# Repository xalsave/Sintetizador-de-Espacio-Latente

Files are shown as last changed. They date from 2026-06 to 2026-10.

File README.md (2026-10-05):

# Sintetizador de Espacio Latente

> Sintetizador digital embebido que genera timbres mediante interpolación
> neuronal de wavetables. Trabajo Fin de Grado, Grado en Ingeniería de
> Tecnologías y Servicios de Telecomunicación (GTIST), Universitat Politècnica
> de València.

<p align="center">
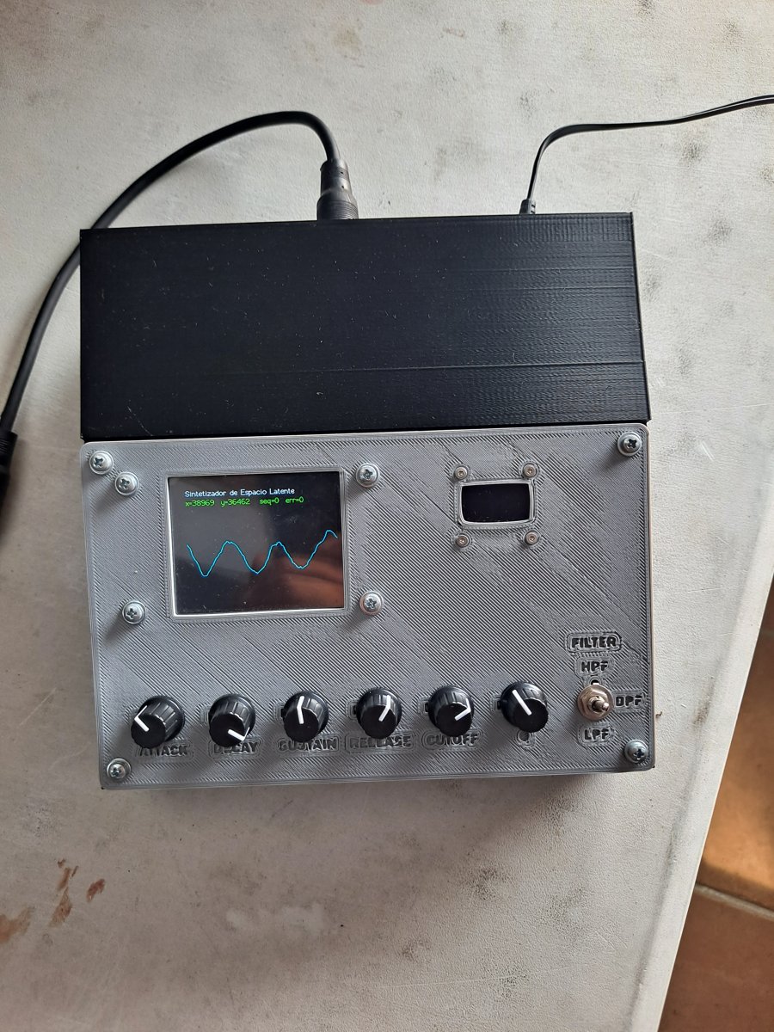
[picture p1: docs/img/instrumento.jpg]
El instrumento terminado: pantalla táctil, OLED y panel de mandos sobre una carcasa impresa en 3D
  
</p>

📄 **Memoria completa del TFG:** [Desarrollo de un sintetizador de sonido embebido basado en síntesis wavetable e inteligencia artificial (PDF)](memoria_tfg.pdf)

---

## Resumen

Este proyecto desarrolla un instrumento musical electrónico autónomo que
utiliza un **autoencoder variacional (VAE)** para organizar un corpus de
formas de onda de un ciclo en un **espacio latente bidimensional continuo**.
El intérprete navega por ese espacio tocando un punto en una pantalla táctil;
el sistema sintetiza en tiempo real una wavetable interpolada entre las
formas de onda aprendidas y la reproduce con control MIDI desde un teclado.

A diferencia de los sintetizadores wavetable tradicionales, donde el intérprete
selecciona una de N tablas predefinidas, este sistema permite explorar de
forma continua un mapa de timbres donde **cada punto produce una onda
distinta**. Las tablas salen del decoder del modelo aprendido, que se ejecuta
una sola vez en el ordenador; en el instrumento solo hay consulta de tabla e
interpolación.

---

## Demostración del concepto

<p align="center">
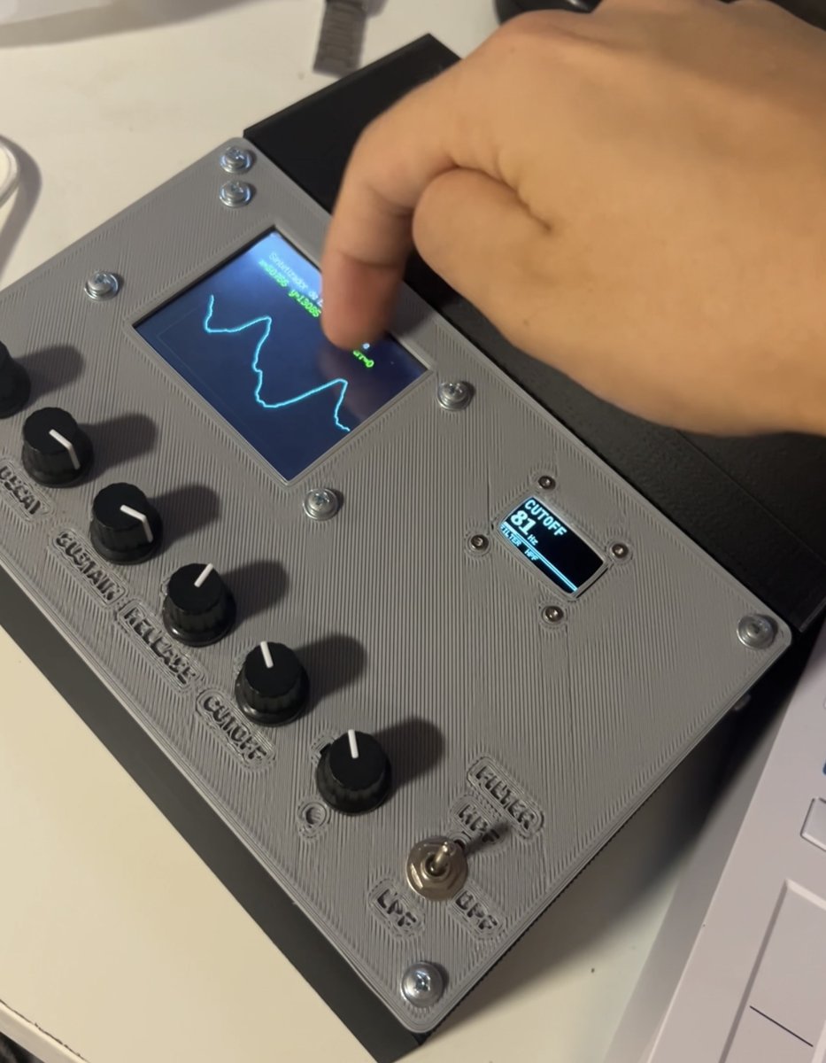
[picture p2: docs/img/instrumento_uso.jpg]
Un dedo recorre la pantalla táctil mientras se dibuja la onda resultante
  
</p>

El intérprete recorre el plano con el dedo y oye el timbre transformarse de
forma continua entre todas las familias del dataset (cuerdas, vientos,
sintéticos, ruidos, etc.) sin saltos perceptibles. La pantalla dibuja la onda
que está sonando y el OLED muestra el último mando movido.

---

## Arquitectura del sistema

Tres microcontroladores con roles especializados, comunicados por buses
serie estándar:

<p align="center">
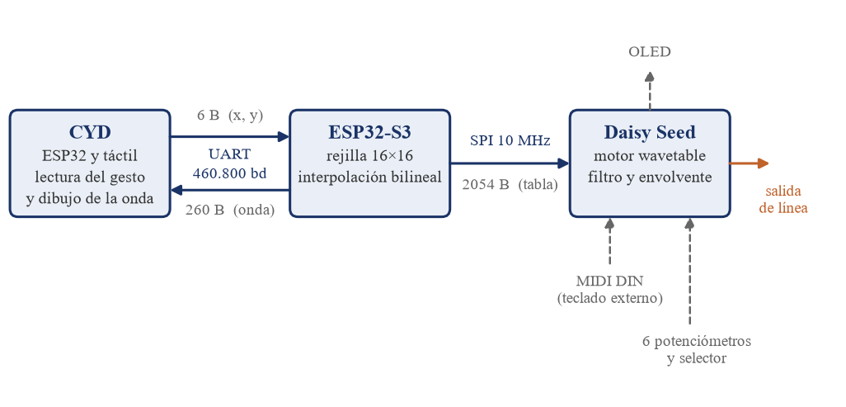
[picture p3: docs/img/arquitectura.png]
Diagrama de bloques: CYD, ESP32-S3 y Daisy Seed, con MIDI, panel y salida de audio
  
</p>

| Subsistema | Hardware | Función |
|---|---|---|
| Interfaz táctil  | CYD (ESP32-2432S028R) | Pantalla TFT 2.8" + táctil resistivo XPT2046  |
| Cerebro | ESP32-S3 N16R8 | Grid 16×16 en flash, interpolación bilineal |
| Motor de audio | Daisy Seed (STM32H750) | Síntesis, filtro, envolvente, MIDI, audio out |
| Control MIDI | Arturia Keystep MK2 | Teclado controlador por DIN |
| Panel analógico  | 6 potenciómetros + selector | ADSR, corte, resonancia y tipo de filtro |
| Display | OLED SSD1306 128×64 | Parámetro en edición y curva correspondiente  |

El enlace con la CYD es full-duplex: la coordenada táctil sube al ESP32-S3 en
una trama de 6 bytes, y el ESP32-S3 devuelve la onda resultante diezmada a 256
puntos de 8 bits para que la pantalla la dibuje. Esa onda de vuelta es dato de
representación, no de audio: la wavetable real de 1024 muestras solo viaja por
el SPI hacia el Daisy, en tramas de 2054 bytes protegidas con CRC16-CCITT.

---

## Cómo funciona

El sistema trabaja en dos fases: la red neuronal solo interviene en la de
preparación, en el ordenador, y el instrumento se limita a leer lo que ella
dejó horneado.

<p align="center">
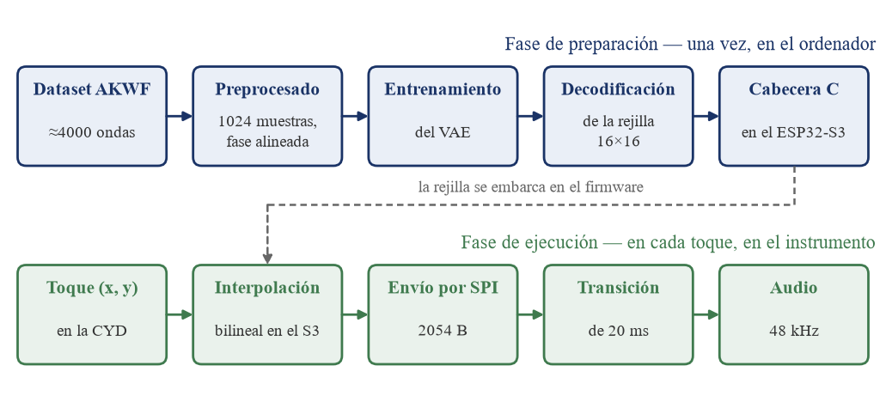
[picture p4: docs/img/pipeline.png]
Las dos fases: preparación en el ordenador y ejecución en el instrumento
  
</p>

### Fase offline (preparación, en PC)

1. **Preprocesado del dataset.** Se cargan las 4358 wavetables del corpus AKWF
   (Adventure Kid Waveforms), se remuestrean de 600 a 1024 muestras por FFT, se
   elimina la componente continua, se alinea el armónico fundamental a fase 0 y
   se normaliza por pico.
2. **Entrenamiento del VAE.** Autoencoder variacional totalmente conectado en
   PyTorch, con encoder 1024 → 512 → 128 → latente 2D y decoder espejo. La
   pérdida combina error cuadrático de reconstrucción y divergencia KL con un
   peso pequeño y rampa de calentamiento.

<p align="center">
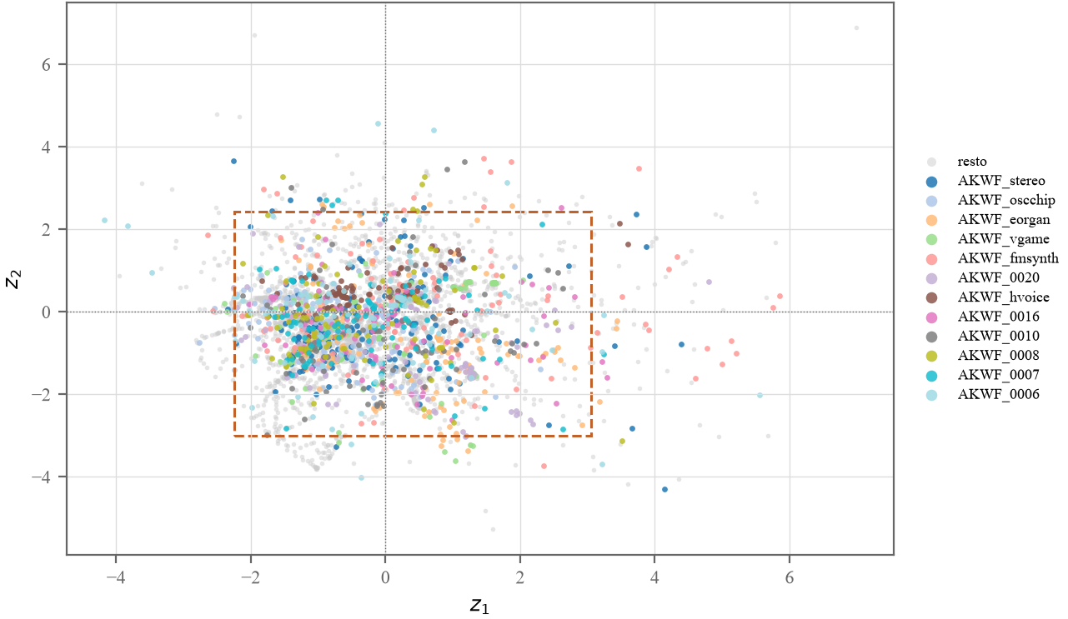
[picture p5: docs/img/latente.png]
Espacio latente 2D: cada punto es una onda del dataset, coloreada por familia
  
  <br>
  <em>Espacio latente aprendido. Cada punto es una onda del corpus; el rectángulo a trazos delimita los percentiles 2 y 98 de cada eje, la zona que se muestrea para la rejilla.</em>
</p>

<p align="center">
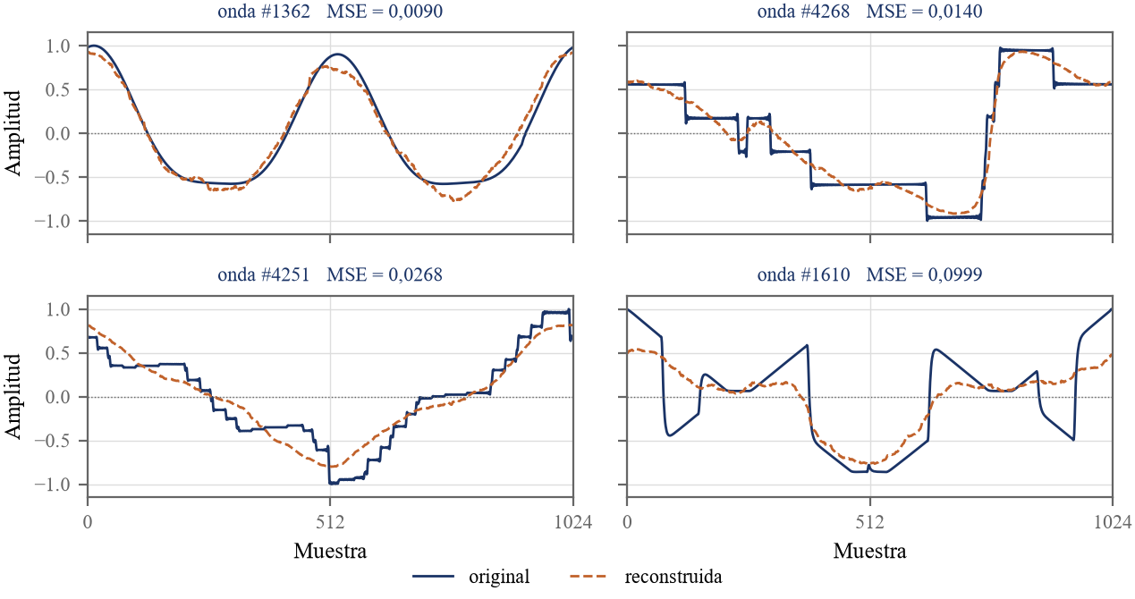
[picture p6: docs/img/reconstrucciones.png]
Cuatro ondas originales frente a su reconstrucción por el VAE
  
  <br>
  <em>Ondas originales frente a su reconstrucción. El cuello de botella de dos dimensiones conserva la forma general y redondea los flancos verticales.</em>
</p>

3. **Horneado del grid.** Se acota la zona poblada del latente por percentiles,
   se muestrea una rejilla regular de 16×16 = 256 puntos, se decodifica una
   wavetable en cada nodo y se exporta el banco como header de C en formato Q15,
   unos 512 KB en la flash del ESP32-S3.

<p align="center">
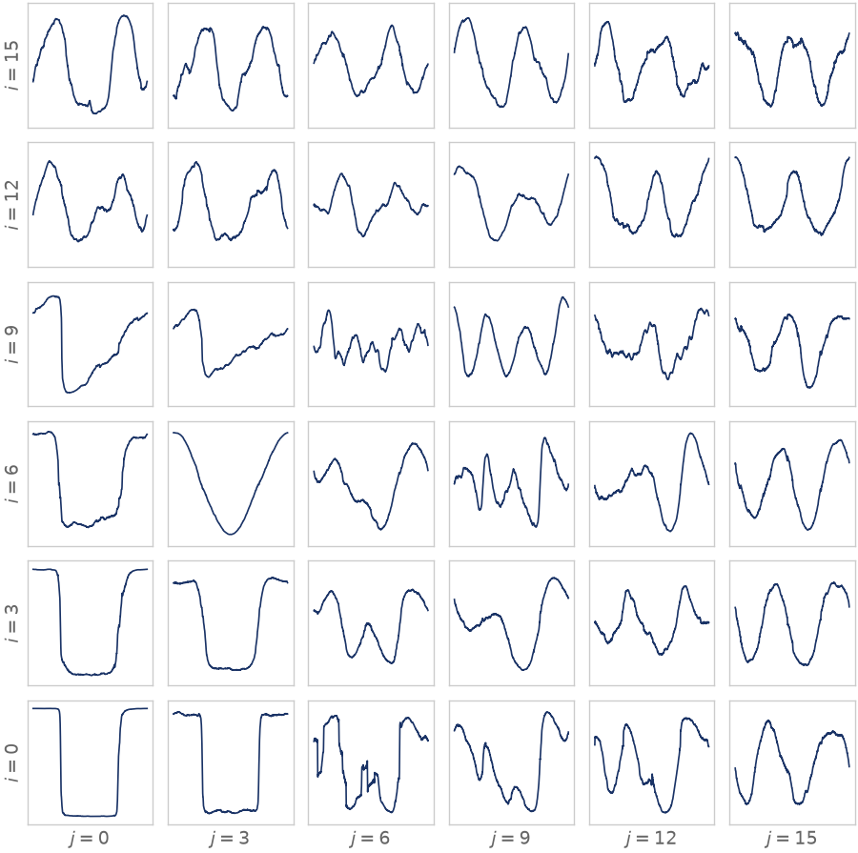
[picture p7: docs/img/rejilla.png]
Muestra de las ondas de la rejilla 16×16, una de cada tres filas y columnas
  
  <br>
  <em>Contenido de la rejilla, uno de cada tres nodos en cada eje: la variedad de formas repartida por el plano.</em>
</p>

La red **no se ejecuta en el instrumento**. Toda la inferencia ocurre en esta
fase, de modo que en vivo no hay latencia de modelo.

### Fase en vivo (en el instrumento)

1. La CYD lee el punto tocado, lo normaliza al rango completo de 16 bits y envía
   la coordenada por UART al ESP32-S3.
2. El ESP32-S3 localiza la celda del grid e **interpola bilinealmente** entre
   las cuatro wavetables vecinas, produciendo una onda suave para cualquier
   coordenada continua.
3. La wavetable resultante viaja por SPI al Daisy Seed.
4. El Daisy mantiene un **doble buffer** y aplica un **crossfade de 20 ms** al
   recibir una tabla nueva, lo que elimina los clicks de cambio.
5. Un acumulador de fase con interpolación lineal entre muestras reproduce la
   tabla a la frecuencia que indica el MIDI entrante del Keystep. La señal pasa
   por un filtro variable de estado y una envolvente ADSR, y sale por el códec
   del Daisy a un jack de 3.5 mm.

<p align="center">
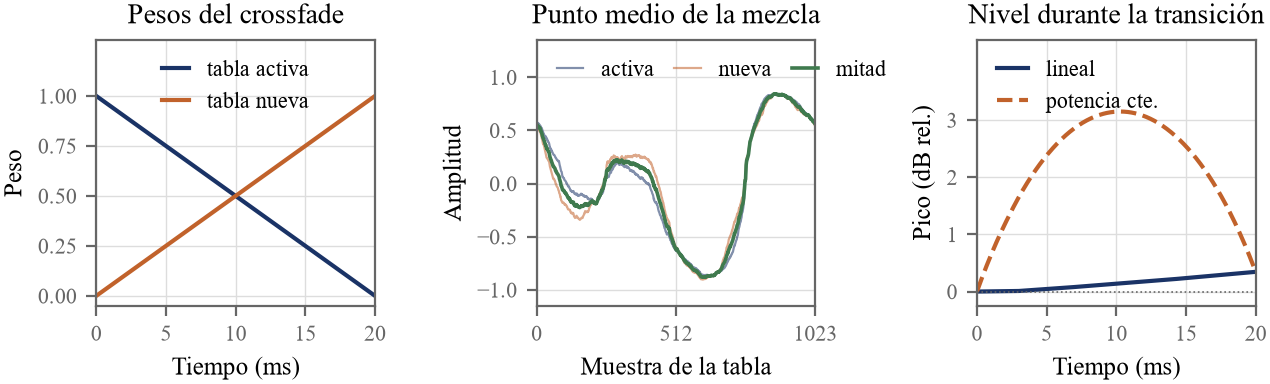
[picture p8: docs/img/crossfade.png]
Pesos del crossfade, punto medio de la mezcla y nivel durante la transición
  
  <br>
  <em>Transición entre dos tablas contiguas: pesos del fundido lineal, onda a mitad de mezcla y nivel de pico durante los 20 ms.</em>
</p>

### Panel de control

El Daisy lee siete canales analógicos: los cuatro tiempos y niveles del ADSR,
la frecuencia de corte, la resonancia y un selector de tres posiciones que
escoge entre filtro paso bajo, paso banda y paso alto. El OLED muestra el
último mando movido con su valor en unidades reales y la curva correspondiente,
la envolvente o la respuesta del filtro.

---

## Hardware

Las placas y el resto de componentes se montan sobre veroboard, con los
módulos en zócalos, y todo se alimenta desde una única fuente de 5 V. La
carcasa y el panel frontal están modelados de forma paramétrica en OpenSCAD e
impresos en 3D.

<p align="center">
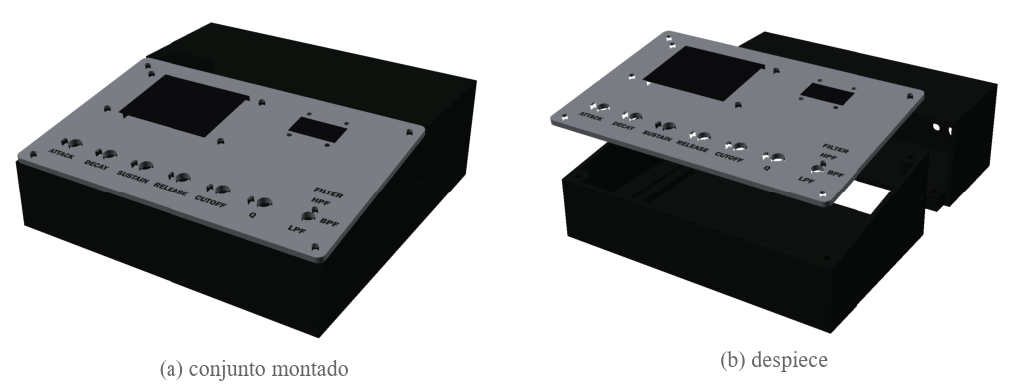
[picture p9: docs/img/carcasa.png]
Render de la carcasa: conjunto montado y despiece
  
</p>

---

## Estructura del repositorio

```
Sintetizador-de-Espacio-Latente/
├── ml/
│   ├── dataset/              # Corpus AKWF (.wav) y dataset procesado (.npy)
│   ├── scripts/              # Pipeline numerado por orden de ejecución
│   └── exports/              # vae.pt, grid.npy, grid.h y figuras del modelo
├── firmware/
│   ├── cyd_ui/               # PlatformIO — pantalla táctil (ESP32-WROOM)
│   ├── esp32_control/        # PlatformIO — grid e interpolación (ESP32-S3)
│   └── daisy_dsp/            # libDaisy — síntesis, MIDI y panel (STM32H750)
├── hardware/
│   ├── cad/                  # Carcasa y panel en OpenSCAD
│   └── schematics/           # Cableado y veroboard en Fritzing
├── docs/
│   └── img/                  # Fotos y figuras de este README
├── memoria_tfg.pdf           # Memoria del TFG
├── LICENSE
└── README.md
```

El firmware del Daisy se compila desde el árbol de DaisyExamples; la copia de
`firmware/daisy_dsp/` es la fuente de referencia versionada.

---

## Reproducir el pipeline

Los scripts de `ml/scripts/` están numerados por orden de ejecución y se lanzan
desde la raíz del repositorio:

```bash
python ml/scripts/2_build_dataset.py    # AKWF -> akwf_processed.npy
```

```bash
python ml/scripts/3_train_vae.py        # entrena el VAE -> vae.pt
```

```bash
python ml/scripts/4_bake_grid.py        # decodifica el grid -> grid.npy y grid.h
```

```bash
python ml/scripts/5_demo_morph.py       # demo del morphing con ratón, en PC
```

Requiere Python 3.10 o superior con PyTorch, NumPy, SciPy, Matplotlib y
`sounddevice` para la demo. El entrenamiento aprovecha CUDA si está disponible.

### Validación cruzada

Cada enlace de la cadena se comprueba contra una referencia calculada en NumPy,
en lugar de fiarlo al oído:

- `6_validate_s3.py` recalcula en el PC la wavetable que el ESP32-S3 volcó por
  serie y las compara muestra a muestra.
- `7_validate_spi.py` comprueba que lo que reproduce el Daisy es exactamente lo
  que el ESP32-S3 envió por SPI.
- `8_validate_midi.py` contrasta la tabla de conversión de nota MIDI a
  frecuencia y a incremento de fase del firmware con la fórmula teórica.
- `8b_monitor_midi.py` muestra en vivo los eventos que procesa el Daisy.

---

## Stack tecnológico

- **Machine learning:** Python 3.10+, PyTorch, NumPy, SciPy, Matplotlib
- **Firmware Daisy:** C++ con libDaisy y DaisySP, ARM GCC, flasheo por DFU
- **Firmware ESP32-S3 y CYD:** C++ sobre Arduino con PlatformIO
- **Comunicación:** UART 8N1 a 460800 baud entre CYD y ESP32-S3; SPI a 10 MHz
  en modo 0 entre ESP32-S3 y Daisy; MIDI DIN por USART1 con optoacoplador 6N138
- **Audio:** códec del Daisy a 48 kHz, señal mono replicada en ambos canales
- **Hardware:** veroboard, carcasa impresa en 3D modelada en OpenSCAD

---

## Estado del proyecto

**Completado.** El instrumento está montado, flasheado y verificado como
unidad, con los tres microcontroladores, el panel analógico, el display y la
carcasa definitiva. La memoria del TFG está en la raíz del repositorio, en
[PDF](memoria_tfg.pdf).

El decoder neuronal embarcado en el ESP32-S3 mediante TensorFlow Lite Micro se
estudió como ampliación y queda documentado como línea de trabajo futuro: la
versión final resuelve el timbre por interpolación bilineal sobre el grid
precalculado, que era el camino crítico del proyecto.

---

## Referencias

El proyecto se apoya en literatura previa de síntesis neuronal de audio:

- **Hantrakul & Yang (2018).** *Neural Wavetable: a playable wavetable
  synthesizer using neural networks.*
- **Engel et al. (Magenta, 2020).** *DDSP: Differentiable Digital Signal
  Processing.*
- **Caillon & Esling (IRCAM, 2021).** *RAVE: A variational autoencoder
  for fast and high-quality neural audio synthesis.*
- **Wavespace (2024).** *VAE-based wavetable generation with factorized
  latent space.*

La aportación diferencial de este TFG no reside en la técnica de interpolación
neuronal, ya explorada en plugins de DAW, sino en su **integración embebida
completa en tiempo real**, sobre hardware de bajo coste y con interfaz física
táctil y MIDI, llevando la idea de plugin de software a instrumento físico
autónomo.

---

## Autor

**Alejandro Saez Vega**
Grado en Ingeniería de Tecnologías y Servicios de Telecomunicación
Universitat Politècnica de València

Tutor del TFG: José Javier López Monfort

---

## Licencia

Código fuente bajo licencia MIT. Ver `LICENSE`.

El dataset AKWF (Adventure Kid Waveforms) se distribuye bajo Creative Commons
Zero (CC0) y se incluye en `ml/dataset/` para que el pipeline sea reproducible
tal cual. Su origen es [la web del autor](https://www.adventurekid.se/).

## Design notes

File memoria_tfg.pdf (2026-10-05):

# UNIVERSITAT POLITÈCNICA DE VALÈNCIA

# Escuela Técnica Superior de Ingeniería de Telecomunicación

# Desarrollo de un sintetizador de sonido embebido basado en síntesis wavetable e inteligencia artificial

# Trabajo Fin de Grado

# Grado en Ingeniería de Tecnologías y Servicios de Telecomunicación

## AUTOR/A: Saez Vega, Alejandro

## Tutor/a: López Monfort, José Javier

## CURSO ACADÉMICO: 2025/2026

## Resumen

Este Trabajo Fin de Grado presenta el diseño, construcción y validación de un sintetizador de sonido digital autónomo que combina la síntesis wavetable con un modelo de aprendizaje profundo. El usuario explora de forma continua un espacio de timbres aprendido con el dedo sobre una pantalla táctil, mientras toca las notas desde un teclado MIDI convencional.

El trabajo se divide en dos fases. En la primera, realizada en el ordenador, se entrena un autoencoder variacional con espacio latente bidimensional sobre un conjunto público de 4358 formas de onda de un ciclo, y con su decodificador se genera una rejilla de 256 tablas que se exporta al sistema embebido. En la segunda, el instrumento no ejecuta ninguna red: un ESP32-S3 interpola entre las tablas y una placa Daisy Seed, basada en un Cortex-M7, reproduce el resultado en tiempo real con transiciones sin discontinuidades, envolvente ADSR y filtro gobernados desde un panel analógico.

El prototipo se integra en una carcasa impresa en 3D con alimentación única. La cadena de datos se verifica muestra a muestra contra una referencia calculada en el ordenador y el aparato se caracteriza eléctricamente. Se recogen también las limitaciones encontradas y las líneas de continuación.

## Resum

Aquest Treball Final de Grau presenta el disseny, la construcció i la validació d’un sintetitzador de so digital autònom que combina la síntesi wavetable amb un model d’aprenentatge profund. L’usuari explora de manera contínua un espai de timbres aprés amb el dit sobre una pantalla tàctil, mentre toca les notes des d’un teclat MIDI convencional.

El treball es divideix en dues fases. En la primera, feta a l’ordinador, s’entrena un autoencoder variacional amb espai latent bidimensional sobre un conjunt públic de 4358 formes d’ona d’un cicle, i amb el seu descodificador es genera una graella de 256 taules que s’exporta al sistema encastat. En la segona, l’instrument no executa cap xarxa: un ESP32-S3 interpola entre les taules de la graella i una placa Daisy Seed, basada en un Cortex-M7, reprodueix el resultat en temps real amb transicions sense discontinuïtats, envolupant ADSR i filtre governats des d’un panell analògic.

El prototip s’integra en una carcassa impresa en 3D amb alimentació única. La cadena de dades es verifica mostra a mostra contra una referència calculada a l’ordinador i l’aparell es caracteritza elèctricament. S’arrepleguen també les limitacions trobades i les línies de continuació.

## Abstract

This Bachelor’s Thesis presents the design, construction and validation of a stand-alone digital sound synthesizer that combines wavetable synthesis with a deep learning model. The user explores a learned timbre space continuously with a finger on a touch screen, while playing notes from a conventional MIDI keyboard.

The work is divided into two phases. In the first, carried out on a computer, a variational autoencoder with a two-dimensional latent space is trained on a public set of 4358 single-cycle waveforms, and its decoder is used to bake a grid of 256 tables that is exported to the embedded system. In the second, the instrument runs no neural network at all: an ESP32-S3 interpolates between the tables of the grid, and a Daisy Seed board, built around a Cortex-M7, plays the result in real time with click-free table transitions, an ADSR envelope and a filter driven from an analogue control panel.

The prototype is housed in a 3D-printed enclosure with a single power supply. The data chain is verified sample by sample against a reference computed on the PC, and the device is characterised electrically. The limitations found and the lines of future work are also reported.

3

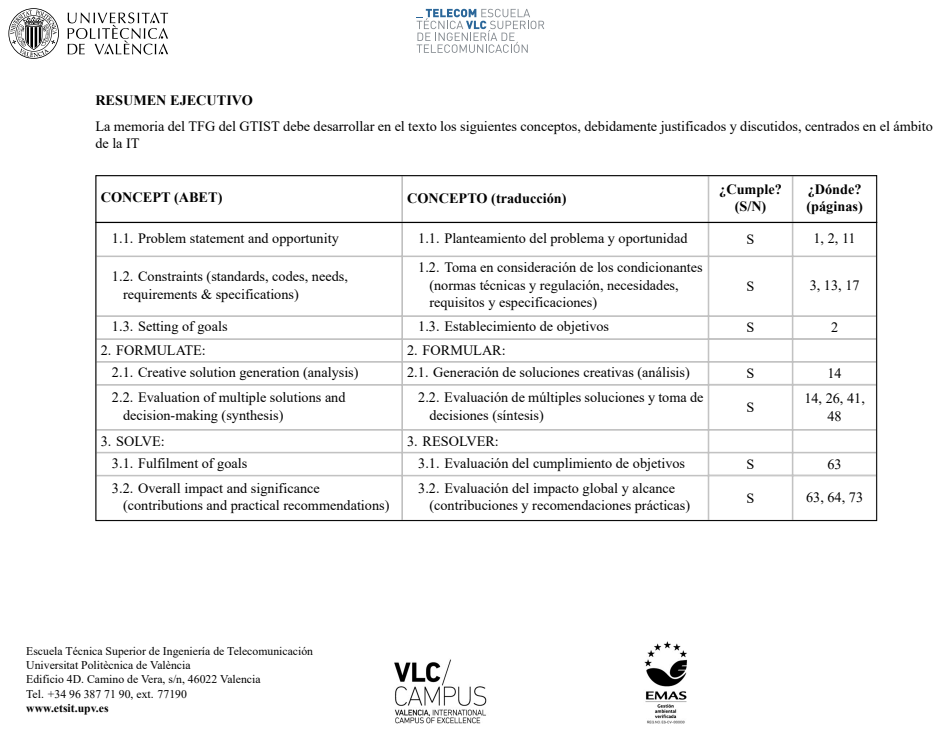
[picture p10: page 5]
RESUMEN EJECUTIVO; CONCEPT (ABET); CONCEPTO (traducción); ¿Cumple? (S/N); ¿Dónde? (páginas); 1.1. Problem statement and opportunity; 1.1. Planteamiento del problema y oportunidad; 1.3. Setting of goals; 1.3. Establecimiento de objetivos; 2. FORMULATE:; 2. FORMULAR:; 2.1. Creative solution generation (analysis); 2.1. Generación de soluciones creativas (análisis); decisiones (síntesis); 3. SOLVE:; 3. RESOLVER:; 3.1. Fulfilment of goals; 3.1. Evaluación del cumplimiento de objetivos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

La memoria del TFG del GTIST debe desarrollar en el texto los siguientes conceptos, debidamente justificados y discutidos, centrados en el ámbito

1.2. Toma en consideración de los condicionantes
(normas técnicas y regulación, necesidades,
requisitos y especificaciones)

1.2. Constraints (standards, codes, needs,
requirements & specifications)

2.2. Evaluation of multiple solutions and
decision-making (synthesis)

2.2. Evaluación de múltiples soluciones y toma de

3.2. Overall impact and significance
(contributions and practical recommendations)

3.2. Evaluación del impacto global y alcance

Escuela Técnica Superior de Ingeniería de Telecomunicación
Universitat Politècnica de València
Edificio 4D. Camino de Vera, s/n, 46022 Valencia
Tel. +34 96 387 71 90, ext. 77190
www.etsit.upv.es

A Juan, Soledad, Eva y Claudia por ser pilares fundamentales en mi vida.

A Jorge y Paulina, por hacer de la carrera algo que siempre recordaré con cariño.

Y a todos los que, de una forma u otra, me inspiraron a unir la ingeniería y el arte.

# Índice

I Memoria

1 Introducción | 1
2 Marco teórico y estado del arte | 5
3 Diseño del sistema | 13
4 Modelo neuronal | 21

5 Firmware de control: ESP32-S3 y CYD | 31
6 Firmware de audio: Daisy Seed | 39
7 Hardware y alimentación | 47
8 Pruebas y resultados | 55
9 Conclusiones y trabajo futuro | 63
Bibliografía | 67

ÍNDICE

II Anexos

A Presupuesto de materiales | 71
B Relación con los Objetivos de Desarrollo Sostenible | 73

8

# Índice de figuras

2.1 Envolvente ADSR. Los dos primeros tramos duran un valor fijo. El tercer tramo depende de cuánto tiempo se mantenga pulsada la tecla. La liberación empieza al
soltarla | 6
2.2 Respuesta en magnitud de un filtro paso bajo, uno paso alto y uno paso banda
de segundo orden, todos con la frecuencia de corte en 1 kHz y factor de calidad
Q = 0,707 | 7
2.3 Lectura de una tabla de ondas. A la izquierda, la tabla almacenada y la posición actual del acumulador de fase φ. A la derecha, el detalle de la interpolación lineal
entre las dos muestras vecinas | 8

3.1 Arquitectura del sistema. Las flechas continuas son los enlaces digitales entre placas, rotuladas con el medio y el tamaño de la trama; las discontinuas, los periféricos
del procesador de audio | 15
3.2 Las dos fases de operación. La red neuronal solo interviene en la fase de preparación; durante la ejecución el instrumento se limita a consultar la rejilla, mezclar y
reproducir | 17

4.1 Invarianza de la alineación al punto de arranque. La misma onda desplazada 0, 137, 411 y 700 muestras produce cuatro curvas distintas; tras llevar el fundamental
a fase cero, las cuatro quedan superpuestas | 23
4.2 Evolución del error de reconstrucción y de la divergencia de Kullback-Leibler a lo largo de las 300 épocas. La línea de puntos del panel izquierdo marca el momento
en que la validación deja de mejorar; la del derecho, el final de la rampa de β. . . 25 4.3 Espacio latente aprendido. Cada punto es la media de la distribución que el codificador asigna a una onda. El rectángulo a trazos delimita los percentiles 2 y 98 de
cada eje | 26
4.4 Cuatro ondas del conjunto de entrenamiento frente a su reconstrucción, con el error cuadrático medio de cada una. La pérdida de detalle se concentra en los flancos
verticales | 27
4.5 Contenido de la rejilla, dibujando uno de cada tres nodos en cada eje para que las ondas resulten legibles. El submuestreo permite ver la variedad de formas repartida
por el plano, no la semejanza entre celdas contiguas | 29

5.1 Las dos ventanas del táctil sobre el plano de cuentas crudas del convertidor. La de captura decide qué toques valen y es la que se mapea al rango de la coordenada; la visible solo sirve para acotar el área de dibujo. La pulsación fantasma medida cae
dentro de la visible y fuera de la de captura | 33

5.2 Interpolación bilineal para la coordenada (40000, 12000). A la izquierda, la celda alcanzada, los índices de las cuatro vecinas en la rejilla y el peso que recibe cada
una. A la derecha, esas cuatro formas de onda y la que resulta de mezclarlas. . . 34 5.3 Reducción de 1024 a 256 puntos para dibujar, sobre el nodo de la rejilla en el
que más se separan los dos métodos. Promediar cada grupo de cuatro muestras
y quedarse con una de cada cuatro dan prácticamente lo mismo en el grueso del
ciclo, y difieren en los flancos | 35

6.1 Estructura del firmware de audio y los tres ritmos a los que trabaja. Las flechas continuas son la cadena de audio, muestra a muestra; las discontinuas, la informa-
ción que cruza de un ritmo a otro | 40
6.2 La transición entre dos ondas de celdas contiguas de la rejilla, las mismas que alcanza la coordenada del apartado 5.3. A la izquierda, los pesos a lo largo de los
20 ms. En el centro, las dos tablas y su mezcla a mitad de camino. A la derecha,
el nivel de pico durante la transición con mezcla lineal y con mezcla de potencia
constante | 42
6.3 A la izquierda, un giro rápido del mando de corte tal y como lo entrega el conversor bloque a bloque, y el mismo giro tras el filtro de un polo. A la derecha, el recorrido
del mando llevado a hercios con el mapeo exponencial y con uno lineal | 44

7.1 Esquema de la alimentación. El condensador de reserva C4 queda aguas arriba del interruptor y la rama del procesador de audio es la única con elemento en serie. . 48 7.2 Trazado de la placa. Los dos módulos van sobre zócalos, la alimentación ocupa el extremo libre de los raíles y todo lo que el usuario toca sube al panel por el mazo. 51 7.3 Alzado del panel frontal. El trazo discontinuo es el contorno de las dos placas, que quedan por detrás; el continuo, lo que se ve desde fuera. Cotas en milímetros. . . 52 7.4 La carcasa, renderizada desde el modelo paramétrico. A la izquierda el conjunto montado; a la derecha el despiece, con el panel separado de la bandeja y las dos
piezas de la trasera | 54
7.5 El instrumento terminado. A la izquierda, el panel de control con los seis mandos,
el selector de tipo de filtro y los huecos de las dos pantallas. A la derecha, en funcionamiento: el dedo fija el punto del espacio latente, la pantalla táctil dibuja
la forma de onda que se genera en ese punto y el display de servicio muestra el
parámetro que se está editando | 54

# Índice de tablas

3.1 Parámetros de diseño fijados antes de la implementación | | 18
3.2 Enlaces de comunicación entre placas | | 18
4.1 Configuración del autoencoder variacional y del entrenamiento | | 24
7.1 Componentes del instrumento | | 48
8.1 Validación de la cadena de datos frente a una referencia calculada en el ordenador. | 56
8.2 Continuidad y resistencia, con el instrumento sin alimentar. El valor neto descuenta los 0,7 Ω de las puntas. OL indica fuera de escala, es decir, del orden de los
megaohmios | 56
8.3 Tensiones continuas referidas a masa, en reposo y en el peor caso. El guion indica
un nodo que no se repitió en la segunda pasada | | 57
8.4 Consumo del instrumento | | 58
8.5 Salida de audio en el jack sin carga. Los valores en dBV se refieren a un voltio
eficaz | | 59
A.1 Presupuesto de materiales del instrumento | | 71
B.1 Grado de relación del trabajo con los Objetivos de Desarrollo Sostenible | | 73

# Glosario

ADC Analog-to-Digital Converter. Conversor analógico-digital.

ADSR Attack, Decay, Sustain, Release. Ataque, decaimiento, sostenimiento y liberación.

AKWF Adventure Kid Waveforms. Corpus público de formas de onda de un ciclo.

BPF Band-Pass Filter. Filtro paso banda.

CRC Cyclic Redundancy Check. Comprobación de redundancia cíclica.

CYD Cheap Yellow Display. Nombre habitual de la placa ESP32-2432S028R, que integra un ESP32 y una pantalla táctil.

DAC Digital-to-Analog Converter. Conversor digital-analógico.

DAW Digital Audio Workstation. Estación de trabajo de audio digital.

DMA Direct Memory Access. Acceso directo a memoria.

DSP Digital Signal Processing. Procesado digital de señal.

FFT Fast Fourier Transform. Transformada rápida de Fourier.

FPU Floating-Point Unit. Unidad de coma flotante.

GPIO General Purpose Input/Output. Entrada/salida de propósito general.

GPU Graphics Processing Unit. Unidad de procesamiento gráfico.

HPF High-Pass Filter. Filtro paso alto.

I

2C Inter-Integrated Circuit. Bus serie síncrono de dos hilos.

I

2S Inter-IC Sound. Bus serie para transmisión de audio digital.

LPF Low-Pass Filter. Filtro paso bajo.

LSB Least Significant Bit. Bit menos significativo.

MCU Microcontroller Unit. Microcontrolador.

MIDI Musical Instrument Digital Interface. Protocolo de comunicación entre instrumentos musicales electrónicos.

MSE Mean Squared Error. Error cuadrático medio.

OLED Organic Light Emitting Diode. Diodo orgánico emisor de luz, empleado en pantallas.

PSRAM Pseudo-Static Random Access Memory. Memoria de acceso aleatorio pseudoestática.

RMS Root Mean Square. Valor eficaz o media cuadrática.

SPI Serial Peripheral Interface. Bus serie síncrono maestro-esclavo.

SVF State Variable Filter. Filtro de variables de estado.

TFT Thin-Film Transistor. Transistor de película fina, tecnología de las pantallas de matriz activa.

UART Universal Asynchronous Receiver-Transmitter. Transmisor-receptor asíncrono universal.

USB Universal Serial Bus. Bus serie universal.

VAE Variational Autoencoder. Autoencoder variacional.

# Parte I

# Memoria

# Capítulo 1

# Introducción

Todo el material de este trabajo está publicado en un repositorio de acceso libre. Incluye los guiones de preparación del conjunto de datos y de entrenamiento del modelo, el firmware de las tres placas, los ficheros paramétricos de la carcasa y las fuentes de este documento. https://github.com/xalsave/Sintetizador-de-Espacio-Latente

## 1.1 Contexto y planteamiento del problema

La síntesis wavetable es una de las técnicas más extendidas en los instrumentos musicales electrónicos actuales. Su principio es sencillo, en lugar de calcular la forma de onda muestra a muestra mediante una expresión matemática, se almacena un ciclo completo de la onda en una tabla y se recorre esa tabla a la velocidad a la que se quiere reproducir la nota. El coste computacional es bajo y el control sobre el timbre es directo, ya que basta con sustituir el contenido de la tabla para obtener un sonido distinto.

El problema aparece al intentar pasar de un timbre a otro de forma continua. Un banco de wavetables es un conjunto discreto, contiene las ondas que contiene y nada más. Promediar dos de ellas sin ningún criterio previo no produce un timbre intermedio convincente, sino cancelaciones entre armónicos que suenan a filtro de peine, porque las dos ondas no comparten una referencia de fase común. Tampoco existe una noción evidente de cercanía entre ondas. Dado un banco de varios miles de formas de onda no hay una ordenación natural que sitúe juntas las que suenan parecido.

Los autoencoders ofrecen una vía para resolver las dos cosas a la vez. Un autoencoder es una red neuronal formada por dos mitades: un codificador, que comprime cada onda a un número reducido de valores; y un decodificador, que reconstruye la onda a partir de esos valores. El conjunto de valores intermedios recibe el nombre de espacio latente. Si ese espacio se restringe a dos dimensiones, cada onda de un conjunto queda situada en un punto de un plano, y las ondas de sonido parecido tienden a agruparse. La variante variacional del autoencoder añade una condición adicional sobre la organización de ese plano. Lo obliga a ser continuo, sin huecos ni saltos bruscos. La consecuencia práctica es que el decodificador puede generar una forma de onda con sentido para cualquier punto del plano, incluidos los que no corresponden a ninguna onda del conjunto original. Ahí es donde nacen los timbres intermedios que un banco discreto no puede proporcionar.

1

CAPÍTULO 1. INTRODUCCIÓN

Un plano continuo de dos dimensiones es, además, exactamente lo que un dedo puede controlar sobre una pantalla táctil. Esa coincidencia entre la dimensión del espacio aprendido y la del gesto de control es la que da sentido al instrumento que se plantea en este trabajo.

## 1.2 Motivación y oportunidad

La idea de generar wavetables mediante redes neuronales no es nueva. Existen trabajos previos que aplican autoencoders a la generación e interpolación de formas de onda de un ciclo, así como sistemas de síntesis neuronal en tiempo real capaces de funcionar sobre hardware de propósito general. Todos ellos, sin embargo, comparten un rasgo común: se materializan como aplicaciones de escritorio o como complementos para estaciones de trabajo de audio digital. El sonido se genera en un ordenador.

La oportunidad que aborda este trabajo es distinta. Se trata de llevar ese mismo concepto a un instrumento físico autónomo basado en microcontroladores de bajo coste que generen el audio en su propio hardware y respondan a un gesto táctil y a un teclado MIDI sin necesidad de un ordenador conectado. La aportación no está, por tanto, en la interpolación neuronal en sí, sino en su integración embebida completa en tiempo real. En resolver el reparto de tareas entre procesadores, la comunicación entre ellos, la latencia, la estabilidad del audio y la construcción del prototipo.

Esa integración impone una restricción que condiciona todo el diseño y que conviene enunciar desde el principio: la red neuronal no puede ejecutarse a frecuencia de audio. Generar 48.000 muestras por segundo mediante inferencia neuronal queda fuera del alcance de un microcontrolador de estas características. Ahora bien, la red no necesita trabajar a esa velocidad. Solo tiene que producir una forma de onda nueva cuando el usuario mueve el dedo, es decir, unas pocas decenas de veces por segundo. La reproducción de esa onda a 48 kHz es una operación aritmética elemental. Separar la generación de la tabla, lenta y esporádica, de su reproducción, rápida y continua, es lo que hace viable el sistema completo.

Desde el punto de vista académico, el trabajo integra contenidos de procesamiento digital de señal, aprendizaje automático, sistemas embebidos, protocolos de comunicación entre dispositivos y diseño electrónico. Es una gran oportunidad para aplicar transversalmente todos los conocimientos y competencias adquiridos en el grado.

## 1.3 Objetivos

El objetivo general es diseñar, construir y validar un sintetizador digital embebido y autónomo que permita explorar de forma continua un espacio tímbrico aprendido por un autoencoder, empleando una pantalla táctil como superficie de control y una entrada MIDI estándar para la ejecución musical.

De este objetivo general se derivan los siguientes objetivos específicos:

- Construir un conjunto de datos homogéneo a partir de un conjunto de datos público de formas de onda de un ciclo, resolviendo el remuestreo, la normalización de amplitud y la alineación de fase necesarias para que la interpolación posterior no introduzca artefactos.

2

1.4. ALCANCE Y CONDICIONANTES
- Entrenar un autoencoder variacional que comprima cada forma de onda a una coordenada bidimensional y verificar que el espacio latente resultante es continuo y está bien aprovechado.
- Precalcular, a partir del decodificador entrenado, una rejilla de formas de onda que pueda embarcarse en el sistema y exportarla en un formato adecuado para un microcontrolador.
- Implementar un motor de síntesis wavetable en tiempo real capaz de sustituir la tabla en reproducción sin discontinuidades audibles.
- Resolver la comunicación entre los tres microcontroladores que componen el sistema, definiendo los protocolos y verificando que la información llega íntegra.
- Incorporar el control de nota y dinámica mediante MIDI, así como un panel de control analógico para los parámetros de envolvente y filtro.
- Validar cada etapa de forma objetiva, contrastando el comportamiento del sistema embebido con una implementación de referencia en el ordenador siempre que sea posible.
- Integrar el conjunto en un prototipo físico alimentado desde una fuente única, con su propia electrónica de soporte.

## 1.4 Alcance y condicionantes

El sistema se construye sobre tres microcontroladores con funciones separadas. Una pantalla táctil con controlador ESP32 integrado se encarga de la interfaz de usuario. Un ESP32-S3 aloja la rejilla de formas de onda y calcula la interpolación. Una placa Daisy Seed, basada en un procesador ARM Cortex-M7, genera el audio gracias a su DAC de 24 bits. El teclado que proporciona las notas se conecta por MIDI DIN y se considera un elemento externo e intercambiable, de forma que el entregable del trabajo es un módulo de sonido y no un instrumento con teclado integrado.

El alcance queda acotado por varios condicionantes que conviene dejar explícitos:

- La red neuronal no se ejecuta en el instrumento. El decodificador se emplea fuera de línea, en el ordenador, para generar por adelantado la rejilla de formas de onda que se embarca en el sistema. Durante la ejecución solo hay consulta de tabla e interpolación. Se trata de una estrategia de despliegue, no de una renuncia: es la consecuencia directa de la restricción enunciada en el apartado anterior.
- El espacio latente es bidimensional. Esta elección viene impuesta por el control táctil, pero supone un cuello de botella considerable para representar varios miles de formas de onda distintas. Su efecto sobre la fidelidad de la reconstrucción se mide y se discute en el capítulo sobre el modelo neuronal.
- El instrumento es monofónico. La polifonía no forma parte de los objetivos y se plantea únicamente como línea de trabajo futuro.
- El hardware es de bajo coste y de disponibilidad comercial. No se ha diseñado ni fabricado ningún circuito integrado específico, y el montaje final se resuelve sobre placa de tiras de cobre en lugar de sobre un circuito impreso fabricado, por restricciones de plazo.

3

CAPÍTULO 1. INTRODUCCIÓN

- La amplificación y el altavoz integrados quedan fuera del alcance. La salida del instrumento es una señal de línea por conector de 3,5 mm.

## 1.5 Estructura de la memoria

El presente documento se organiza en nueve capítulos.

El capítulo 1 sitúa el problema, expone la motivación del trabajo, fija los objetivos y delimita el alcance.

El capítulo 2 recoge los fundamentos teóricos necesarios para seguir el resto del documento y revisa los trabajos previos relacionados con sistemas de síntesis neuronal.

El capítulo 3 describe el diseño del sistema completo: el reparto de funciones entre los tres microcontroladores, los protocolos de comunicación entre ellos y la separación entre la fase de preparación fuera de línea y la de ejecución en tiempo real.

El capítulo 4 aborda la parte de aprendizaje automático, desde el preprocesado del conjunto de formas de onda hasta el entrenamiento del autoencoder y la generación de la rejilla que se embarca en el sistema.

Los capítulos 5 y 6 describen el desarrollo del firmware. El primero se ocupa de la cadena de entrada, formada por la pantalla táctil y el ESP32-S3, y el segundo del motor de audio implementado sobre la Daisy Seed.

El capítulo 7 trata la parte física del prototipo: la alimentación, el panel de control analógico y el montaje definitivo.

El capítulo 8 reúne las pruebas realizadas y los resultados obtenidos, tanto las medidas eléctricas como las verificaciones numéricas de cada etapa de la cadena de procesado.

El capítulo 9 recoge las conclusiones y plantea las líneas de trabajo futuro.

4

# Capítulo 2

# Marco teórico y estado del arte

Este capítulo reúne los conceptos necesarios para seguir el resto del documento. Se parte de los fundamentos de la síntesis de sonido, se detalla la técnica concreta sobre la que se construye el instrumento y se introducen los autoencoders y el espacio latente. El capítulo termina con una revisión de los trabajos previos que aplican redes neuronales a la generación de formas de onda, que es donde se sitúa la aportación de este trabajo.

## 2.1 Fundamentos de síntesis de sonido

Un sonido periódico queda descrito por tres magnitudes: la frecuencia fundamental, que determina la altura de la nota; la amplitud, que determina su intensidad; y el contenido armónico, que determina el timbre. Dos instrumentos que tocan la misma nota con la misma intensidad se distinguen precisamente por la distribución de energía entre los armónicos de esa fundamental. Estos armónicos dependen de características físicas del instrumento, como la forma de la caja de resonancia o la rigidez de las cuerdas. En la sintetización de sonido, en cambio, el timbre se genera mediante algoritmos que producen la señal de audio directamente, sin necesidad de un instrumento físico.

La síntesis de sonido agrupa las técnicas que permiten generar señales de audio por medios electrónicos. Las más habituales son las siguientes [1]:

- Síntesis aditiva. Construye el sonido sumando osciladores senoidales de distinta frecuencia y amplitud. Ofrece un control muy preciso del espectro, a costa de un coste computacional elevado cuando el número de frecuencias a sumar es alto.
- Síntesis sustractiva. Parte de una señal rica en armónicos y emplea filtros para eliminar las frecuencias no deseadas. Es la base de los sintetizadores analógicos clásicos y sigue vigente en los digitales.
- Síntesis por modulación de frecuencia. Modula la frecuencia de un oscilador con la salida de otro, generando espectros complejos con muy pocos operadores.
- Síntesis por tabla de ondas. Almacena en memoria uno o varios ciclos de forma de onda y los reproduce leyendo la tabla a la velocidad adecuada. Es la técnica sobre la que se construye este trabajo y se detalla en el apartado siguiente.

5

CAPÍTULO 2. MARCO TEÓRICO Y ESTADO DEL ARTE

Con independencia de la técnica empleada, un sonido musical necesita evolucionar en el tiempo. Una nota que se mantuviese con amplitud constante desde que se pulsa la tecla hasta que se suelta resultaría artificial. Esa evolución se controla mediante una envolvente, y la más extendida es la ADSR, que divide la vida de la nota en cuatro tramos:

- Ataque (Attack). El tiempo que tarda la señal en alcanzar su nivel máximo.
- Decaimiento (Decay). El tiempo que tarda en descender el nivel desde el pico máximo hasta el nivel de sostenimiento.
- Sostenimiento (Sustain). El nivel que se mantiene mientras la tecla siga pulsada.
- Liberación (Release). El tiempo que tarda en devolver la señal a cero cuando se suelta la tecla.

La Figura 2.1 muestra la forma que adopta la envolvente y cómo se reparten esos cuatro tramos a lo largo de la duración de la nota.

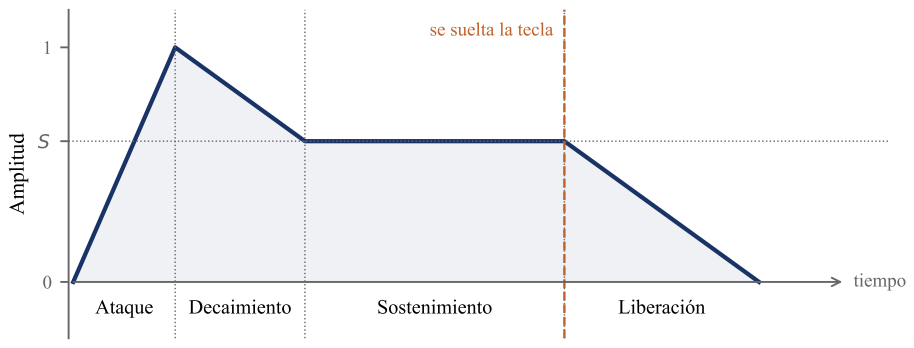
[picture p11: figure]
se suelta la tecla; Amplitud; Ataque; Decaimiento; Sostenimiento; tiempo Liberación

Figura 2.1: Envolvente ADSR. Los dos primeros tramos duran un valor fijo. El tercer tramo depende de cuánto tiempo se mantenga pulsada la tecla. La liberación empieza al soltarla.

El otro elemento habitual en la cadena de un sintetizador es el filtro. Un LPF atenúa las frecuencias por encima de una frecuencia de corte, un HPF hace lo contrario, atenúa las frecuencias por debajo de una frecuencia de corte; y un BPF deja pasar únicamente una banda de frecuencia intermedia. El parámetro de resonancia (Q) realza la respuesta en torno a la frecuencia de corte, lo que da al filtro buena parte de su carácter sonoro.

La Figura 2.2 compara la respuesta en magnitud de los tres tipos sobre una misma frecuencia de corte.

El orden clásico de la cadena en un sintetizador sustractivo es oscilador, filtro y amplificador controlado por la envolvente (ADSR), y es el que se ha mantenido en este trabajo.

6

2.2. SÍNTESIS POR TABLA DE ONDAS

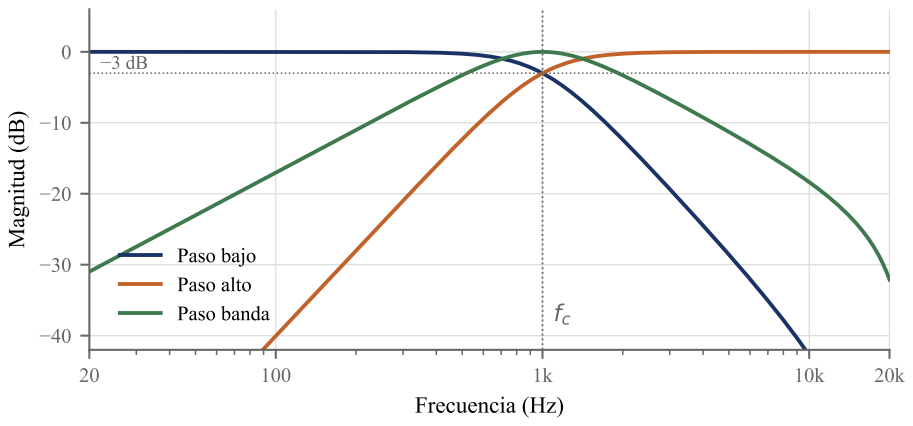
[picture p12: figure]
Frecuencia (Hz); Magnitud (dB); Paso alto Paso banda; Paso bajo

Figura 2.2: Respuesta en magnitud de un filtro paso bajo, uno paso alto y uno paso banda de segundo orden, todos con la frecuencia de corte en 1 kHz y factor de calidad Q = 0,707.

## 2.2 Síntesis por tabla de ondas

La síntesis wavetable se apoya en una observación sencilla. Si una señal es periódica, basta con almacenar un único ciclo y repetirlo. En lugar de evaluar una función trigonométrica para cada muestra, se guarda ese ciclo en una tabla de N posiciones y se recorre cíclicamente a la velocidad que corresponda a la nota deseada [2].

El mecanismo que gobierna esa lectura es el acumulador de fase. Se trata de una variable que avanza una cantidad fija en cada muestra y que vuelve al principio al llegar al final de la tabla. Siendo f0 la frecuencia de la nota, fs la frecuencia de muestreo y N el tamaño de la tabla, el incremento de fase por muestra es el de la Ecuación (2.1).

∆φ =

f0 · N
fs

(2.1)

El acumulador avanza según la Ecuación (2.2), donde el módulo implementa el retorno al inicio de la tabla al completarse cada ciclo.

φ[n + 1] = (φ[n] + ∆φ) mod N | (2.2)

Como ∆φ no es en general un número entero, el acumulador apunta casi siempre a una posición intermedia entre dos muestras de la tabla. La solución habitual es interpolar linealmente entre la muestra anterior y la siguiente, tal como recoge la Ecuación (2.3), donde i = ⌊φ⌋ y α = φ − i es la parte fraccionaria.

s[n] = (1 − α) · T[i] + α · T[(i + 1) mod N] | (2.3)

El coste de generar una muestra se reduce así a una suma, dos multiplicaciones y un acceso a memoria, lo que hace la técnica especialmente adecuada para microcontroladores. Bristow-Johnson señala además que, para tonos musicales cuasiperiódicos, este método resulta equivalente a la síntesis aditiva pero exigiendo mucho menos cálculo en tiempo real [2], que es justo el compromiso

7

CAPÍTULO 2. MARCO TEÓRICO Y ESTADO DEL ARTE

que interesa en un sistema embebido. A cambio, el timbre queda fijado por el contenido de la tabla, de modo que cambiar de sonido implica cambiar de tabla.

La Figura 2.3 ilustra el proceso completo. El acumulador señala una posición fraccionaria dentro de la tabla y el valor de salida se obtiene pesando las dos muestras que lo rodean.

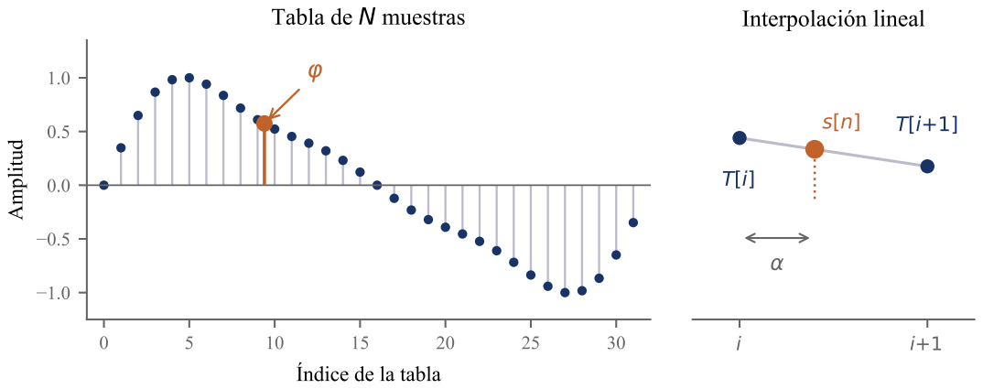
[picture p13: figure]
Índice de la tabla; Amplitud; Tabla de N muestras; Interpolación lineal

Figura 2.3: Lectura de una tabla de ondas. A la izquierda, la tabla almacenada y la posición actual del acumulador de fase φ. A la derecha, el detalle de la interpolación lineal entre las dos muestras vecinas.

### 2.2.1 Aliasing y limitación de banda

Una tabla de N muestras puede contener hasta N/2 armónicos. Al reproducirla a frecuencias altas, los armónicos superiores acaban rebasando la frecuencia de Nyquist y se reflejan hacia el interior del espectro como componentes de frecuencia no armónica, audibles como un timbre metálico y desafinado. Este fenómeno se conoce como aliasing y es el principal problema de la reproducción de tablas a frecuencias elevadas.

La solución habitual consiste en almacenar varias versiones de cada tabla, filtradas para distintos rangos de nota, y seleccionar en cada momento la que corresponda al tono que se está tocando [3]. Conviene señalar que este problema es independiente del tamaño de la tabla y del proceso de remuestreo empleado para construirla. Aumentar N no elimina el aliasing, solo cambia cuántos armónicos hay disponibles para reflejarse. Por las razones que se exponen en el capítulo 3, la limitación de banda queda fuera del alcance de este trabajo.

## 2.3 Autoencoders y espacio latente

Un autoencoder es una red neuronal entrenada para intentar reconstruir su propia entrada. Está formado por dos bloques. El codificador, que transforma la entrada en una representación de dimensión mucho menor; y el decodificador, que intenta reconstruir la entrada original a partir de esa representación reducida. La representación intermedia recibe el nombre de código o vector latente. Los autoencoders son capaces de organizar estos vectores latentes en base a las características de los datos de entrada, de modo que entradas similares acaban situadas cerca unas de otras en un espacio. Es lo denominado el espacio latente.

8

2.3. AUTOENCODERS Y ESPACIO LATENTE

El interés de esta arquitectura no está en la reconstrucción en sí, que sería trivial si no se impusiera ninguna restricción, sino en el cuello de botella. Al obligar a que toda la información pase por un número reducido de valores, la red se ve forzada a quedarse con los rasgos que de verdad distinguen unas entradas de otras. Aplicado a un conjunto de formas de onda, el codificador acaba situando cerca las que comparten características espectrales, sin que se le haya indicado en ningún momento qué es un armónico o qué es un timbre.

### 2.3.1 El autoencoder variacional

Un autoencoder convencional organiza el espacio latente sin ninguna garantía sobre su estructura. Nada impide que queden zonas vacías en este espacio. Un punto tomado de una de esas zonas puede decodificarse en algo sin sentido. Para el uso que se pretende aquí, en el que el usuario recorre el plano con el dedo y pasa continuamente por posiciones que no corresponden a ninguna onda del conjunto de entrenamiento, esa falta de predictibilidad es un problema.

El autoencoder variacional o VAE [4] resuelve esa limitación cambiando la naturaleza del vector latente. En lugar de producir un vector de valores concretos, el codificador produce los parámetros de una distribución de probabilidad, es decir, un vector de medias µ y otro de varianzas σ

2
Así pues, el vector latente que recibe el decodificador se obtiene muestreando esa distribución. El problema de este muestreo es que, al ser una operación aleatoria, no es derivable y bloquea la propagación del gradiente durante el entrenamiento. Para solucionarlo, Kingma y Welling proponen el truco de reparametrización (Ecuación (2.4)). El vector latente se expresa como una función determinista de la media y la desviación típica, utilizando una muestra de ruido externa. De este modo, la aleatoriedad queda aislada en un término independiente de la red y el gradiente puede propagarse sin impedimentos.
z = µ + σ ⊙ ϵ, | ϵ ∼ N (0,I) | (2.4)

Para evitar que el espacio latente quede lleno de huecos vacíos, a la función de pérdida se le añade un segundo término: la divergencia de Kullback-Leibler. Esta métrica compara la distribución del codificador con una normal estándar y actúa como un imán, obligando a todas las nubes de probabilidad a agruparse y solaparse ordenadamente en torno al centro. Así, la pérdida total equilibra la fidelidad de la reconstrucción con este requisito de regularidad, tal como muestra la Ecuación (2.5).

L = MSE(x, ˆx)
| {z }

reconstrucción

+ β · DKL(q(z|x) ∥ N (0,I))
| {z }
| regularización | (2.5)

Para un latente de d dimensiones, la divergencia admite la forma cerrada de la Ecuación (2.6), que es la que se implementa en la práctica.

DKL = −

1
2

X

d

j=1

1 + log σ

2
j − µ

2
j − σ

2
j
(2.6)

El factor β que aparece en la Ecuación (2.5) pondera la importancia relativa de ambos términos y da nombre a la variante conocida como β-VAE [5]. Higgins y sus coautores lo introducen como un hiperparámetro ajustable que equilibra la capacidad del canal latente frente a la precisión de

9

CAPÍTULO 2. MARCO TEÓRICO Y ESTADO DEL ARTE

la reconstrucción, y con valores por encima de la unidad obtienen representaciones factorizadas, en las que cada dimensión del espacio recoge un único factor de variación de los datos y puede moverse sin alterar el resto. Sobre imágenes de caras, por ejemplo, una dimensión gobierna el giro de la cabeza y otra la anchura de la sonrisa.

Conviene no confundir esa propiedad con la continuidad, que es la que interesa aquí y que aporta el término de divergencia en cualquier autoencoder variacional. Lo que β regula es cuánto pesa la regularización frente a la fidelidad de la reconstrucción. Valores altos dan un espacio muy regular a costa de reconstrucciones pobres, porque el modelo prioriza acercar todas las distribuciones a la normal estándar antes que reproducir cada entrada con detalle; valores bajos hacen lo contrario. El compromiso adoptado en este trabajo se justifica en el capítulo 4.

Un fallo habitual en estos modelos es el conocido como colapso posterior. Ocurre cuando la red ignora por completo el espacio latente y el término de divergencia se anula. Este fallo fue observado por Bowman y sus coautores [6] al aplicar VAEs a texto. Esto pasa porque el decodificador es lo suficientemente potente como para reconstruir los datos por su cuenta, sin necesitar ayuda del espacio latente. Para solucionarlo, en este trabajo se ha aplicado su misma técnica: introducir el peso de la divergencia de forma progresiva. Así, durante las primeras épocas el modelo se centra solo en aprender a reconstruir, y el peso se va subiendo poco a poco hasta su valor definitivo, tal como se explica en el capítulo 4.

## 2.4 Estado del arte

La aplicación de redes neuronales a la síntesis de audio ha producido en los últimos años varias líneas de trabajo. Interesa aquí distinguir dos enfoques distintos según qué es lo que la red genera.

### 2.4.1 Modelos que generan la señal de audio

Un primer grupo de trabajos emplea la red para generar directamente la forma de onda de salida, muestra a muestra. El sistema DDSP [7] combina elementos clásicos de procesado de señal, como osciladores armónicos y filtros, con redes neuronales que controlan sus parámetros, de modo que el conocimiento sobre cómo se genera el sonido queda incorporado a la arquitectura en lugar de tener que aprenderse desde cero. RAVE [8] sigue una vía diferente. Se trata de un autoencoder variacional entrenado sobre audio en bruto, con un procedimiento de entrenamiento en dos fases, primero de aprendizaje de la representación y después de ajuste adversario. Sus autores, Caillon y Esling, añaden un análisis posterior del espacio latente que permite decidir el compromiso entre fidelidad de reconstrucción y compacidad de la representación. Es un problema que aparece de nuevo en este trabajo al fijar la dimensión del latente. Su interés para este trabajo es que demuestra que la síntesis neuronal puede alcanzar velocidades de tiempo real, aunque sobre hardware sensiblemente más potente que un microcontrolador.

### 2.4.2 Modelos que generan tablas de onda

El segundo grupo, más cercano a lo que se plantea aquí, no genera audio sino tablas. La red produce una forma de onda de un ciclo que después se reproduce mediante un oscilador convencional, con lo que la carga computacional no depende de la frecuencia de muestreo.

10

2.4. ESTADO DEL ARTE

El trabajo de Hantrakul y Yang [9] es el precedente más directo. Reutilizan el modelo NSynth WaveNet ya entrenado como autoencoder de tablas para generar formas de onda de 512 muestras e interpolar entre ellas en el espacio latente. El resultado se distribuye como plugin VST/AU para DAW.

Dos observaciones suyas resultan especialmente importantes aquí. La primera es de coste. Los propios autores miden unos 4 segundos para codificar y unos 7 para decodificar una única forma de onda sobre una máquina con GPU, lo que descarta por completo ejecutar la red durante la reproducción. Su solución fue generar por adelantado 300 tablas interpolando entre combinaciones de seno, sierra y triangular, y reproducirlas después con un oscilador convencional. Es exactamente la misma estrategia que se adopta en este trabajo. Conviene subrayar que la limitación aparece ya sobre una GPU de sobremesa. Al trabajar sobre microcontroladores de bajo coste, la limitación es aún más severa y obliga a generar las tablas de forma anticipada.

La segunda observación tiene que ver con la estructura del espacio latente. Hantrakul y Yang comprueban que interpolar a lo largo del segmento que une dos vectores del espacio produce mezclas utilizables de las dos ondas de partida, pero que apartarse de ese segmento genera ruido. Dicho de otro modo, en su modelo no todo el espacio latente es válido, solo lo son las trayectorias entre puntos conocidos. Para un instrumento en el que el usuario recorre libremente un plano con el dedo esa limitación es un problema. Esta es una de las razones que justifican emplear en este proyecto un autoencoder variacional en lugar de uno convencional.

Kreković [10] plantea un oscilador basado en un autoencoder y estudia el efecto del conjunto de entrenamiento y de los hiperparámetros sobre la variedad de las formas de onda generadas. Su conclusión fue que emplear las variables latentes directamente como parámetros de entrada produce una transición suave entre las ondas generadas cuando los cambios de esos parámetros son pequeños.

Más recientemente, Wavespace [11] propone un generador de tablas basado en un autoencoder variacional cuyo espacio latente se divide en subespacios asociados a distintos estilos de forma de onda. El generador se condiciona además con descriptores tímbricos y morfológicos, de modo que el usuario puede manipular cada subespacio de forma independiente en lugar de moverse por un plano indiferenciado. Los autores lo prototipan también como plugin de oscilador para DAW, y señalan que la restricción de velocidad de cálculo sigue siendo el principal obstáculo cuando se pretende decodificar una forma de onda para cada bloque de audio.

### 2.4.3 Posicionamiento de este trabajo

De la revisión anterior se desprende que la generación de tablas de onda mediante autoencoders y su interpolación en el espacio latente es un problema ya abordado, y resuelto con solvencia, en varios trabajos previos. La aportación de este trabajo no está, por tanto, en el modelo.

Lo que ninguno de esos trabajos aborda es la materialización del concepto como instrumento físico independiente. Todos ellos se presentan como plugins, aplicaciones de escritorio o prototipos de investigación que se ejecutan sobre un ordenador. La aportación diferencial que se persigue aquí es la integración embebida completa. Eso supone repartir el sistema entre microcontroladores de bajo coste, resolver la comunicación entre ellos, mantener la estabilidad del audio en tiempo real y construir un dispositivo autónomo con control táctil y entrada MIDI que no necesite un ordenador para funcionar. El reto no es de aprendizaje automático, sino de ingeniería de sistemas embebidos.

11

CAPÍTULO 2. MARCO TEÓRICO Y ESTADO DEL ARTE

12

# Capítulo 3

# Diseño del sistema

Este capítulo explica cómo se reparte el sistema entre las placas que lo componen, qué alternativas se valoraron antes de llegar a ese reparto y qué parámetros quedaron fijados antes de empezar a ejecutar. La implementación concreta de cada bloque se trata en los capítulos 5, 6 y 7, y las medidas que verifican el diseño, en el capítulo 8. Aquí interesa el porqué de la estructura.

## 3.1 Requisitos y condicionantes de partida

El instrumento tiene que atender dos tareas que operan en escalas de tiempo muy distintas. Una es producir una forma de onda nueva cuando el usuario mueve el dedo por la pantalla y la otra es entregar 48.000 muestras por segundo de forma ininterrumpida, sin que una espera de comunicación o un cálculo largo dejen el búfer de audio sin llenar. La primera admite unos milisegundos de retraso; la segunda no admite ninguno o se tendrán glitches audibles.

De ahí sale la restricción que gobierna todo el diseño, ya enunciada en el capítulo 1. La inferencia de una red neuronal no puede ejecutarse a frecuencia de audio sobre un microcontrolador, pero tampoco necesita hacerlo. Un dedo sobre una pantalla no genera información nueva a 48 kHz. Basta con que el sistema táctil se lea cada 50 ms, es decir, a 20 Hz. Además, se debe programar para que solo se envíe una coordenada cuando el punto se ha desplazado lo suficiente y evitar tráfico innecesario. Separar la generación de la tabla, que ocurre a frecuencia de control; de su reproducción, que ocurre a frecuencia de audio; es lo que hace viable el conjunto sobre hardware de bajo coste.

Sobre esa base se fijaron los requisitos que el diseño debía cumplir:

- Continuidad del control. El usuario recorre el plano latente de forma continua, así que el cambio de una tabla a la siguiente no puede producir discontinuidades audibles.
- Ejecución musical convencional. La nota y la dinámica entran por MIDI estándar, y la envolvente y el filtro se controlan desde mandos físicos, no desde la pantalla.
- Autonomía. El instrumento debe funcionar sin depender de un ordenador. Debe conformar un módulo de sonido autónomo, con teclado intercambiable y sin necesidad de software adicional.

13

CAPÍTULO 3. DISEÑO DEL SISTEMA

- Integridad de la información. La tabla que sale de una placa tiene que llegar íntegra a la siguiente, y una trama dañada no puede traducirse en ruido a la salida.
- Hardware comercial de bajo coste. No se diseña ni se fabrica ningún circuito integrado específico, y el reparto de tareas tiene que caber en placas de desarrollo disponibles en el mercado.

A estos requisitos se suman los condicionantes normativos y de especificación que impone el material elegido. La entrada de notas sigue la especificación MIDI 1.0, y los rangos de tensión, la tolerancia de los pines y el techo de la frecuencia de corte salen de las hojas de características de las placas y de la documentación de la biblioteca de audio. Cada uno se cita en el capítulo en que se aplica.

## 3.2 Alternativas consideradas

Las tres decisiones que dan forma al sistema se tomaron antes de empezar a construirlo, contrastando cada una con la opción que se descartaba.

### 3.2.1 Ejecutar la red frente a precalcular una rejilla

La primera alternativa era ejecutar el decodificador dentro del propio instrumento, cuantizado a 8 bits y desplegado sobre el ESP32-S3 de modo que cada coordenada táctil produjera una forma de onda recién generada. La segunda era muestrear el plano latente por adelantado en el ordenador, obtener una rejilla de formas de onda ya decodificadas y embarcar esa rejilla, dejando al instrumento la consulta y la mezcla.

Se adoptó la segunda como camino principal. Aunque la red solo tenga que trabajar a frecuencia de control, ejecutar el decodificador en cada toque introduce un tiempo de cálculo variable que complica el modelo. Sobre un procesador que además tiene que atender la comunicación con las otras dos placas, esto se traduce en posibles microinterrupciones en el audio. La rejilla precalculada convierte ese cálculo en un acceso a memoria y una interpolación, de coste conocido y constante. El trabajo más cercano hace lo mismo por el mismo motivo, y allí la limitación aparece incluso sobre una máquina con GPU dedicada [9].

El precio de esa decisión es que la resolución del espacio queda congelada en el momento de generar la rejilla, y que esa rejilla ocupa memoria. El decodificador embarcado se mantiene como posible ampliación y se retomará en el capítulo 9.

### 3.2.2 Dónde reside la rejilla

Fijada la rejilla, quedaba decidir en qué placa vive y, en consecuencia, qué viaja por el bus. La primera opción era guardarla en la Daisy Seed, que dispone de memoria externa de sobra, y hacer que la CYD le enviara únicamente la coordenada táctil, seis bytes por toque. La segunda opción era guardarla en el ESP32-S3, hacer allí la interpolación y enviar a la Daisy la forma de onda completa, algo más de dos kilobytes por toque.

14

3.3. ARQUITECTURA RESULTANTE

Se eligió la segunda. La primera es más sencilla y mueve mucha menos información pero carga al procesador de audio con una tarea que no le corresponde y, sobre todo, cierra la puerta a la ampliación del apartado anterior. Manteniendo la rejilla y la interpolación en el ESP32-S3, sustituirla más adelante por el decodificador ejecutándose en tiempo real no obliga a tocar el código de la Daisy Seed, ya que seguiría recibiendo exactamente lo mismo. El reparto resultante deja a cada placa una responsabilidad única, esto es lo que permitió después validar cada etapa por separado.

### 3.2.3 Dónde se resuelve la transición entre tablas

Sustituir la tabla en reproducción mientras suena una nota produce un salto en la señal, audible como un chasquido. La transición puede resolverse de dos formas. Una es esperar a que el acumulador de fase complete el ciclo y cambiar la tabla justo en ese punto. La otra es mezclar la tabla antigua y la nueva durante unos milisegundos, con pesos complementarios. En ambos casos se necesitaría doble búfer: uno para la forma de onda que se está reproduciendo y otra para la nueva.

Se optó por la mezcla, porque funciona con independencia de dónde esté la fase en el momento del cambio y porque encaja con el uso previsto en el que el dedo se desplaza de forma continua y las tablas consecutivas se parecen mucho entre sí. Este cálculo se hará en la Daisy ya que es la única placa que conoce la posición instantánea del acumulador de fase, debido a que es quien recorre la tabla muestra a muestra. El ESP32-S3 no dispone de esa información y llegaría siempre tarde o pronto al punto de corte, así que la transición debe de hacerla el procesador de audio y no en el de control.

## 3.3 Arquitectura resultante

El sistema queda repartido entre tres microcontroladores con funciones separadas, tal como muestra

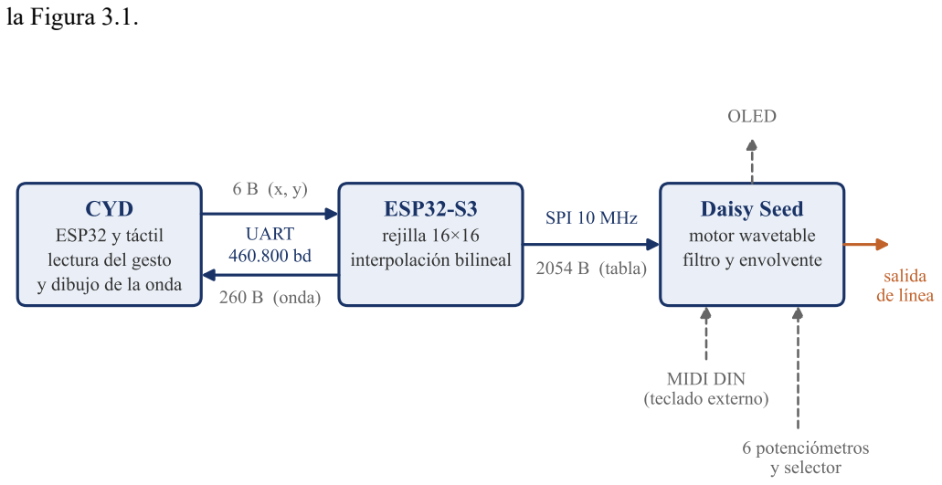
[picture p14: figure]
la Figura 3.1.; CYD; ESP32 y táctil lectura del gesto y dibujo de la onda; ESP32-S3; rejilla 16×16 interpolación bilineal; Daisy Seed; motor wavetable filtro y envolvente; 260 B (onda); UART 460.800 bd; SPI 10 MHz; 2054 B (tabla); salida; de línea; MIDI DIN (teclado externo); 6 potenciómetros y selector; OLED

Figura 3.1: Arquitectura del sistema. Las flechas continuas son los enlaces digitales entre placas, rotuladas con el medio y el tamaño de la trama; las discontinuas, los periféricos del procesador de audio.

15

CAPÍTULO 3. DISEÑO DEL SISTEMA

La CYD es la interfaz de usuario. Se trata de una placa que integra un ESP32 y una pantalla táctil resistiva de 2,8 pulgadas. Lee la posición del dedo, la normaliza a un rango de 16 bits por eje y la envía por UART. En sentido contrario recibe la forma de onda que está sonando y la dibuja en pantalla. Así el usuario puede ver el timbre que está seleccionando.

El ESP32-S3 es el procesador de control. Aloja la rejilla de formas de onda en su memoria de programa, calcula la interpolación entre las cuatro celdas vecinas a la coordenada recibida y entrega el resultado al procesador de audio por SPI. Es también quien devuelve a la pantalla la onda para que pueda representarla. Se eligió la variante con 16 MB de memoria de programa y 8 MB de PSRAM, con margen sobrado para la rejilla y para una eventual ampliación.

La Daisy Seed es el procesador de audio. Reproduce la tabla que recibe mediante un acumulador de fase, resuelve la transición entre tablas, aplica el filtro y la envolvente ADSR y entrega la señal por su conversor digital-analógico. Recibe además la nota y la velocidad de esta por MIDI y lee los seis potenciómetros y el selector del panel de control. Además, refleja en una pantalla OLED el mando que se está manipulando para que el usuario sea conocedor del valor que está aplicando. No conoce la rejilla ni interpola, solo reproduce lo que le llega.

El teclado que proporciona las notas queda fuera del conjunto. Se conecta exclusivamente por MIDI DIN, cuyo aislamiento por optoacoplador evita que las dos masas se unan. Esta separación es deliberada, y su consecuencia es que el entregable de este trabajo es un módulo de sonido con teclado intercambiable y no un instrumento con teclado propio. Esta es la práctica habitual en la instrumentación electrónica modular.

## 3.4 Fase de preparación y fase de ejecución

El sistema opera en dos fases separadas en el tiempo y en el lugar, recogidas en la Figura 3.2. La primera ocurre una sola vez en el ordenador, y es la única en la que interviene la red neuronal. El conjunto de formas de onda se estandariza, se entrena el autoencoder variacional, se muestrea el plano latente en una rejilla regular decodificando cada nodo. El resultado se exporta como una cabecera en C que se compila junto al firmware del ESP32-S3. La segunda ocurre en el instrumento cuando se reciben coordenadas con cada toque. Esta no ejecuta ninguna red, solo consulta la rejilla, interpola y envía la forma de onda resultante al procesador de audio.

16

3.5. PARÁMETROS DE DISEÑO

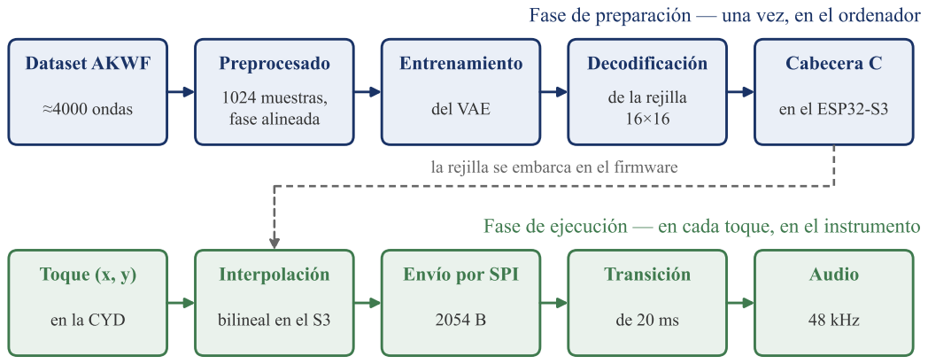
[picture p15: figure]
Dataset AKWF; ≈4000 ondas; Preprocesado; 1024 muestras, fase alineada; Entrenamiento; del VAE; Decodificación; de la rejilla 16×16; Cabecera C; en el ESP32-S3; Toque (x, y); en la CYD; Interpolación; bilineal en el S3; Envío por SPI; Transición; Audio; 48 kHz; la rejilla se embarca en el firmware

Fase de preparación — una vez, en el ordenador

Fase de ejecución — en cada toque, en el instrumento

Figura 3.2: Las dos fases de operación. La red neuronal solo interviene en la fase de preparación; durante la ejecución el instrumento se limita a consultar la rejilla, mezclar y reproducir.

Conviene aclarar qué contiene la rejilla, porque es el punto que sostiene toda la estrategia. Los 256 nodos no son una selección de las ondas del conjunto de datos. Una vez entrenado el modelo, el codificador reparte las ondas originales como puntos dispersos por un plano continuo. El decodificador sabe generar una onda para cualquier posición de ese plano, incluidas las que no corresponden a ninguna onda real. Generar la rejilla es muestrear esa superficie continua en cruces regulares, de modo que la mayoría de los nodos son formas de onda nuevas. Lo aprendido a partir del conjunto de datos reside en los pesos del decodificador, y la rejilla es solo una captura de esa superficie a una resolución elegida. Lo que fija su tamaño, por tanto, es la finura con la que se navega el espacio y la memoria que se consume, no la variedad de timbres disponibles.

La segunda cuestión es por qué basta con una interpolación lineal durante la ejecución, siendo la operación más simple posible. Hay dos motivos. El primero es que todas las formas de onda comparten una referencia de fase común. Esta fue fijada en el preprocesado con lo que no hay desalineamientos gruesos que puedan cancelarse al promediar. El segundo es que dos celdas contiguas de la rejilla no son dos ondas cualesquiera, sino dos puntos muy próximos de una misma función continua y suave, el decodificador, de modo que sus salidas se parecen mucho. Interpolar linealmente entre dos formas de onda casi idénticas deja un error pequeño, que además disminuye al aumentar la densidad de la rejilla. El trabajo complejo de organizar el espacio latente ya lo hizo el decodificador al generar los nodos. En tiempo de ejecución, la interpolación lineal solo se encarga de transicionar de forma fluida entre puntos que ya están ordenados.

## 3.5 Parámetros de diseño

La Tabla 3.1 recoge los valores que se fijaron al principio y que no se modificaron después, porque condicionan a la vez el entrenamiento, el formato de las tramas y el motor de audio.

El tamaño de 1024 muestras merece justificación porque las ondas del conjunto de datos tienen
600. Una onda de 600 muestras contiene como mucho 300 armónicos, que es el límite de Nyquist del propio ciclo. Remuestrear a 1024, la menor potencia de dos por encima de las 600 muestras

17

CAPÍTULO 3. DISEÑO DEL SISTEMA

Tabla 3.1: Parámetros de diseño fijados antes de la implementación.

Parámetro | | Valor
Muestras por forma de onda | 1024
Formato de muestra | entero de 16 bits con signo (Q15)
Dimensión del espacio latente | 2
Tamaño de la rejilla | 16 × 16 (256 formas de onda)
Memoria ocupada por la rejilla | 512 kB
Frecuencia de muestreo de audio | 48 kHz
Tamaño del bloque de audio | 48 muestras
Duración de la transición entre tablas | 20 ms
Periodo de lectura del táctil | 50 ms

originales, recoge entonces todo el contenido armónico disponible sin desperdicio. Que sea potencia de dos aporta además una ventaja práctica en la reproducción, ya que el retorno al inicio de la tabla se resuelve con una máscara de bits en lugar de con una operación de módulo.

Queda por justificar una ausencia. Como se indicó en el capítulo 2, la limitación de banda de las tablas no forma parte de este trabajo. El aliasing no lo introduce el remuestreo del conjunto de datos, sino la reproducción de notas agudas en las cuales los armónicos altos de la tabla superan la frecuencia de Nyquist. Corregirlo exige almacenar varias versiones filtradas de cada forma de onda y elegir la adecuada según la nota lo que multiplica por ese número de versiones el volumen de datos. Esto queda como ampliación futura, y el instrumento se entrega con las tablas originales sin filtrar.

## 3.6 Enlaces de comunicación

El sistema tiene tres enlaces, resumidos en la Tabla 3.2. Los dos primeros comparten el mismo par de hilos en sentidos opuestos, aprovechando que el UART es bidireccional.

Tabla 3.2: Enlaces de comunicación entre placas.

Enlace | Medio | Contenido | Trama | Tiempo
CYD → ESP32-S3 | UART 460.800 bd coordenada táctil | 6 B | 130 µs
ESP32-S3 → CYD | UART 460.800 bd onda para dibujar | 260 B | 5,6 ms
ESP32-S3 → Daisy | SPI 10 MHz | forma de onda | 2054 B | 1,6 ms

La elección del medio para el enlace principal viene dada por el volumen. Enviar 1024 muestras de 16 bits por UART, incluso a 921.600 baudios, llevaría unos 22 ms. Este es tiempo suficiente para que el gesto del dedo se note retrasado. El mismo envío por SPI a 10 MHz ocupa menos de 2 ms lo que lo convierte en la opción viable para la forma de onda. Para la coordenada táctil en cambio el UART sobra, porque son seis bytes y el tiempo de transmisión es despreciable frente al periodo de lectura del táctil.

Las tres tramas comparten criterio de construcción. Todas empiezan por una cabecera de sincronización conocida que permite al receptor reengancharse si pierde el hilo. Las de mayor tamaño

18

3.6. ENLACES DE COMUNICACIÓN

llevan además un número de secuencia, útil para correlacionar lo enviado con lo recibido durante la validación. La comprobación de integridad se dimensiona según lo que hay en juego. Una suma de comprobación por XOR de los bytes de datos basta en los enlaces cortos, mientras que la forma de onda viaja protegida por un CRC de 16 bits. El criterio ante un fallo es el mismo en los tres casos, descartar la trama y conservar el último dato válido. En el enlace de audio eso significa que el instrumento sigue sonando con la tabla anterior en lugar de reproducir muestras corrompidas. Esto es justamente el comportamiento que exigía el requisito de integridad del apartado 3.1.

El canal de vuelta hacia la pantalla merece una nota. Transporta la onda reducida a 256 muestras de 8 bits, no la tabla completa, porque su destino es una representación gráfica de 320 píxeles de ancho. Enviar los 2048 bytes originales a esa velocidad ocuparía unos 45 ms por onda, imposible de seguir con el dedo en movimiento, frente a los algo más de cinco milisegundos que cuesta la trama reducida.

19

CAPÍTULO 3. DISEÑO DEL SISTEMA

20

# Capítulo 4

# Modelo neuronal

Este capítulo recorre la fase de preparación descrita en el apartado 3.4, la única del sistema en la que interviene una red neuronal. Se parte de un conjunto público de formas de onda de un ciclo, se homogeneiza, se entrena con él un autoencoder variacional con espacio bidimensional y se muestrea el plano aprendido en una rejilla que se exporta como cabecera en C. Esto se hizo en el ordenador y una sola vez. De esta manera, el instrumento recibe únicamente el resultado del muestreo de la red.

## 4.1 El conjunto de datos de partida

El material de entrenamiento procede de AKWF [12], una colección pública de formas de onda de un ciclo pensada originalmente para cargar en sintetizadores wavetable. Contiene 4358 ondas repartidas en 65 carpetas, todas con el mismo formato: monofónicas y de 600 muestras por ciclo.

Esa homogeneidad de formato es lo que hace la colección utilizable sin apenas trabajo de limpieza. Hay carpetas de formas geométricas clásicas, de emulaciones de instrumentos acústicos, de sonidos de videoconsola y de material ruidoso sin tono definido. Un autoencoder solo puede organizar un plano de timbres si el material de partida tiene timbres distintos que organizar, así que tener esta variedad de sonidos hace que este dataset sea utilizable.

Conviene aclarar desde el principio qué son esas 65 carpetas. Son etiquetas de organización que puso el autor de la colección, no una clasificación tímbrica rigurosa. Se emplean más adelante para colorear las figuras del espacio latente, porque ayudan a leerlas, pero en ningún momento entran en el entrenamiento. El modelo no ve etiquetas de ningún tipo, solo las ondas puras.

## 4.2 Preprocesado

Antes de entrenar hay que dejar las 4358 ondas en un formato común, tarea de la que se ocupa el programa de preprocesado 2_build_dataset.py. Aquí se aplican cuatro operaciones a cada onda.

Remuestreo a 1024 muestras. Se emplea scipy.signal.resample, que interpola en el dominio de la frecuencia mediante la FFT en lugar de hacerlo en el tiempo. Una interpolación espectral

21

CAPÍTULO 4. MODELO NEURONAL

respeta la periodicidad de la señal y devuelve un ciclo que sigue cerrando sobre sí mismo, mientras que un método temporal introduciría una discontinuidad en el punto de empalme. El porqué de 1024 y no otro tamaño ya se justificó en el apartado 3.5.

Eliminación de la componente continua. Se resta la media de la onda. Una tabla con desplazamiento vertical produce un salto en la salida del conversor al cambiar de timbre y, sumada a otra tabla durante una transición, desplaza el resultado sin aportar nada audible.

Alineación de fase. Es el paso más importante. Las ondas de AKWF vienen guardadas de tal manera que empiezan aproximadamente en el cruce por cero ascendente del ciclo, pero esa referencia no es fiable. Una onda con mucho contenido armónico cruza el cero muchas veces, así que el punto de arranque elegido es en buena medida arbitrario y varía de una onda a otra. Dos ondas con el mismo espectro y distinto punto de referencia son, para la red, dos entradas diferentes. Al promediarlas se producirían cancelaciones entre armónicos en lugar de un timbre intermedio.

La solución adoptada consiste en rotar cada ciclo hasta dejar su armónico fundamental en fase cero. La rotación se hace en el dominio de la frecuencia multiplicando el armónico k por e

−jkφ, siendo φ
la fase del fundamental. Eso equivale a un desplazamiento circular de la onda que además admite valores fraccionarios de muestra. Como se aplica a todos los armónicos de forma coherente, el ciclo sigue cerrando y no aparece ningún chasquido.

Tras alinear, las ondas no arrancan todas en el mismo valor de amplitud. No es un fallo del procedimiento. Lo que queda alineado es el fundamental, mientras que la muestra cero de cada onda es la suma de ese fundamental y de todos los armónicos superiores, cuyo reparto es distinto en cada caso. Dicho de otro modo, lo que sobrevive a la alineación es precisamente lo que distingue un timbre de otro.

La propiedad que de verdad se persigue es la invarianza. La Figura 4.1 la comprueba tomando una misma onda y arrancándola en cuatro puntos distintos del ciclo. Antes de alinear son cuatro curvas claramente diferentes; después, las cuatro colapsan en una sola, con una diferencia máxima entre ellas del orden de 10−16, que es cero a efectos del ordenador. Con esa garantía, el punto de arranque de la onda original deja de existir como variable, y la interpolación lineal entre tablas realizada en los embebidos, justificada en el apartado 3.4, opera sobre ondas que comparten referencia.

Normalización de amplitud. Cada onda se divide por su valor absoluto máximo, de modo que todas ocupan el rango [−1, 1]. Así el modelo no gasta capacidad en representar diferencias de nivel, que en un instrumento las fija la dinámica de la nota y no la tabla.

Queda un caso que el procedimiento no puede tratar igual. Las ondas de ruido o percusivas no tienen un fundamental identificable. Por ello, rotar el ciclo tomando como referencia la fase de un armónico despreciable introduciría un giro aleatorio. El script detecta esa situación comparando la magnitud del fundamental con la del armónico más fuerte. Si la relación cae por debajo de 10−3
, es decir, no tiene una fundamental claramente diferenciada, deja la onda sin rotar en lugar de descartarla. Afecta a 100 ondas, un 2,3 % del total. Corresponde sobre todo a las ondas con armónico fundamental débil o ausente (la carpeta overtone y varias de las numeradas), más algunas de material estéreo. Mantenerlo en el conjunto aporta variedad tímbrica en los bordes del espacio sin comprometer la alineación del resto.

El resultado es una matriz de 4358 × 1024 valores en coma flotante, que es lo que consume el entrenamiento.

22

4.3. ARQUITECTURA DEL MODELO

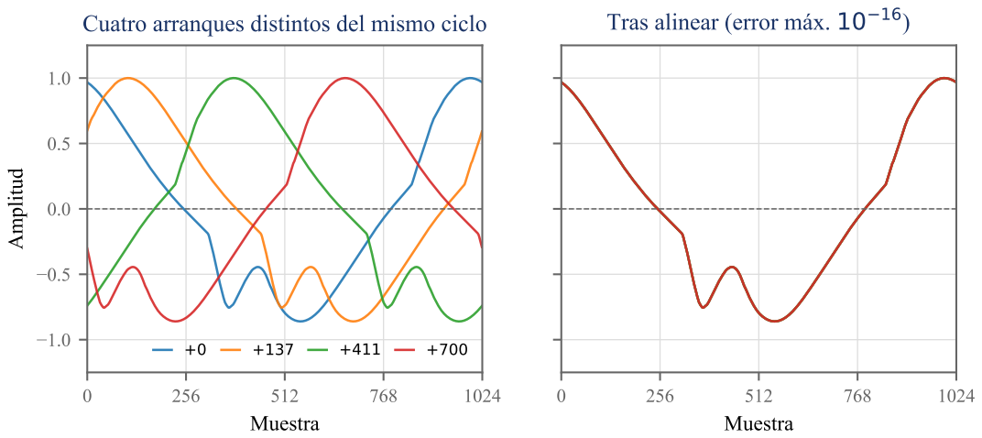
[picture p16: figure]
Muestra; Amplitud; Tras alinear (error máx. 10

Cuatro arranques distintos del mismo ciclo

Figura 4.1: Invarianza de la alineación al punto de arranque. La misma onda desplazada 0, 137, 411 y 700 muestras produce cuatro curvas distintas; tras llevar el fundamental a fase cero, las cuatro quedan superpuestas.

## 4.3 Arquitectura del modelo

El modelo es un autoencoder variacional de capas totalmente conectadas. El codificador reduce las 1024 muestras a 512 y después a 128. De ahí salen dos vectores de dos componentes, la media y el logaritmo de la varianza de la distribución latente. El decodificador es el espejo exacto del codificador, de 2 a 128, a 512 y a 1024. Las capas intermedias usan la función de activación lineal rectificada y la salida usa tangente hiperbólica, que acota el resultado en [−1, 1] y recoge así la normalización de amplitud del apartado anterior. En total suma 1.182.724 parámetros.

Cabe preguntarse por qué capas totalmente conectadas y no convolucionales, que son la elección habitual cuando la entrada es una señal. La razón está en el preprocesado. Una red convolucional aporta invarianza a traslación, útil cuando el mismo patrón puede aparecer en cualquier posición de la entrada, pero la alineación de fase ya eliminó esa variabilidad y todas las ondas llegan a la red con la misma referencia y la misma longitud. La invarianza que aportaría la convolución ya está resuelta antes de entrar, así que solo añadiría complejidad.

La Tabla 4.1 recoge la configuración completa del modelo y del entrenamiento.

23

CAPÍTULO 4. MODELO NEURONAL

Tabla 4.1: Configuración del autoencoder variacional y del entrenamiento.

Parámetro | Valor
Dimensión de entrada y salida | 1024
Capas ocultas del codificador | 512, 128
Dimensión del espacio latente | 2
Activación intermedia | lineal rectificada
Activación de salida | tangente hiperbólica
Parámetros entrenables | 1.182.724
Optimizador | Adam, tasa de aprendizaje 10−3
Tamaño de lote | 64
Épocas | 300
División entrenamiento/validación | 3923 / 435 (90/10)
Peso de la divergencia, β | 0,001
Rampa de β | lineal, 50 épocas
Semilla | 42

## 4.4 Función de pérdida y elección de β

La función que se minimiza es la que se planteó en el capítulo 2, el MSE entre la onda de entrada y su reconstrucción más la divergencia de Kullback-Leibler ponderada por un factor β. El primer término corresponde a la fidelidad de reconstrucción y el segundo hace que las distribuciones que produce el codificador se parezcan a una normal estándar, lo que mantiene el plano latente ocupado de forma continua.

El valor adoptado es β = 0,001, y conviene precisar en qué dirección va esa elección. Higgins y sus coautores introducen el factor proponiendo valores mayores que la unidad, porque su objetivo es obtener representaciones desenredadas, en las que cada dimensión del latente controle un factor de variación independiente e interpretable [5]. Aquí se ha adoptado el compromiso contrario, con un valor tres órdenes de magnitud por debajo de la unidad.

Un latente de dos dimensiones destinado a un dedo sobre una pantalla no necesita ejes que controlen de forma independiente un parámetro concreto del sonido. El usuario no manipula parámetros con nombre, sino que explora una superficie y se queda donde le gusta lo que oye. Lo que sí necesita es reconstruir con la mayor fidelidad posible y no dejar huecos entre zonas ocupadas. Penalizar con fuerza la divergencia habría acercado todas las distribuciones a la normal estándar. De esta manera, todas las reconstrucciones se habrían parecido a la onda media, que es el resultado que arruina un instrumento pensado para recorrer timbres. La regularización sigue haciendo falta, y por eso el término está presente pero con el peso justo para ordenar el plano sin aplanarlo.

Al entrenamiento se le añadió además una precaución que no estaba en el plan inicial. En lugar de aplicar β desde la primera época, se sube de cero a su valor definitivo mediante una rampa lineal a lo largo de las 50 primeras. Es la técnica que emplean Bowman y sus coautores para evitar el colapso posterior [6], ya descrita en el capítulo 2. Durante esas primeras épocas el modelo se concentra en aprender a reconstruir, y solo cuando ya tiene algo que perder entra la presión de la regularización.

24

4.5. ENTRENAMIENTO

## 4.5 Entrenamiento

El entrenamiento se ejecutó en local sobre una tarjeta gráfica NVIDIA RTX 3060. El modelo es pequeño para el hardware disponible, así que las 300 épocas no supusieron ninguna limitación y no hubo necesidad de recurrir a servicios de cómputo remoto. El conjunto se dividió en 3923 ondas para entrenar y 435 para validar, con semilla fija para que la partición sea reproducible.

La Figura 4.2 recoge la evolución de las dos magnitudes que interesan.

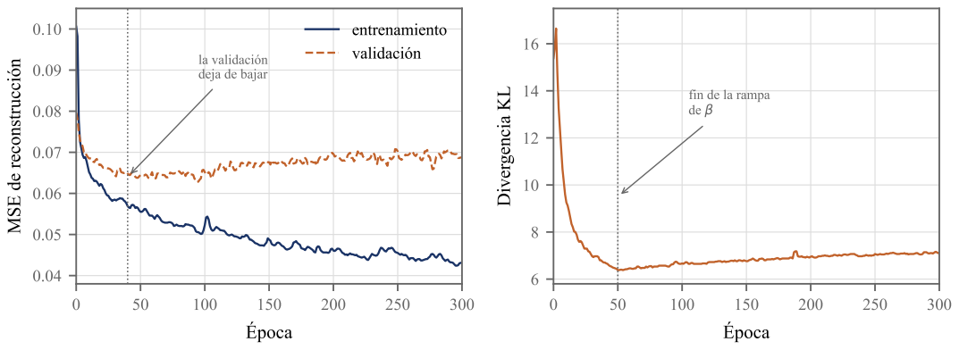
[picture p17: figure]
Época; MSE de reconstrucción; la validación deja de bajar; validación; entrenamiento; Divergencia KL; fin de la rampa de β

Figura 4.2: Evolución del error de reconstrucción y de la divergencia de Kullback-Leibler a lo largo de las 300 épocas. La línea de puntos del panel izquierdo marca el momento en que la validación deja de mejorar; la del derecho, el final de la rampa de β.

Los valores al terminar son un error de reconstrucción de 0,043 en entrenamiento y de 0,068 en validación, con la divergencia estabilizada en torno a 7. Esa divergencia es el primer indicio de que el modelo funciona como debe. Un valor claramente distinto de cero significa que el latente transporta información. Si el modelo hubiese optado por ignorarlo, la divergencia habría caído a cero y el decodificador produciría la misma onda para cualquier coordenada.

El panel izquierdo muestra también un comportamiento que conviene nombrar sin rodeos. El error de entrenamiento sigue bajando hasta el final, pero el de validación se aplana en torno a 0,065 hacia la época 40 y a partir de ahí incluso repunta ligeramente. Es la forma habitual del sobreajuste, y significa que las más de 250 épocas restantes no aportaron capacidad de generalización alguna. La distancia entre ambas curvas es moderada y el modelo sigue siendo utilizable, pero el mismo resultado se habría conseguido en una fracción del tiempo deteniendo el entrenamiento hacia la época 80.

## 4.6 El espacio latente resultante

Terminado el entrenamiento, cada una de las 4358 ondas tiene asignada una coordenada en el plano. La Figura 4.3 las representa todas, coloreando las doce carpetas más numerosas y dejando el resto en gris.

25

CAPÍTULO 4. MODELO NEURONAL

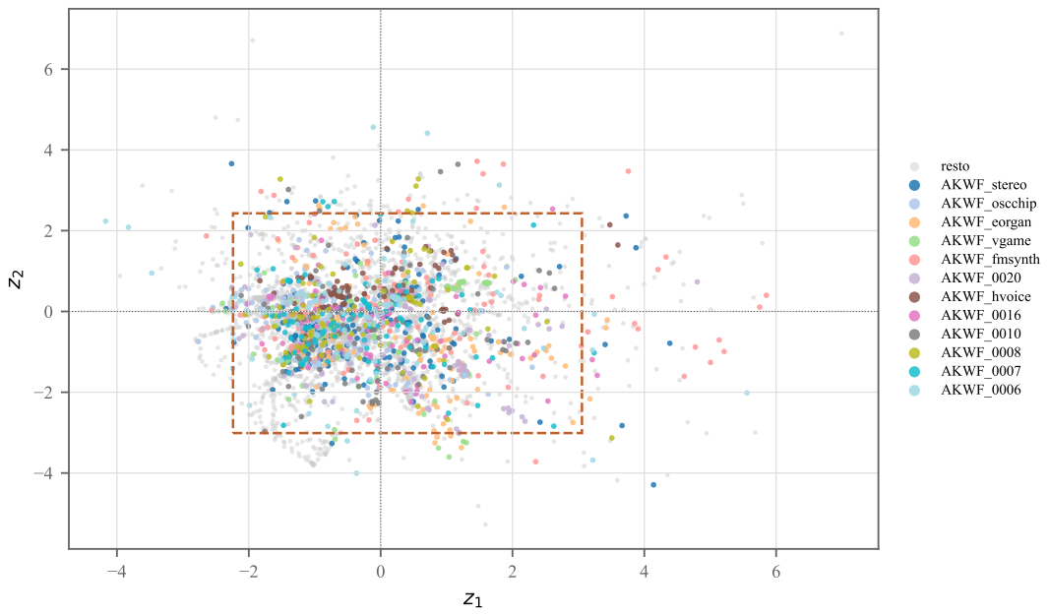
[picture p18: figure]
resto AKWF_stereo AKWF_oscchip AKWF_eorgan AKWF_vgame AKWF_fmsynth AKWF_0020 AKWF_hvoice AKWF_0016 AKWF_0010 AKWF_0008 AKWF_0007 AKWF_0006

Figura 4.3: Espacio latente aprendido. Cada punto es la media de la distribución que el codificador asigna a una onda. El rectángulo a trazos delimita los percentiles 2 y 98 de cada eje.

La nube ocupa aproximadamente de −4,2 a 7,0 en el primer eje y de −5,3 a 6,9 en el segundo, con la densidad concentrada en torno al origen y unos pocos puntos dispersos hacia los bordes. Es la forma que produce un autoencoder variacional típico. El término de regularización empuja la masa hacia el centro, y las ondas más atípicas son las únicas que compensa alejar pagando el coste que eso supone en la pérdida. Un latente colapsado tendría un aspecto muy distinto. Tendría todos los puntos apelotonados en una región mínima y una divergencia próxima a cero.

Hay un rasgo de la figura que a primera vista parece un mal resultado y no lo es. Las carpetas se solapan mucho entre sí, y ninguna forma un grupo bien separado del resto. Ahora bien, encajar 65 categorías en un plano de dos dimensiones de forma separable no es posible, y tampoco es lo que se pide al modelo. El codificador organiza las ondas por su forma, que es lo único que ve. Así pues, dos carpetas distintas con contenido espectral parecido acaban ocupando la misma zona. Para el uso previsto eso es justo lo deseable, porque lo que tiene que garantizar el plano es que puntos próximos suenen parecido, no que la carpeta de origen sea recuperable.

## 4.7 Fidelidad de la reconstrucción

Las cifras de pérdida dicen cuánto se equivoca el modelo de media, pero no en qué se equivoca. La Figura 4.4 compara cuatro ondas del conjunto con la salida del decodificador, ordenadas de menor a mayor error.

26

4.7. FIDELIDAD DE LA RECONSTRUCCIÓN

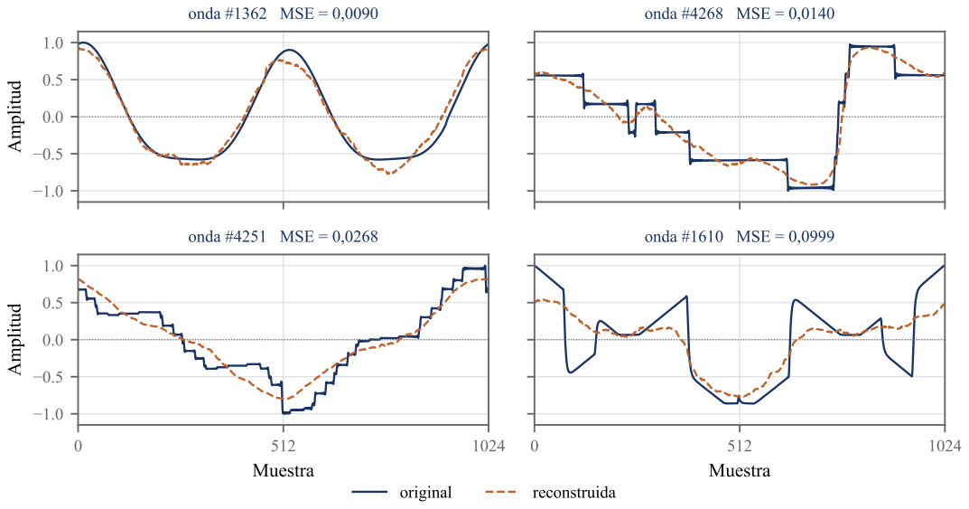
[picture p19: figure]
Amplitud; onda #1362 MSE = 0,0090; onda #4268 MSE = 0,0140; Muestra; onda #4251 MSE = 0,0268; onda #1610 MSE = 0,0999; original; reconstruida

Figura 4.4: Cuatro ondas del conjunto de entrenamiento frente a su reconstrucción, con el error cuadrático medio de cada una. La pérdida de detalle se concentra en los flancos verticales.

El patrón es claro. Las ondas suaves, con pocos armónicos y sin discontinuidades, se recuperan casi exactas. Las que tienen escalones y flancos verticales pierden precisamente los flancos, que el decodificador sustituye por transiciones redondeadas. El error crece a medida que aumenta el número de esos escalones.

Este comportamiento es el límite intrínseco del cuello de botella de dos dimensiones y no un defecto del entrenamiento. Un flanco vertical exige mucho contenido de alta frecuencia y ese contenido no cabe en dos números. Obligado a elegir, el modelo aprende los rasgos perceptuales gruesos, la cantidad de brillo y el número de picos por ciclo, y descarta el detalle fino. Es la contrapartida directa de haber fijado el latente en dos dimensiones por exigencia del control táctil, condicionante que ya se enunció en el capítulo 1.

Con estos resultados sobre la mesa se planteó si convenía volver a entrenar antes de seguir. Se decidió que no, por cuatro motivos. El primero es que el objetivo del instrumento no es reproducir fielmente cada onda del conjunto, sino recorrer un plano de timbres con transiciones suaves. Para eso importa que el latente sea continuo y esté bien repartido, cosa que ya cumplía. El segundo es que subir β para suavizar aún más el plano habría acercado todo hacia la media, con lo que se gana regularidad y se pierde carácter. El tercero es que retirar del conjunto las carpetas de ondas más dentadas habría reducido la variedad tímbrica disponible sin resolver el suavizado de flancos, que depende de la dimensión del latente y no del material de entrada. El cuarto es que recortar el número de épocas ahorra tiempo de cálculo pero no cambia el modelo resultante. Se fijó, eso sí, un criterio para más adelante: si al escuchar el resultado apareciera algo objetivamente defectuoso, se reentrenaría entonces con ese dato y no antes.

27

CAPÍTULO 4. MODELO NEURONAL

## 4.8 Horneado de la rejilla

El último paso de la fase de preparación convierte el decodificador en una tabla. El script 4_bake_ grid.py codifica todo el conjunto para conocer la distribución real del plano, fija los límites de la zona que interesa muestrear, decodifica una onda en cada nodo de una rejilla regular y exporta el resultado.

La primera decisión es dónde poner los límites. Un cuadrado fijo y generoso, del tipo [−6, 6] en ambos ejes, dejaría las esquinas de la rejilla en zonas del plano donde no cayó ninguna onda durante el entrenamiento. El decodificador sigue produciendo algo en esos puntos, pero es una extrapolación de la que no hay ninguna garantía. En su lugar se toman los percentiles 2 y 98 de cada eje, que recortan la zona efectivamente poblada y dejan fuera los pocos puntos extremos. Los valores resultantes son [−2,239, 3,054] en el eje X y [−3,010, 2,429] en el eje Y. Son los que dibuja el rectángulo de la Figura 4.3. El precio es perder los timbres más raros, que quedaban justamente en los bordes. A cambio, cualquier punto que toque el usuario cae en puntos con ondas cercanas.

La segunda es que la decodificación es determinista. El decodificador es una función fija de la coordenada, así que un mismo nodo produce siempre la misma onda; el muestreo aleatorio del autoencoder variacional solo interviene al codificar durante el entrenamiento. Lo que sí exige el modo de evaluación es el cálculo de los límites del párrafo anterior, que codifica el conjunto entero y toma la media de cada distribución en lugar de una muestra. Sin eso, los percentiles, y con ellos la rejilla, dependerían de la semilla y dejarían de ser reproducibles.

La tercera es el formato de salida. El decodificador entrega valores en [−1, 1] y la cabecera los guarda como enteros de 16 bits con signo en formato Q15 tal como se fijó en el apartado 3.5. Así pues, las 256 tablas de 1024 muestras ocupan 512 kB de memoria de programa, frente al doble que habrían ocupado en coma flotante. La cabecera fija además la convención de índices que el firmware tiene que respetar, con la fila recorriendo el segundo eje y la columna el primero. Además, deja anotados los cuatro límites del plano latente como constancia de qué región representa la rejilla. Esos límites no llegan a usarse en el instrumento, porque al ESP32-S3 le basta con recorrer la rejilla por índices y la correspondencia con el plano latente queda implícita en el propio muestreo. Estos valores se guardan porque son lo que permite reconstruir de dónde salió cada tabla si se rehornea con otros valores.

La Figura 4.5 muestra el contenido de la rejilla horneada.

Al saltarse dos nodos de cada tres, la figura no sirve para juzgar si celdas vecinas se parecen entre sí, pero sí deja ver que el plano cubre formas muy distintas, desde pulsos casi rectangulares hasta ondas de varios picos con mucho contenido armónico. Que las celdas realmente contiguas se parezcan viene garantizado por otra vía, y es que el decodificador es una función continua y dos nodos adyacentes están muy próximos en el plano de entrada.

28

4.9. VALIDACIÓN PREVIA AL EMBARQUE

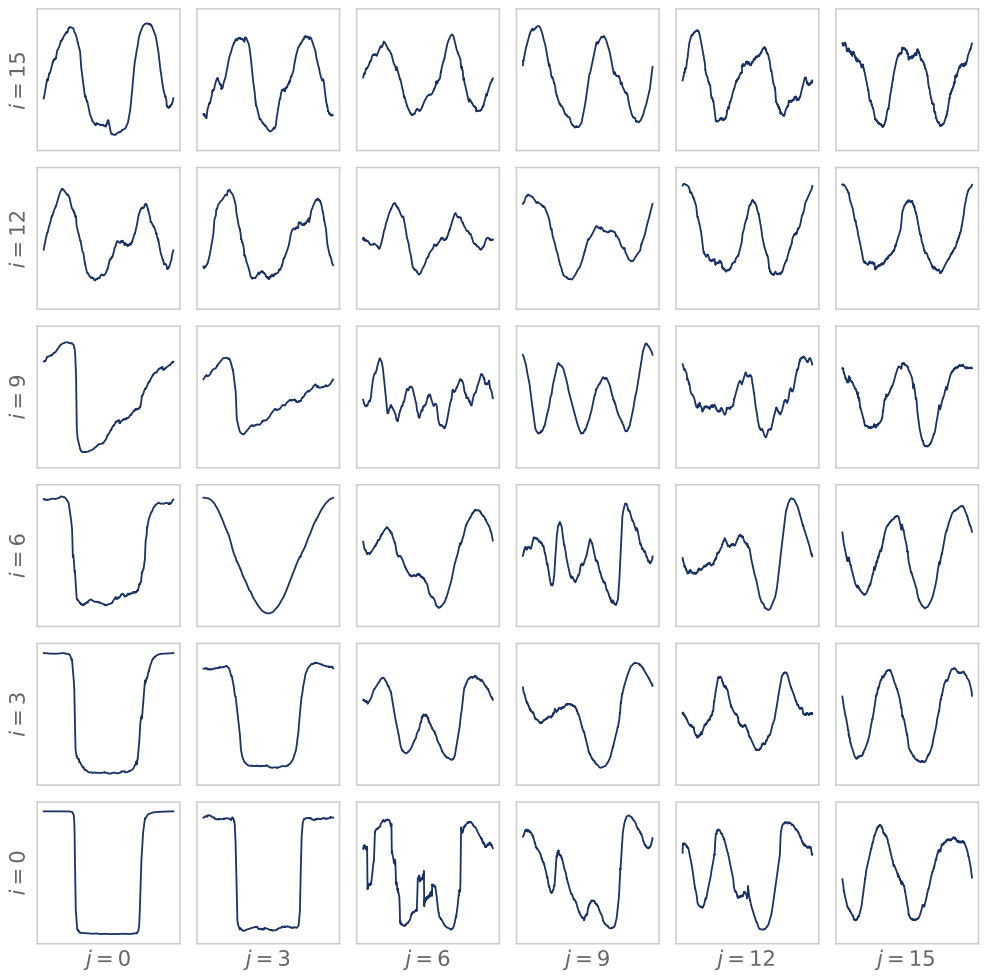
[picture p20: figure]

Figura 4.5: Contenido de la rejilla, dibujando uno de cada tres nodos en cada eje para que las ondas resulten legibles. El submuestreo permite ver la variedad de formas repartida por el plano, no la semejanza entre celdas contiguas.

## 4.9 Validación previa al embarque

Antes de llevar la rejilla al hardware convenía escucharla. Para eso se escribió 5_demo_morph.py que reproduce en el ordenador exactamente lo que después hará el instrumento. Usando el ratón en lugar del dedo, haciendo interpolación bilineal entre las cuatro celdas vecinas y usando un acumulador de fase que cambia de tabla sin reiniciarse. Trabajar así permite separar los problemas del modelo de los del firmware, porque cualquier defecto que aparezca en esta demostración es necesariamente del modelo o de la rejilla.

La primera escucha dio un aviso. Al recorrer el plano, todas las posiciones sonaban bastante parecidas. Ese síntoma puede venir por dos causas muy distintas y conviene no confundirlas. Podía ser que la rejilla estuviera colapsada, con todo el plano decodificando prácticamente la misma onda pese a lo que indicaba la divergencia. O podía ser un efecto perceptual, porque el tono de prueba estaba fijado en 110 Hz y a esa altura los armónicos quedan tan juntos que timbres distintos tienden a fundirse al oído.

29

CAPÍTULO 4. MODELO NEURONAL

Para distinguirlas se añadieron tres pruebas de diagnóstico a la propia demostración. Un osciloscopio que dibuja la onda interpolada en tiempo real, así se puede ver si la forma cambia aunque el oído no lo note. Un arpegiador con el tono base subido a 220 Hz para escuchar un recorrido en un registro donde los armónicos se separan. Y un medidor de diversidad que calcula la distancia RMS entre la onda actual y la onda media de la rejilla, junto a una sonda que compara las cuatro esquinas al arrancar.

Las medidas descartaron el colapso. La distancia RMS entre las cuatro esquinas de la rejilla va de 0,63 a 1,04 según el par que se compare, y la diversidad respecto a la onda media recorre de 0,18 a 0,68 al barrer el plano. Sobre ondas normalizadas en [−1, 1] son diferencias grandes, no matices. Al subir el tono, la variación tímbrica pasó a ser evidente también al oído, con lo que la causa quedó identificada como perceptual y atribuible al tono grave de la prueba inicial.

Con esa verificación, la fase de preparación queda cerrada. El resultado que pasa al resto del sistema es un único archivo, la cabecera con las 256 tablas y los límites del plano latente, que se compila junto al firmware del ESP32-S3 descrito en el capítulo siguiente.

30

# Capítulo 5

# Firmware de control: ESP32-S3 y CYD

Este capítulo recorre las dos placas que convierten un dedo apoyado sobre un cristal en una forma de onda lista para sonar. El reparto de tareas entre procesadores, la elección del medio de cada enlace y el tamaño de las tramas ya quedaron justificados en el capítulo 3, en los apartados 3.3 y 3.6. Aquí interesa el cómo, es decir, cómo se lee y se calibra el táctil, cómo se localiza la celda de la rejilla y se mezclan sus vecinas, cómo se construyen las tramas y cómo se reduce la onda para dibujarla. Todo lo que sigue corresponde a la fase de ejecución descrita en el apartado 3.4, en la que no interviene ninguna red neuronal.

## 5.1 Lectura y calibración del táctil

La CYD es una placa genérica sin manual de fabricante, cuya documentación es comunitaria [13], así que los pines se confirmaron uno a uno contra el esquemático que la acompaña. Integra una pantalla TFT de 240×320 puntos y, encima de ella, una lámina táctil resistiva. Esa lámina no entrega una posición, sino una tensión que cambia según dónde se apoye el dedo, y quien la traduce a número es un XPT2046, un conversor analógico-digital de 12 bits [14]. Doce bits dan 4096 valores, de modo que cada eje se lee como un entero entre 0 y 4095. Conviene retener que esos números no son píxeles ni milímetros, sino cuentas del conversor. De ahí sale todo lo que viene después, calibrar consiste precisamente en averiguar qué cuenta corresponde a cada borde.

La pantalla y el táctil son dos chips distintos y cada uno se comunica con el ESP32 por su propio bus SPI. La placa dispone de dos utilizables, llamados VSPI y HSPI, y aquí se usa uno para cada cosa. El táctil se queda en el VSPI, que es donde lo dejó cableado el fabricante, y la pantalla se lleva el HSPI. El reparto no es opcional porque la librería de la pantalla, TFT_eSPI [15], toma el VSPI por omisión y sin forzarla los dos chips acabarían disputándose el mismo bus. El HSPI sale además ganando, ya que los pines 12 a 15 son los que el ESP32 tiene reservados para él [16] y eso les da una conexión interna directa, más rápida que la ruta genérica. El táctil se lee con la librería de Stoffregen [17].

Esa configuración vive en el fichero de proyecto de PlatformIO y no en el User_Setup.h de la librería, que es donde normalmente se pone. El motivo es práctico. Ese fichero se instala dentro del directorio de dependencias descargadas, fuera del control de versiones, de modo que la configuración se perdería al reinstalar la librería o al clonar el proyecto en otro ordenador. Declarándola

31

CAPÍTULO 5. FIRMWARE DE CONTROL: ESP32-S3 Y CYD

como definiciones de compilación viaja con el repositorio. Hay además un detalle de la placa que conviene no reaprender, y es que la retroiluminación arranca apagada. La pantalla puede estar pintando perfectamente y verse negra, indistinguible de un cuelgue, así que se enciende a mano en la primera línea del arranque. Justo después se dibuja un patrón de barras de color con un marco, que permite validar el controlador, la orientación y los colores sin depender todavía del ESP32-S3.

### 5.1.1 De las cuatro esquinas a las dos ventanas

La primera calibración se hizo tocando las cuatro esquinas del cristal con un puntero, que al tener un área de contacto pequeña da lecturas más extremas y limpias que el dedo. De ahí salieron los límites 133 a 3947 en el eje horizontal y 193 a 3897 en el vertical.

Esos números dejaron de valer cuando la placa se montó girada 180 grados en el panel, decisión de montaje que se explica en el capítulo 7 y que busca alejar el conector USB de la pantalla OLED. Al girar la imagen hay que girar también el táctil, y aquí apareció un hallazgo que ahorró trabajo. La librería sí aplica la rotación a las lecturas crudas, restándolas de 4095, lo que evita invertir el mapeo a mano. Pero, por eso mismo, los cuatro límites de calibración quedan espejados y hay que rehacerlos cruzando mínimo con máximo, con lo que pasan a 148 a 3962 y 198 a 3902.

Falta descontar lo que el panel tapa. Con la placa ya montada, tocando las cuatro esquinas del hueco, el área que asoma resultó ir de 450 a 3730 en los dos ejes. Se intentó afinar esquina por esquina y se descartó porque las lecturas no cuadraban entre sí, señal de que el táctil está algo girado respecto al hueco y un mapeo rectangular no corrige un giro. Apareció además un problema que ese recorte no resolvía. El labio impreso que apoya sobre el cristal en todo el perímetro genera pulsaciones fantasma pegadas al borde, una de ellas medida en (3714, 643), es decir dentro del área que se había dado por buena. Filtrar por presión habría sido la salida evidente, pero la estimación que da el XPT2046 en esta placa es poco fiable y un umbral mal ajustado podía dejar el táctil mudo.

La solución fue dejar de usar un solo rectángulo y separar dos, recogidos en la Figura 5.1. La ventana visible, de 450 a 3730, describe lo que asoma por el hueco y solo se emplea para calcular el área de dibujo. La ventana de captura, de 600 a 3580, decide qué toques se dan por buenos y deja 150 cuentas de margen por cada lado, unos 2,5 mm. El fantasma medido queda fuera de ella con 134 cuentas de holgura.

El detalle que hace que esa holgura no cueste nada es cuál de las dos ventanas se mapea al rango de la coordenada. Se mapea la de captura, no la visible, de modo que el espacio latente se sigue alcanzando entero de extremo a extremo y lo único que se pierde son esos 2,5 mm de recorrido del dedo por lado. Mapear la visible habría dejado las esquinas del plano inalcanzables, que es justamente el defecto que la recalibración venía a quitar. Y el rechazo es total, no un recorte. La versión anterior sujetaba la lectura al rango con una función de saturación, así que un contacto del plástico se enviaba igual, clavado contra el borde del espacio latente. Ahora un toque fuera de la ventana de captura no genera envío ni repinta nada, y el instrumento se queda exactamente como estaba.

El táctil se atiende cada 50 ms, sin bloquear el bucle, y solo se envía coordenada cuando el punto se ha desplazado más de 300 unidades respecto al último enviado. Como una celda de la rejilla ocupa 4369 unidades del rango de 16 bits, ese umbral es menos de la décima parte de una celda, suficientemente fino para que el recorrido se perciba continuo y suficientemente grueso para no saturar el enlace con la vibración de un dedo quieto.

32

5.2. DE LA COORDENADA A LA CELDA
0 | 1024 | 2048 | 3072 | 4095

## cuentas crudas del eje X

0

1024

2048

3072

4095

## cuentas crudas del eje Y

pulsación fantasma
crudo (3714, 643)

### cristal completo (148 – 3962) ventana visible (450 – 3730) ventana de captura (600 – 3580)

Figura 5.1: Las dos ventanas del táctil sobre el plano de cuentas crudas del convertidor. La de captura decide qué toques valen y es la que se mapea al rango de la coordenada; la visible solo sirve para acotar el área de dibujo. La pulsación fantasma medida cae dentro de la visible y fuera de la de captura.

## 5.2 De la coordenada a la celda

La CYD normaliza la lectura al rango de 16 bits antes de enviarla, y esa decisión tiene una consecuencia comprobada. Ni el giro de 180 grados ni la recalibración de banco obligaron a tocar una sola línea del firmware del ESP32-S3, porque este sigue recibiendo el mismo rango de siempre. Resolver el giro en el procesador de control habría roto la separación de responsabilidades del apartado 3.3 y habría dejado a la CYD enviando coordenadas que no se corresponden con lo que ella misma muestra.

Del lado del ESP32-S3, la trama de seis bytes descrita en el apartado 3.6 la decodifica una máquina de estados que busca el byte de cabecera, lee los cuatro de datos y valida la suma de comprobación. Ante cualquier fallo vuelve al estado inicial a buscar cabecera, de forma que un byte perdido descuadra una trama pero no el flujo. Conviene señalar que esa entrada también se puede hacer por USB. Aquí la coordenada se escribe a mano como texto mediante el puerto serie. Fue lo que permitió construir y validar la interpolación antes de que existiera el firmware de la CYD, y es también lo que hace posibles las medidas del capítulo 8, que necesitan una coordenada conocida y estable.

## 5.3 Interpolación bilineal sobre la rejilla

Localizar la celda es una multiplicación. La coordenada de 16 bits se escala por 15/65535, con lo que se obtiene la posición real dentro de la rejilla de 16 × 16. La parte entera de esa posición da la celda y la parte fraccionaria da el peso hacia la vecina siguiente. Los dos ejes se tratan de forma independiente, así que un punto asimétrico no recibe ningún trato especial.

33

CAPÍTULO 5. FIRMWARE DE CONTROL: ESP32-S3 Y CYD

El borde se resuelve sin caso particular. Cuando la coordenada vale el máximo, la posición escalada da exactamente 15, la vecina de la derecha se sujeta sobre sí misma y el peso hacia ella queda a cero. La operación sigue siendo la misma combinación de cuatro tablas, solo que dos de ellas coinciden y aportan peso nulo, con lo que no se sale del array ni hace falta una rama distinta.

Hay que respetar la disposición matricial de índices que fija la cabecera generada en el apartado 4.8, con la fila recorriendo el eje vertical y la columna el horizontal. Es el detalle más fácil de equivocar de todo el firmware y el que peor avisa cuando se equivoca, porque permutar los ejes no rompe nada visible. La interpolación sigue devolviendo formas de onda perfectamente válidas, solo que el espacio de timbres queda transpuesto bajo el dedo.

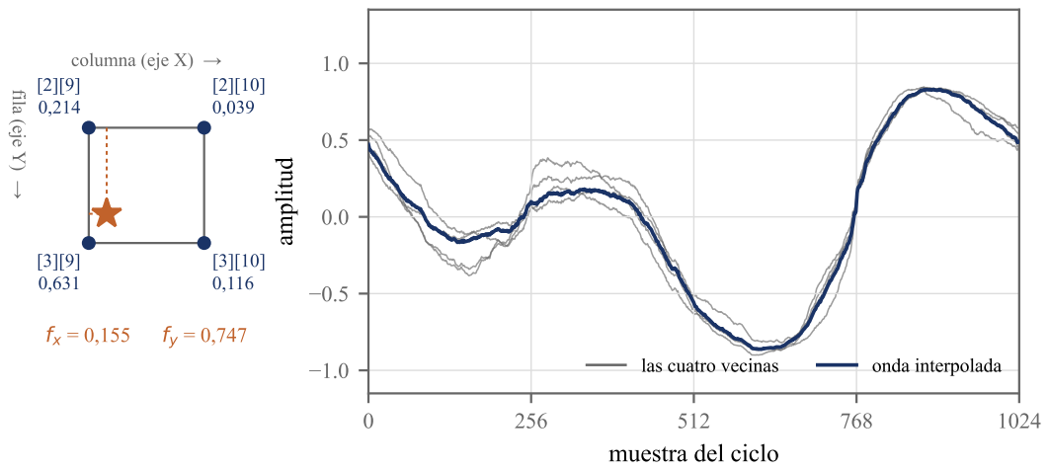
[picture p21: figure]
columna (eje X) →; fila (eje Y); muestra del ciclo; amplitud; las cuatro vecinas; onda interpolada

Figura 5.2: Interpolación bilineal para la coordenada (40000, 12000). A la izquierda, la celda alcanzada, los índices de las cuatro vecinas en la rejilla y el peso que recibe cada una. A la derecha, esas cuatro formas de onda y la que resulta de mezclarlas.

La Figura 5.2 muestra el resultado para la coordenada con la que después se validó el enlace. Cae en la celda que va de la columna 9 a la 10 y de la fila 2 a la 3, con pesos de 0,155 y 0,747, de modo que la vecina inferior izquierda se lleva 0,631 de la mezcla y la superior derecha apenas 0,039. Se aprecia que la onda resultante no es una de las cuatro ni un promedio simple, sino que sigue de cerca a la que más pesa.

Merece una aclaración cómo se hace la aritmética, porque el formato de almacenamiento y el de cálculo no coinciden. Las tablas se guardan como enteros de 16 bits en formato Q15, pero la mezcla se calcula en coma flotante de 32 bits y solo se redondea al pasar el resultado a Q15, una vez por muestra. El ESP32-S3 tiene unidad de coma flotante en hardware, así que las más de mil operaciones que esto cuesta son despreciables frente a los 1,6 ms que después ocupa la transferencia. Cabe recordar que el cálculo se ejecuta a frecuencia de control, unas decenas de veces por segundo como mucho, así que ese coste es irrelevante. La ventaja de hacerlo así es que cada muestra sufre un único redondeo en lugar de acumular el de cada paso intermedio. Tampoco hace falta saturar el resultado porque los cuatro pesos suman uno y están todos entre cero y uno. De este modo, la mezcla es una combinación convexa de cuatro valores que ya caben en Q15 y no puede salirse del rango.

La rejilla se compila como una constante de 16×16×1024 enteros de 16 bits, es decir los 512 kB del apartado 3.5, y vive en memoria de programa. En el ESP32-S3 la caché mapea esa memoria

34

5.4. EL CANAL DE VUELTA Y EL DIBUJO DE LA ONDA

al espacio de direcciones, de modo que se lee como cualquier otro array, sin las macros de acceso que exigen otras arquitecturas. En memoria de datos quedan la tabla de trabajo y los dos búferes de trama, unos cuatro kilobytes. La PSRAM de 8 MB de la placa no llega a intervenir en el camino principal y queda como margen para la ampliación planteada en el apartado 3.2.

Para comprobar que esta implementación es correcta no basta con ver que produce algo. Se escribió una reimplementación independiente en numpy que recalcula la misma interpolación sobre el fichero de la rejilla y se compara muestra a muestra con el volcado que el ESP32-S3 imprime por USB. Es una comprobación de equivalencia frente a una referencia, no de plausibilidad. El resultado se recoge en el capítulo 8.

## 5.4 El canal de vuelta y el dibujo de la onda

Lo que el ESP32-S3 devuelve a la pantalla es dato de representación, nunca de síntesis. La rejilla y la interpolación siguen viviendo solo en el procesador de control, y la forma de onda real únicamente sale hacia el procesador de audio por SPI. El enlace con la CYD ya era bidireccional, así que abrir el sentido de vuelta no costó más que añadir el hilo y un emisor.

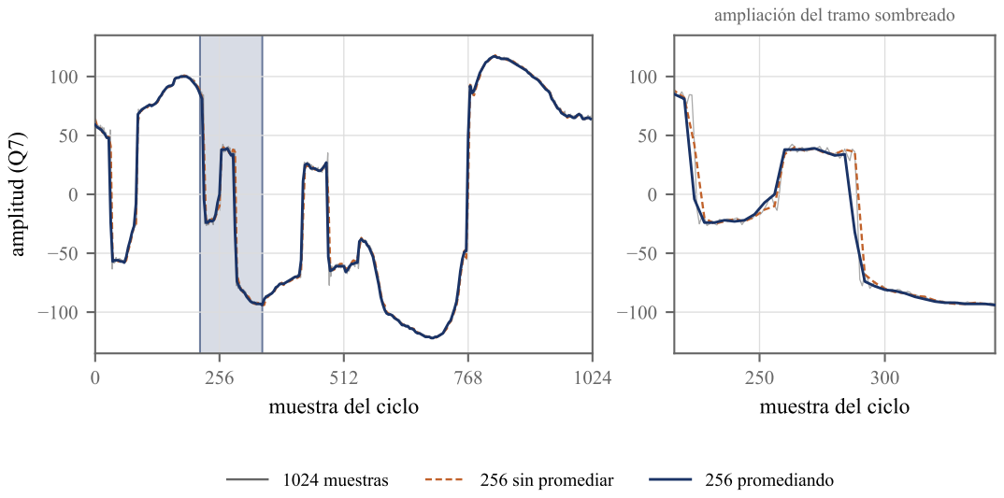
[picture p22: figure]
muestra del ciclo; amplitud (Q7); ampliación del tramo sombreado; 1024 muestras; 256 sin promediar; 256 promediando

Figura 5.3: Reducción de 1024 a 256 puntos para dibujar, sobre el nodo de la rejilla en el que más se separan los dos métodos. Promediar cada grupo de cuatro muestras y quedarse con una de cada cuatro dan prácticamente lo mismo en el grueso del ciclo, y difieren en los flancos.

Reducir la onda a 256 puntos, cuyo porqué se explicó en el apartado 3.6, admite dos maneras. La inmediata es quedarse con una muestra de cada cuatro y descartar las otras tres. La que se usa aquí es promediar cada grupo de cuatro, que cuesta prácticamente lo mismo y no tira información por el camino. Cada muestra pasa además de 16 a 8 bits conservando la mitad alta. La Figura 5.3 enfrenta los dos métodos sobre el nodo de la rejilla en el que más se diferencian. En casi todo el ciclo coinciden, y la separación se concentra en los tramos de pendiente fuerte, donde alcanza 68 cuentas sobre una amplitud máxima de 122. Descartar muestras no haría irreconocible el dibujo, pero desplazaría los flancos, que es justamente donde se aprecia si una onda es cuadrada, de sierra o de pulso.

35

CAPÍTULO 5. FIRMWARE DE CONTROL: ESP32-S3 Y CYD

Dos tropiezos de esta parte tienen causa identificada y merece la pena dejarlos escritos. El primero fue que no llegaba ninguna trama buena, no que llegaran corruptas. El buffer de recepción del puerto serie en esta plataforma es de 256 bytes por omisión, justo por debajo de los 260 que ocupa la trama, y hay que agrandarlo antes de abrir el puerto. El segundo fue que las tramas se perdían solo mientras el dedo se movía, que es justo cuando llegan. La causa era una espera bloqueante en la lectura del táctil, que desatendía la recepción durante ese tiempo; se sustituyó por una temporización no bloqueante.

El repintado se hace en dos pasadas, borrando entera la traza anterior con el color de fondo antes de dibujar la nueva. Repintar el área de golpe con un rectángulo relleno produce parpadeo en cada trama, y borrar e ir pintando de forma intercalada se come trozos de la línea nueva allí donde las dos se cruzan. El borrado arrastra también los puntos de la línea central de referencia, que se repintan sobre la marcha.

Queda el encaje con el panel. Como este tapa un borde del cristal, dibujar sobre la pantalla completa dejaría parte de la interfaz debajo del plástico, así que el área útil se acotó a los píxeles que salen de convertir la ventana visible de la Figura 5.1. Dentro de ella se reparten un título, una banda de estado con la coordenada, el número de secuencia y el contador de tramas descartadas, y el recuadro de la onda. El patrón de arranque cierra el asunto de forma barata, porque dibuja un marco blanco justo en el límite del área útil y basta con ver si los cuatro lados asoman por la ventana para saber si las constantes cuadran con el hueco.
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

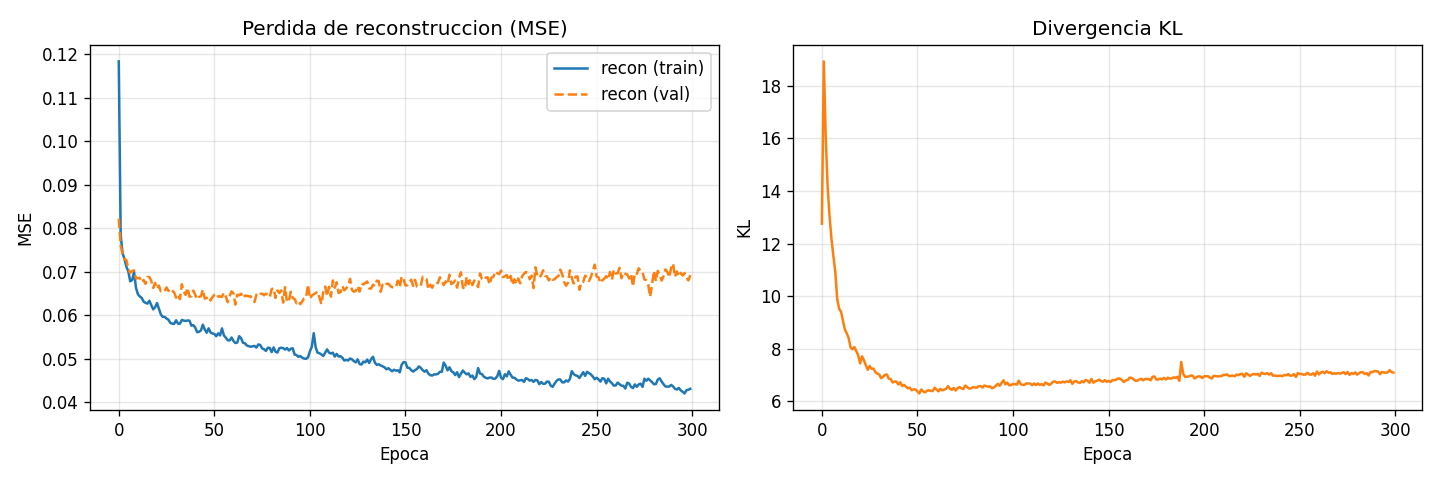
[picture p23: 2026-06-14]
ml/exports/loss_curve.png

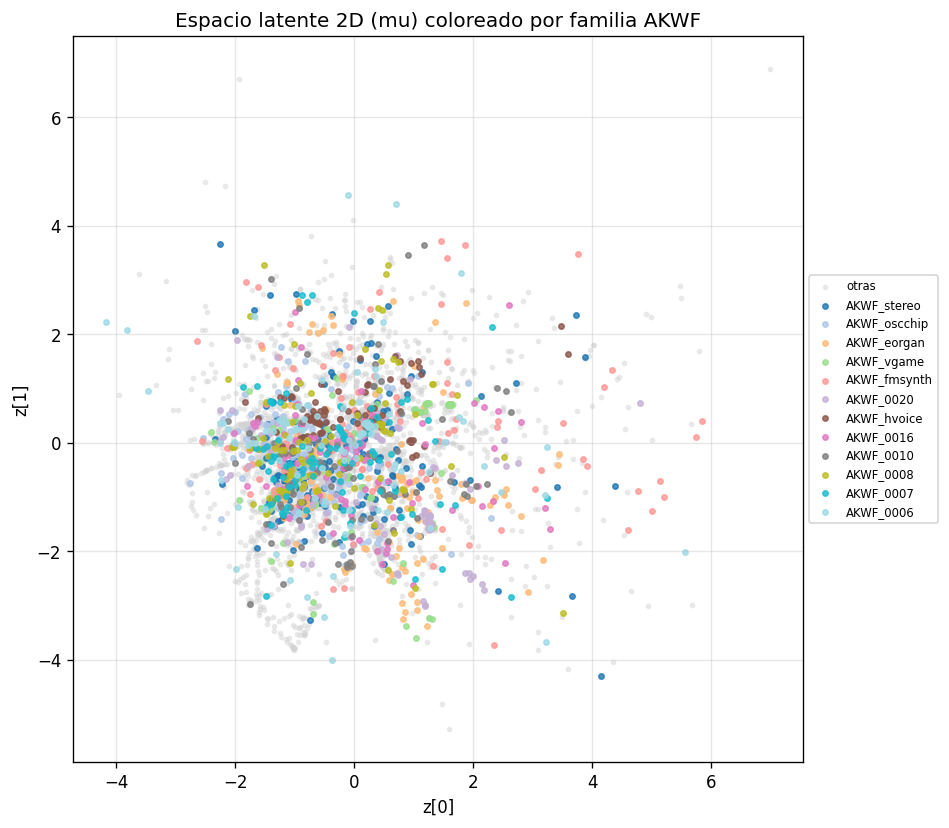
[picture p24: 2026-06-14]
ml/exports/latent_scatter.png

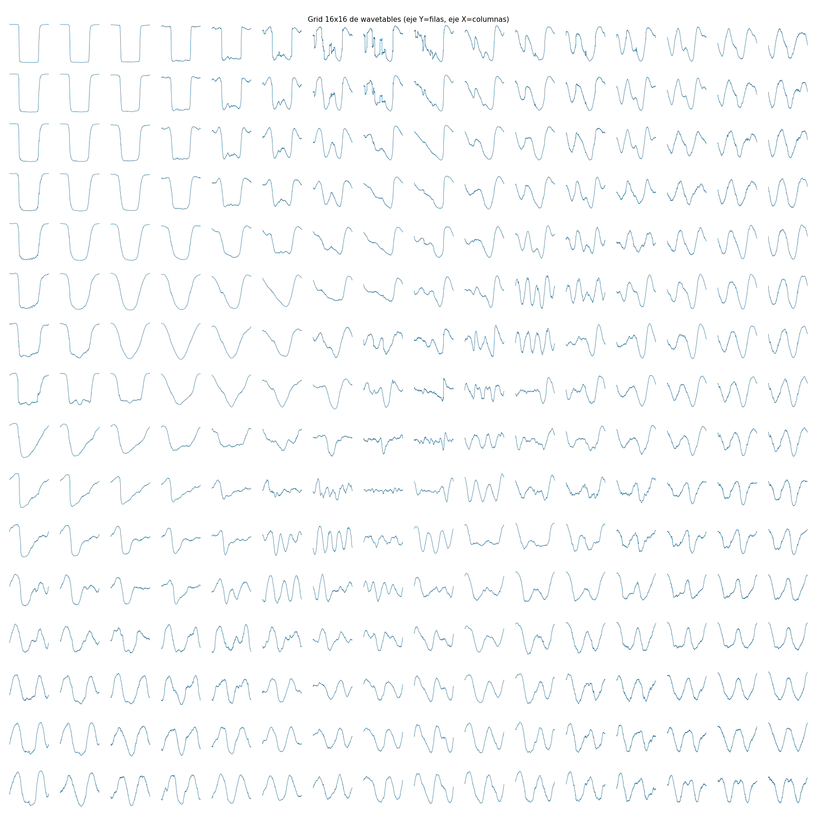
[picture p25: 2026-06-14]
ml/exports/grid_preview.png

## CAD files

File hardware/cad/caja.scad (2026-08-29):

// ============================================================================
//  caja.scad -- Cuerpo del Sintetizador de Espacio Latente
//  TFG - Bloque C - 23 ago 2026.  Complementa a panel.scad.
//
//  Cuna estilo Moog: 30 mm delante, 62 detras, 16,0 grados, mas una BAHIA
//  TRASERA plana de 58 mm donde vive el shield MIDI TUMBADO. Quedan tres
//  cotas del shield por medir (marcadas en el bloque 4) antes de imprimirla.
//
//  TRES piezas, y ninguna necesita soportes:
//    "bandeja"          -> suelo + frontal + laterales. Se imprime con el
//                          suelo sobre la cama.
//    "trasera_carcasa"  -> pared trasera + cubierta + los dos laterales de la
//                          bahia. Se imprime TUMBADA SOBRE LA CARA EXTERIOR:
//                          asi la cubierta y los laterales son paredes
//                          verticales y los huecos del DIN salen como
//                          agujeros verticales pasantes, sin puentes.
//    "trasera_suelo"    -> la plancha del suelo de la bahia con los pilares,
//                          los tacos de tope y las columnas. Plana sobre la
//                          cama, columnas hacia arriba.
//  La trasera se parte en dos porque de una pieza la cubierta de la bahia es
//  un voladizo de 63 mm. Partida, cada mitad va en su orientacion natural.
//
//  Nada de separadores de nylon ni de taladros en la veroboard: esta entra
//  deslizando sobre repisas impresas, y el shield MIDI va tumbado sobre
//  pilares con una costilla de tope detras. Los tornillos van siempre contra
//  TUERCA EMBUTIDA, nunca roscando en el plastico.
//
//  F5 previsualiza - F6 renderiza - File > Export > Export as STL
// ============================================================================

/* [1. Que pieza exportar] */
part = "conjunto";   // [bandeja, trasera_carcasa, trasera_suelo, conjunto, conectores, trasera]

/* [2. Caja] */
box_w    = 186;    // = ancho del panel
panel_d  = 116;    // = fondo del panel (medido sobre la pendiente)
h_front  = 44;     // altura de la pared delantera
h_back   = 62;     // altura de la pared trasera
// Fondo de la bahia trasera, por detras del panel.
// El video del 24 ago demostro que el shield va TUMBADO, no de pie: sus DIN
// salen paralelos a la PCB, por el canto, asi que de pie apuntarian al techo.
// Tumbado ocupa 57,4 de fondo, y con bay_d = 30 solo habia 33,5 libres.
// Con 58 quedan 60,5: entran los 57,4 y sobran 3 de aire a la veroboard.
// 66 y no 58: con 58 la huella del shield (57,4 + 3 de tope = 60,4) era mas
// larga que la bahia util y CRUZABA la linea de particion, dejando media
// sujecion en cada pieza. Con 66 la bahia util es de 63 y el montaje entero
// queda dentro de la TRASERA, que se imprime de una pieza.
// La linea de particion bandeja/trasera ya NO es el borde del panel: se
// retrasa a split_y para que las cabezas de las torres del panel quepan
// enteras en la bandeja. La bahia crece en consecuencia.
split_y  = 118;
bay_d    = 72;
wall     = 3;      // espesor de pared
floor_t  = 3;      // espesor del suelo
panel_t  = 3.4;    // debe coincidir con panel.scad

/* [3. Veroboard] */
board_w  = 166;  board_h = 100;   // 166 a lo largo de X, 100 a lo largo de Y
board_x0 = 13;   board_y0 = 5;    // esquina delantera izquierda
board_t  = 1.5;                   // espesor de la baquelita
rail_z   = 8;                     // cara inferior de la placa sobre el suelo
                                  // (8 - 3 de suelo = 5 mm para los rabillos)
// La veroboard NO esta taladrada, asi que no hay tornillos: entra DESLIZANDO
// por detras (con la trasera desmontada) y la propia trasera hace de tope.
// Para que eso sea posible, la sujecion tiene que ser un CANAL de seccion
// constante y abierto por detras. Cada canto lleva tres piezas:
//   repisa -> apoya la placa por la cara de cobre
//   pilar  -> pared vertical PEGADA AL LATERAL DE LA CAJA, en los 10 mm
//             libres que hay entre la pared (x=3 / x=183) y el canto
//   pinza  -> labio que vuela sobre la cara de componentes e impide que la
//             placa se levante una vez dentro
// El pilar va SIEMPRE por fuera de la huella de la placa. (26 ago: las
// pestanas antiguas nacian DENTRO de esa huella y hacian el montaje
// fisicamente imposible; ver la nota larga en board_rails.)
//
// Margenes de baquelita limpia, medidos en las DOS caras (26 ago):
//   cara de cobre (donde pisa la repisa) -> 12 mm en el canto
//     x = board_x0 + board_w y 24 mm en el canto x = board_x0
//   cara de componentes (donde pisa la pinza) -> 12 mm en los dos cantos
// Por debajo los dos cantos estan limpios en los 100 mm de largo, asi que
// las DOS repisas corren la placa entera. Esto corrige la nota anterior,
// que limitaba el apoyo del canto x = board_x0 a 42 mm.
rail_w_right = 8;    // < 12 medidos
rail_w_left  = 8;    // < 24 medidos
board_side_gap = 0.5;  // aire lateral por cada lado, entre canto y pilar
// La PINZA si tiene un lado corto: el zocalo de 22 pines va pegado a uno de
// los cantos por la CARA DE COMPONENTES y solo deja limpios 42 mm de ese
// canto. Ahi la pinza mide tab_len_socket; en el otro canto corre los 100.
//
// DONDE VA EL ZOCALO (fijado por el autor el 26 ago): mirando el
// instrumento de frente, con la placa puesta y la cara de componentes hacia
// arriba, el zocalo queda en la esquina TRASERA DERECHA. Es decir: canto
// x = board_x0 + board_w, y en la mitad de ATRAS de ese canto -- es lo
// ultimo que entra al deslizar.
//
// Y no podria ser de otra forma: los 42 mm limpios TIENEN que ser los
// delanteros. Si el zocalo cayera en la mitad delantera, ese canto no
// admitiria pinza de ninguna longitud, porque el zocalo tendria que pasar
// por debajo de ella durante la insercion.
socket_side    = "right"; // [left, right]  canto donde vive el zocalo de 22
                          // "right" = x = board_x0 + board_w
tab_len_socket = 40;      // el canto limpio son 42; se dejan 2 de margen
tab_over = 4.0;   // cuanto pisa la pinza sobre la placa
tab_t    = 2;     // espesor de la pinza
tab_gap  = 0.8;   // aire entre la cara de componentes y la pinza. Generoso a
                  // proposito: la cara baja de la pinza es un voladizo de
                  // 3,5 mm y su primera capa descuelga algo al imprimir
tab_lead  = 2;    // chaflan de entrada de la pinza (= tab_t -> 45 grados)
rail_lead = 3;    // rampa de entrada de la repisa. Sube los 5 mm en 3 y no
                  // pasa nada: es una cara vista POR ABAJO, cada capa es
                  // mas corta que la anterior, no hay voladizo. Corta,
                  // para dejar 97 de los 100 con apoyo plano

/* [4. Shield MIDI -- TUMBADO] */
// El video del 24 ago fijo la postura: la placa va TUMBADA (PCB horizontal),
// los pines de la tira colgando hacia abajo, y los DIN salen PARALELOS a la
// PCB por uno de sus cantos. Ese canto se apoya contra la trasera y los DIN
// atraviesan la pared.
//
// CERTEZA ALTA (se ve en el video y en la foto acotada):
shield_pcb_t   = 1.2;    // espesor de la PCB del shield
shield_pin_drop = 9;     // cuanto cuelgan los pines por debajo de la PCB
din_sq   = 20;         // cuerpo del DIN, cuadrado
din_clear = 0.6;
din_pitch = 22.0;        // 19,5 de cuerpo + 2,5 de aire, centro a centro
din_count = 2;           // IN y OUT, UNO AL LADO DEL OTRO en horizontal
din_z_over_pcb = 9.75;   // centro del DIN sobre la cara superior de la PCB
shield_floor_gap = 12;    // aire entre la punta de los pines y el suelo

// !! PENDIENTE DE MEDIR -- estos tres son estimaciones, no medidas:
shield_w = 53.1;   // canto que apoya contra la trasera (57,4 o 53,1?)
shield_d = 57.4;   // cuanto entra hacia dentro de la caja
shield_x = 75;     // centro de la placa en X
// Del canto izquierdo de la placa al centro del DIN de IN. El autor midio
// ~15,5 pero sin fijar desde que canto con la placa ya en su postura.
din_from_left = 15.6;
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

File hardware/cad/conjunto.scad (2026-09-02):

// ============================================================================
//  conjunto.scad -- Vista de montaje del Sintetizador de Espacio Latente
//  TFG - Bloque C - 23 ago 2026
//
//  NO GENERA PIEZAS PARA IMPRIMIR. Es un visor: monta el panel sobre la caja,
//  permite separarlas y deja elegir el color de cada una para decidir que
//  filamento comprar antes de gastarlo.
//
//  Las piezas de verdad salen de panel.scad y caja.scad, cada una con su
//  parametro "part". Este fichero solo las llama.
//
//  F5 y a mirar. F6 no hace falta.
// ============================================================================

use <panel.scad>
use <caja.scad>

/* [1. Vista] */
// "montado"      -> todo en su sitio
// "explosionado" -> el panel levantado y la trasera separada
// el resto -> una sola pieza, para mirarla de cerca
vista   = "montado";   // [montado, explosionado, panel, bandeja, trasera]
explode = 40;          // separacion en la vista explosionada

/* [2. Colores] */
// Cambia estos tres y mira. Elige "custom" en cualquiera para que use el
// hex de la casilla de abajo en vez de la lista.
col_panel  = "naranja";   // [naranja, negro, gris, blanco, plata, azul, rojo, verde, amarillo, madera, custom]
col_caja   = "negro";     // [naranja, negro, gris, blanco, plata, azul, rojo, verde, amarillo, madera, custom]
col_letras = "negro";     // [negro, blanco, plata, rojo, amarillo, naranja, custom, ninguno]

// Solo se leen cuando el desplegable de arriba correspondiente esta en
// "custom". Formato hex de 6 cifras, con o sin '#'.
col_panel_hex  = "#e4610f";
col_caja_hex   = "#1a1a1a";
col_letras_hex = "#ffffff";

/* [3. Que se ensena] */
show_letras  = true;   // el relleno del grabado (simula el rotulador)
show_modulos = true;   // pantalla de la CYD y del OLED, en negro

/* [4. Cotas de la caja -- DEBEN COINCIDIR con caja.scad] */
box_w    = 186;
panel_d  = 116;
h_front  = 44;
h_back   = 62;
bay_d    = 72;
panel_t  = 3.4;

/* [Hidden] */
$fa = 2; $fs = 0.5;

deep    = sqrt(panel_d*panel_d - (h_back - h_front)*(h_back - h_front));
ang     = atan((h_back - h_front) / deep);
hf_wall = h_front - panel_t / cos(ang);

// Colores de filamento aproximados, mirados sobre bobinas reales.
// "custom" tira del hex escrito a mano en la casilla que le corresponde.
function hexof(n, custom = "#cccccc") =
      n == "custom"   ? custom
    : n == "naranja"  ? "#e4610f"
    : n == "negro"    ? "#1a1a1a"
    : n == "gris"     ? "#6e7378"
    : n == "blanco"   ? "#edede8"
    : n == "plata"    ? "#a8adb3"
    : n == "azul"     ? "#1b4f8c"
    : n == "rojo"     ? "#b0201e"
    : n == "verde"    ? "#1f6f4f"
    : n == "amarillo" ? "#e8b517"
    : n == "madera"   ? "#9c6b3f"
    :                   "#cccccc";

// ---------------------------------------------------------------------------
// El panel, colocado sobre el plano de apoyo de la caja.
// El giro es +ang alrededor de X: asi la y local del panel (que corre sobre
// la pendiente) cae sobre la pendiente real, y su z local apunta hacia fuera.
// ---------------------------------------------------------------------------
module place_panel(lift = 0) {
    translate([0, -lift * sin(ang), hf_wall + lift * cos(ang)])
        rotate([ang, 0, 0])
            children();
}

module panel_pintado(lift = 0) {
    place_panel(lift) {
        color(hexof(col_panel, col_panel_hex)) panel();
        if (show_letras && col_letras != "ninguno")
            color(hexof(col_letras, col_letras_hex)) label_ink();
    }
}

// Pantallas, para hacerse una idea de como contrastan con el color elegido.
// Cotas copiadas de panel.scad; si las cambias alli, aqui solo es la vista.
module pantallas(lift = 0) {
    place_panel(lift) {
        color("#0b0b0d") {
            translate([11 + 13.5, 56 + 2.5, panel_t - 0.4])
                cube([59.5, 45, 0.5]);
            // Aproximacion visual: el hueco real del OLED sale del STL
            // injertado en panel.scad (oled_frame_cut), no de un rectangulo.
            // Esto es solo una caja parecida para ver el contraste de color.
            translate([135 - 14, 90 - 7.25, panel_t - 0.4])
                cube([28.0, 14.5, 0.5]);
        }
    }
}

// ---------------------------------------------------------------------------
module todo(lift_panel = 0, back = 0) {
    panel_pintado(lift_panel);
    if (show_modulos) pantallas(lift_panel);
    color(hexof(col_caja, col_caja_hex)) bandeja();
    color(hexof(col_caja, col_caja_hex)) translate([0, back, 0]) trasera();
}

if (vista == "montado")            todo(0, 0);
else if (vista == "explosionado")  todo(explode, explode);
else if (vista == "panel")       { color(hexof(col_panel, col_panel_hex)) panel();
                                   if (show_letras && col_letras != "ninguno")
                                       color(hexof(col_letras, col_letras_hex)) label_ink(); }
else if (vista == "bandeja")       color(hexof(col_caja, col_caja_hex)) bandeja();
else if (vista == "trasera")       color(hexof(col_caja, col_caja_hex)) trasera();

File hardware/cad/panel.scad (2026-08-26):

    
   // ============================================================================
//  panel.scad -- Panel frontal del Sintetizador de Espacio Latente
//  TFG - Bloque C - 23 ago 2026
//
//  Se imprime PLANO sobre la cama, cara trasera abajo (z=0 es la cara que
//  mira a los componentes; z=panel_t es la cara vista, con las etiquetas).
//  Ender 3 V3 SE, 220x220. Boquilla 0,4 / capa 0,2.
//
//  F5 previsualiza - F6 renderiza - File > Export > Export as STL
//
//  NO lleva: DIN del MIDI, entrada de alimentacion, interruptor de red.
//  Esos tres van en la cara trasera de la caja (decidido el 23 ago).
// ============================================================================

/* [1. VERIFICAR CON EL PIE DE REY ANTES DE IMPRIMIR] */

// Diametro de la rosca del potenciometro. La ficha del WH148 dice M7x0,75.
// Si midiendo sale 6,0 hay que poner 6,0 aqui. NO imprimir sin comprobarlo.
pot_thread_d   = 7.0;
// Longitud de la parte roscada del pote. Limita el grosor del panel:
// grosor <= rosca - 3,0 (tuerca + arandela).
pot_thread_len = 7.0;   // MEDIDO 23 ago con pie de rey. Tuerca de 10 mm
                        // entrecaras -> M7x0,75 confirmado.
// Rosca del selector de filtro (toggle miniatura M6x0,75).
sw_thread_d    = 6.0;
// Rosca del jack de audio de 3,5 mm de chasis.
jack_thread_d  = 6.0;

/* [2. Panel] */

panel_w   = 186;    // ancho
panel_h   = 116;    // alto
panel_t   = 3.4;    // grosor (multiplo de 0,2)
corner_r  = 4;      // radio de las esquinas

// Taladros M3 para atornillar el panel al cuerpo de la caja (mas adelante)
mount_holes   = true;
mount_hole_d  = 3.2;
mount_inset   = 7;   // desde cada borde

/* [3. Potenciometros] */

pot_count   = 6;
pot_pitch   = 24;    // separacion entre centros
pot_x0      = 22;    // centro del primero
pot_row_y   = 24;    // altura de la fila
pot_clear   = 0.3;   // VALIDADO en probeta el 23 ago: el pote entra justo

// Espiga antigiro del pote. NO es redonda: es una pletina RECTANGULAR de
// 2,8 x 1,2 mm (medida el 23 ago), con el lado largo TANGENTE a la
// circunferencia del eje. La posicion (r = 7,8, angulo 90) esta validada
// sobre la probeta; lo unico que estaba mal era la forma.
pot_antirot     = true;
pot_antirot_w   = 2.8;   // lado largo, tangencial
pot_antirot_h   = 1.2;   // lado corto, radial
pot_antirot_clear = 0.4; // VALIDADO en probeta: 0,2 entra perfecta y 0,4 tambien.
                         // Se elige 0,4 porque el panel son seis ranuras en una
                         // sola impresion de 2,5 h: si una sale apretada, no hay
                         // segunda oportunidad. La tuerca es la que sujeta; que
                         // la pletina tenga 0,2 de juego no afecta a nada.
pot_antirot_r   = 7.8;   // del centro del eje al centro de la pletina
// 180 = pletina a la IZQUIERDA del eje. NO es indiferente: las tres patillas
// del pote salen a 90 grados de la pletina, asi que con la pletina arriba
// apuntan a la izquierda, hacia el pote vecino, y no caben dos seguidos.
// Con 180 las patillas apuntan HACIA ABAJO, perpendiculares a la fila: dejan
// de estorbarse entre ellas sea cual sea el paso, y los 24 mm se mantienen.
pot_antirot_ang = 180;

/* [4. Selector de filtro y jack] */

sw_x = 166;  sw_y = 24;
sw_clear = 0.3;
// Antigiro del toggle: la ficha lo acota, D2,4 a 6,4 mm del centro.
sw_antirot      = true;
sw_antirot_d    = 2.8;
sw_antirot_r    = 6.4;
sw_antirot_ang  = 90;

// El jack sale por el LATERAL de la caja, no por el panel (decidido el 23 ago).
// La geometria se deja aqui por si hay que devolverlo al frente: basta con
// poner jack_on_panel = true.
jack_on_panel = false;
jack_x = 168; jack_y = 62;
jack_clear = 0.3;

/* [5. OLED 0,96 pulgadas -- modulo de 26 x 26] */
// VALIDADO EN PROBETA (25 ago): estos valores dan el ajuste bueno. El cristal
// entra, queda a ras, el flex sale por su canal y los pines no chocan.
// NO tocar sin volver a imprimir una probeta.
// TODO EN MILIMETROS. Origen: el CENTRO de la PCB. dy positivo = hacia
// arriba (el lado de los pines). Tres niveles como la CYD: asiento de la
// PCB -> hueco del cristal entero -> labio con la ventana de pantalla.

// Posicion del centro de la PCB en el panel, eje X
oled_cx = 135;
// Posicion del centro de la PCB en el panel, eje Y
oled_cy = 90;
// Ancho de la PCB
oled_pcb_w = 26.0;
// Alto de la PCB
oled_pcb_h = 26.0;
// Holgura total del asiento de la PCB (la mitad por lado)
oled_pcb_clear = 0.8;
// Ancho del cristal que sobresale (todo lo gris del croquis)
oled_glass_w = 25.60;
// Alto del cristal
oled_glass_h = 17.6;
// Centro del cristal respecto al centro de la PCB (0 = centrado, y lo esta)
oled_glass_dy = 0;
// Holgura total del hueco del cristal
oled_glass_clear = 1.0;
// Cuanto LEVANTA el cristal sobre la cara de la PCB (3,5 total - 1,2 PCB - aire)
oled_glass_protr = 1.4;
// Ancho de la ventana del labio (pantalla util 21,74 + holgura)
oled_win_w = 22.2;
// Alto de la ventana (pantalla util 10,86 + holgura)
oled_win_h = 11.3;
// Centro de la pantalla util respecto al centro de la PCB: el cristal esta
// centrado pero la pantalla empieza a 1,5 de su borde superior -> +1,52
oled_win_dy = 1.52;
// Grosor del labio que pisa el cristal no-pantalla (3 capas de 0,2)
oled_lip_t = 0.6;
// Distancia entre CENTROS de taladros, horizontal. NO confirmada: asume
// 1,5 de cada borde. Si los agujeros no caen, medir y corregir esta
oled_hole_pitch_x = 22.6;
// Distancia entre centros de taladros, vertical (del croquis: 22.000)
oled_hole_pitch_y = 22;
// Centro de la parrilla de taladros vs centro de la PCB: arriba estan a
// 1,5 del borde y abajo a 2,5 -> la parrilla esta 0,5 subida
oled_hole_dy = 0.5;
// Broca del taladro. El OLED tiene agujeros de D2,0 -> tornillo M2: 2,4 de
// paso + 0,3 de contraccion. El 3,4 de antes pasaba por el panel pero NO por
// la placa (comprobado 25 ago)
oled_screw_d = 3;
// Descarga de las puntas de los pines: ancho (4 pines a 2,54 = 7,6 + margen)
oled_pin_w = 13;
// Descarga de pines: alto
oled_pin_h = 4;
// Descarga de pines: centro respecto al centro de la PCB (fila superior)
oled_pin_y = 10.5;
// Pared que queda por delante de las puntas de los pines
oled_pin_wall = 0.6;
// Escote del flex en el borde inferior: ancho (tab de 14 + margen)
oled_flex_w = 16;
// Escote del flex: cuanto se prolonga mas alla del borde de la PCB
oled_flex_ext = 1;

// caja util para dimensionar las probetas
oled_ref_w = oled_pcb_w + 12;  oled_ref_h = oled_pcb_h + 12;  oled_ref_t = 5.2;

/* [6. CYD (ESP32-2432S028R)] */
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

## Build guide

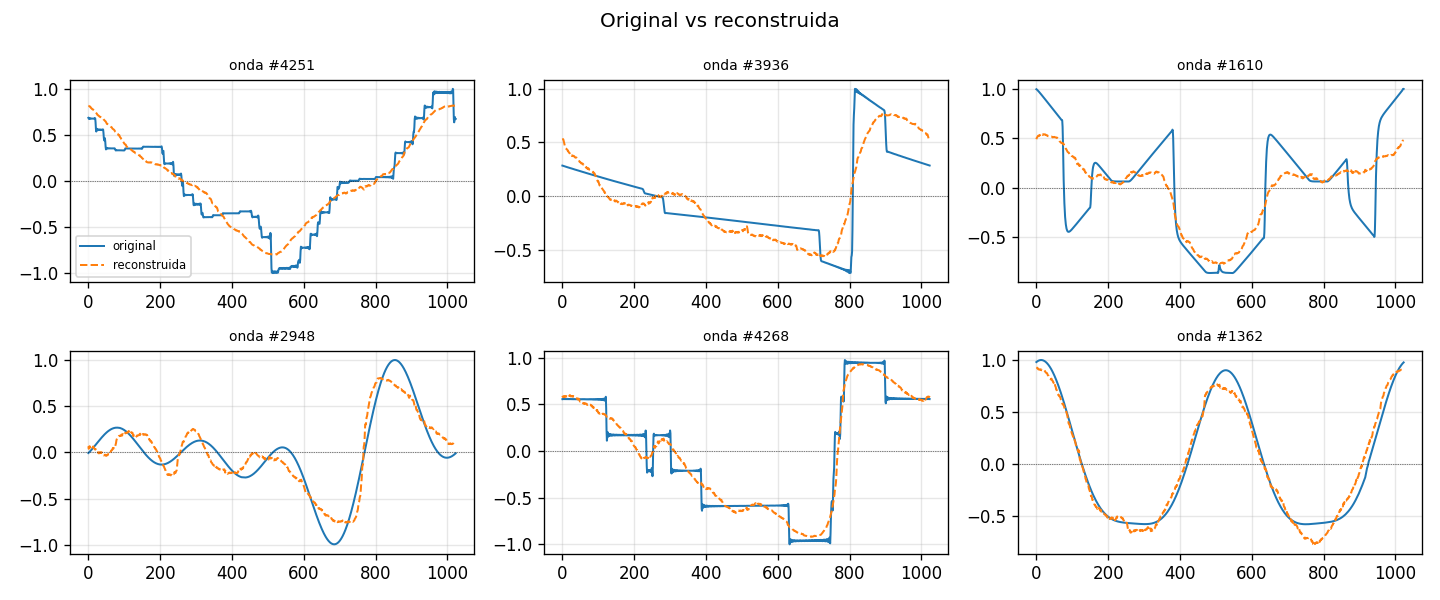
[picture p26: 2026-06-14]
ml/exports/reconstructions.png

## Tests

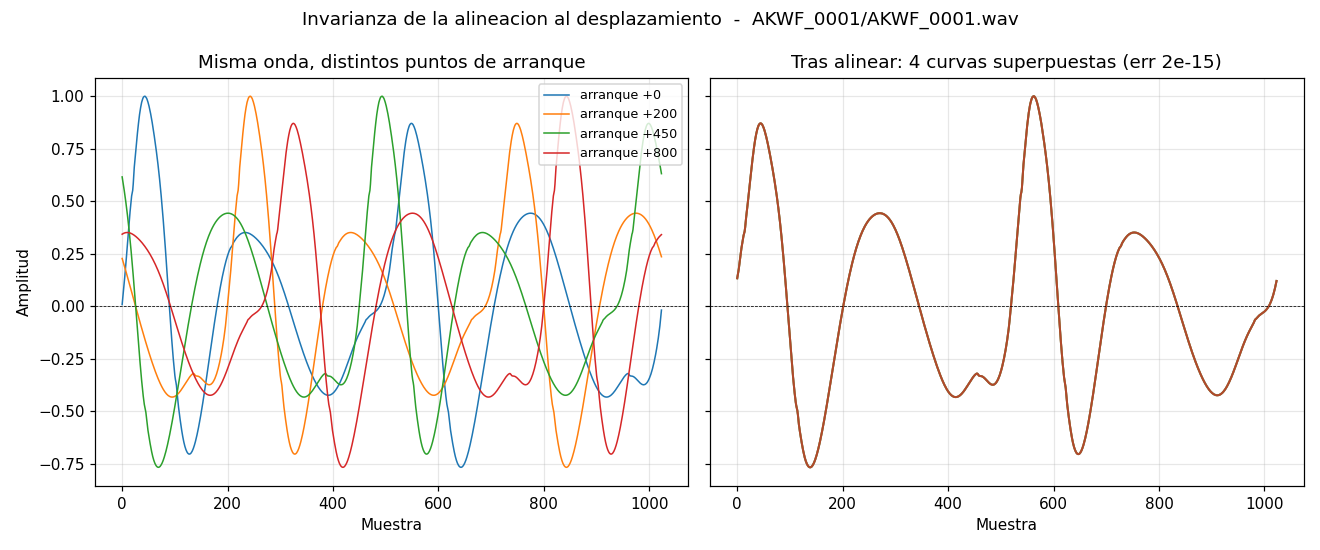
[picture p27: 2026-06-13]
ml/scripts/alignment_validation.png

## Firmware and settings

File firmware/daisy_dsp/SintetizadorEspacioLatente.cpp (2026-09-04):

// SintetizadorEspacioLatente.cpp - Firmware del Daisy Seed: motor wavetable
// con crossfade, receptor SPI de wavetables (esclavo, DMA), voz monofonica MIDI
// con ADSR, filtro Svf gobernado por un panel de potenciometros y OLED por I2C.
//
// Cadena de audio: osc -> Svf -> ADSR (VCO -> VCF -> VCA). Dos fuentes de
// control independientes que conviven sin pisarse:
//   - MIDI    -> osc.SetFreq()   (frecuencia de la voz monofonica y gate del ADSR)
//   - CYD/SPI -> osc.LoadNext()  (contenido de la wavetable, con crossfade)
// Voz monofonica con prioridad "ultima nota" y pila de notas pulsadas: al soltar
// una tecla se vuelve a la anterior que siga pulsada.
//
// MIDI: Keystep -> DIN -> Shield 6N138 -> USART1 (D13 Tx / D14 Rx).
//
// Los pines no se eligen aqui: vienen fijados por el trazado de la veroboard
// definitiva.
//
// Correspondencia pin fisico del Daisy -> argumento de hw.GetPin() (numeracion
// "D" de libDaisy). NO coinciden, y confundirlos es cablear otro pin:
//
//   fisico 22 (PC0)  A0  = D15  Attack       fisico 32 (PA0)  A10 = D25  Cutoff
//   fisico 23 (PA3)  A1  = D16  Decay        fisico 27 (PC1)  A5  = D20  Q
//   fisico 30 (PA4)  A8  = D23  Sustain      fisico 29 (PA5)  A7  = D22  Selector
//   fisico 31 (PA1)  A9  = D24  Release      fisico 21        3V3A (alimenta potes)
//   fisico 12 (PB8)  SCL = D11  OLED         fisico 13 (PB9)  SDA = D12  OLED
//
// (En la columna derecha del conector, fisico = D + 7. Verificado contra la
//  tabla seedgpio[] de libDaisy/src/daisy_seed.cpp.)
//
// Sobre ese reparto: los pines 33 y 34 son los UNICOS del bloque 29-35 sin canal
// de ADC. Los pines 29 y 30 son ademas DAC OUT 2 y DAC OUT 1, pero
// ConfigureDac() de libDaisy esta comentado entero, asi que seed.Init() no los
// reclama y quedan libres para el ADC (PA5/PA4/PA1/PA0 estan en adcpins[] de
// libDaisy/src/per/adc.cpp, canales 19, 18, 17 y 16). Los pines 24, 25, 28, 29
// y 30 son solo tolerantes a 3,3 V: los potes cuelgan de 3V3A, asi que no hay
// conflicto.
//
// Enlace SPI: S3 maestro, Daisy esclavo SPI_1 con DMA, 10 MHz, modo 0, MSB
// first. Trama de 2054 bytes:
//   byte 0..1     : header 0xDE 0xAD
//   byte 2..3     : seq_id  uint16 little-endian
//   byte 4..2051  : payload 1024 muestras int16 little-endian (Q15)
//   byte 2052..53 : CRC16/CCITT-FALSE sobre el payload, little-endian

#include "daisy_seed.h"
#include "daisysp.h"   // daisysp::Adsr, daisysp::Svf (DaisySP enlazada, -ldaisysp)
#include <cmath>       // powf, fabsf
#include <cstring>     // memcpy
#include <cstdio>      // snprintf (solo para las lineas del OLED)

using namespace daisy;

DaisySeed hw;

// Poner a 1 para volcar por USB serie las 1024 muestras de cada tabla recibida
// (WAVE_BEGIN..WAVE_END), para la validacion cruzada con 7_validate_spi.py.
// Se deja a 0: el uso normal es tocar MIDI mientras se mueve el timbre, y el
// volcado de 1024 lineas por trama ahogaria los logs MIDI del serie.
#define SPI_DEBUG_DUMP 0

// Volcado por serie de la tabla nota->Hz->phase_inc al arrancar (y cada 3 s),
// para 8_validate_midi.py. Poner a 0 para el uso normal del instrumento.
#define MIDI_SELFTEST 0

// Log por serie de cada Note On / Note Off en vivo (nota, Hz, phase_inc, notas
// pulsadas). Util para ver con el Keystep que la conversion es correcta.
#define MIDI_DEBUG 1

// Traza de arranque (una linea por fase de init) + latido cada 2 s con los
// contadores. Sin esto, un firmware colgado a mitad de main() y un firmware vivo
// sin entrada son INDISTINGUIBLES por el serie: los dos callan. La traza dice
// hasta donde llego el arranque; el latido distingue "vivo esperando" de "muerto".
#define HEARTBEAT 1

// Direccion I2C del OLED. Casi todos los SSD1306 de 0.96" son 0x3C; algunos
// clones vienen a 0x3D (suele ir serigrafiado o depender de un puente).
#define OLED_ADDR 0x3C

// --------------------------------------------------------------------------- //
// Configuracion
// --------------------------------------------------------------------------- //
static const int   TABLE_LEN   = 1024;     // muestras por ciclo (igual que el grid)
static const float SAMPLE_RATE = 48000.f;  // Hz, codec del Daisy (nominal)
static const float NOTE_HZ     = 220.f;    // tono por defecto antes del primer MIDI
static const float XFADE_MS    = 20.f;     // duracion del crossfade
// Ganancia de salida global. 0.8 para no tener que compensar con el previo de la
// interfaz: subir la ganancia aguas abajo amplifica senal Y ruido por igual,
// subirla aqui solo amplifica la senal. Sin riesgo de recorte: el crossfade es
// una media ponderada y no anade ganancia, asi que el pico maximo es 0.8.
static const float OUT_GAIN    = 0.8f;

// Envolvente ADSR (segundos / nivel 0..1). Son solo los valores de ARRANQUE: el
// ADSR queda gobernado por los cuatro potes en cuanto llega la primera lectura
// del ADC, unos milisegundos despues.
static const float ADSR_ATTACK  = 0.005f;  // 5 ms
static const float ADSR_DECAY   = 0.10f;   // 100 ms
static const float ADSR_SUSTAIN = 0.70f;   // 70 %
static const float ADSR_RELEASE = 0.20f;   // 200 ms

// Pila de notas pulsadas para la prioridad "ultima nota".
static const int MAX_HELD = 16;

// Suavizado de la ganancia de velocity, coeficiente de un polo por muestra
// (~5 ms a 48 kHz). Sin el, tocar una nota nueva mientras suena otra provoca un
// salto de ganancia sobre una senal que no esta en cero (el reataque es "soft",
// el ADSR no baja a 0) y eso se oye como un click.
static const float VEL_SMOOTH = 0.004f;


// --------------------------------------------------------------------------- //
// Motor wavetable: doble buffer + acumulador de fase + crossfade
// --------------------------------------------------------------------------- //
// MIDI solo llama a SetFreq(); LoadNext() lo llama el receptor SPI desde el bucle
// principal, y NextSample() corre en el callback de audio.
class Wavetable
{
  public:
    void Init(float sample_rate)
    {
        sample_rate_ = sample_rate;
        phase_       = 0.f;
        phase_inc_   = 0.f;
        xfade_pos_   = 1.f;   // 1.0 = solo tabla activa (sin crossfade en curso)
        xfade_inc_   = 1.f / (sample_rate_ * (XFADE_MS / 1000.f));
        std::memset(table_active_, 0, sizeof(table_active_));
        std::memset(table_next_,   0, sizeof(table_next_));
    }

    // Frecuencia de reproduccion (Hz). phase_inc_ en "muestras de tabla / muestra".
    void SetFreq(float hz) { phase_inc_ = hz * TABLE_LEN / sample_rate_; }

    void SetActiveNow(const int16_t* src)
    {
        std::memcpy(table_active_, src, sizeof(table_active_));
        xfade_pos_ = 1.f;
    }

    void LoadNext(const int16_t* src)
    {
        std::memcpy(table_next_, src, sizeof(table_next_));
        // Dispara el crossfade. Va el ULTIMO a proposito: el callback de audio
        // lee xfade_pos_ sin ningun bloqueo, y si se pusiera a 0 antes del
        // memcpy empezaria a mezclar una table_next_ a medio copiar.
        xfade_pos_ = 0.f;
    }

    float NextSample()
    {
        uint32_t idx0 = (uint32_t)phase_;
        uint32_t idx1 = (idx0 + 1) & (TABLE_LEN - 1);
        float    frac = phase_ - (float)idx0;

        float s_active = (table_active_[idx0] * (1.f - frac)
                        + table_active_[idx1] * frac) / 32768.f;

        float out;
        if(xfade_pos_ < 1.f)
        {
            float s_next = (table_next_[idx0] * (1.f - frac)
                          + table_next_[idx1] * frac) / 32768.f;
            out = s_active * (1.f - xfade_pos_) + s_next * xfade_pos_;

            xfade_pos_ += xfade_inc_;
            if(xfade_pos_ >= 1.f)
            {
                std::memcpy(table_active_, table_next_, sizeof(table_active_));
                xfade_pos_ = 1.f;
            }
        }
        else
        {
            out = s_active;
        }

        phase_ += phase_inc_;
        if(phase_ >= (float)TABLE_LEN) phase_ -= (float)TABLE_LEN;

        return out;
    }

  private:
    float   sample_rate_;
    int16_t table_active_[TABLE_LEN];
    int16_t table_next_[TABLE_LEN];
    float   phase_;
    float   phase_inc_;
    float   xfade_pos_;
    float   xfade_inc_;
};

Wavetable osc;


// Tabla senoidal de arranque. Sin esto las dos tablas quedan a cero tras Init() y
// el Daisy es MUDO hasta que llega la primera trama SPI valida del S3, aunque el
// MIDI funcione: un falso negativo caro de diagnosticar. Con ella, el Daisy es un
// instrumento autonomo (nota por MIDI, timbre senoidal) y el SPI solo *sustituye*
// el timbre. Solo carga el buffer activo antes de StartAudio.
static int16_t boot_wave[TABLE_LEN];

static void make_boot_wave()
{
    for(int n = 0; n < TABLE_LEN; ++n)
    {
        float ph      = 2.f * (float)M_PI * (float)n / (float)TABLE_LEN;
        boot_wave[n]  = (int16_t)(32767.f * sinf(ph));
    }
}


// --------------------------------------------------------------------------- //
// MIDI: USART1 -> voz monofonica last-note + ADSR
// --------------------------------------------------------------------------- //
MidiUartHandler midi;
daisysp::Adsr   env;

// Estado compartido loop <-> callback de audio. La escritura es de una sola
// palabra (bool / float dentro de SetFreq) y el callback solo lee: una carrera
// deja el cambio como mucho un bloque tarde (~1 ms), inaudible. El reataque del
// ADSR se aplaza a un flag para que TODA mutacion de env ocurra en el hilo de
// audio (Retrigger no es re-entrante con Process).
static volatile bool midi_gate          = false;  // true mientras haya tecla pulsada
static volatile bool midi_retrigger_req = false;  // pedir reataque del ADSR

// Ganancia pedida por la velocity de la nota que suena (0..1). La aplica el
// callback de audio a traves de un suavizado; ver VEL_SMOOTH.
static volatile float midi_vel_gain = 1.f;

// Pila de notas pulsadas (indice 0 = mas antigua, held_count-1 = cima = sonando).
// held_vels guarda la velocity de cada una EN PARALELO: al soltar una tecla y
// volver a la anterior hay que recuperar tambien su dinamica, no solo su tono.
static uint8_t held_notes[MAX_HELD];
static uint8_t held_vels[MAX_HELD];
static int     held_count = 0;

// Velocity MIDI (1..127) -> ganancia (0..1), curva cuadratica. Lineal repartiria
// casi todo el rango util en la mitad alta del recorrido de la tecla; al elevar al
// cuadrado, la dinamica se reparte de forma mas parecida a como se percibe la
// sonoridad. Para respuesta lineal, devolver v en vez de v*v.
static inline float vel_to_gain(uint8_t vel)
{
    float v = (float)vel / 127.f;
    return v * v;
}

// Contador de eventos MIDI de CUALQUIER tipo (incluidos los que se ignoran, como
// CC o reloj). Sirve para distinguir "no llega nada por el cable" de "llega pero
// no son notas": si esto sube al mover la rueda del Keystep, la cadena electrica
// funciona y el problema estaria en el tratamiento de las notas.
static volatile uint32_t midi_events = 0;

// Conversion nota MIDI -> Hz. Identica a daisysp::mtof (2^((m-69)/12)*440).
// UNICA fuente de verdad: la usan tanto el runtime como el volcado de MIDI_SELFTEST,
// asi que la tabla que valida 8_validate_midi.py es exactamente la del sonido real.
static inline float note_to_hz(int note)
{
    return 440.0f * powf(2.0f, ((float)note - 69.0f) / 12.0f);
}

// Quita una nota de la pila (si esta), compactando el hueco.
static void stack_remove(uint8_t note)
{
    for(int i = 0; i < held_count; ++i)
    {
        if(held_notes[i] == note)
        {
            for(int j = i; j < held_count - 1; ++j)
            {
                held_notes[j] = held_notes[j + 1];
                held_vels[j]  = held_vels[j + 1];
            }
            held_count--;
            return;
        }
    }
}

static void handle_note_off(uint8_t note);

static void handle_note_on(uint8_t note, uint8_t vel)
{
    if(vel == 0)  // Note On con velocity 0 = Note Off (running status)
    {
        handle_note_off(note);
        return;
    }

    stack_remove(note);                          // evita duplicados en la pila
    if(held_count < MAX_HELD)                    // nueva cima
    {
        held_notes[held_count] = note;
        held_vels[held_count]  = vel;
        held_count++;
    }

    float hz = note_to_hz(note);
    osc.SetFreq(hz);
    midi_vel_gain      = vel_to_gain(vel);
    midi_gate          = true;
    midi_retrigger_req = true;                    // reataque en CADA Note On nuevo

#if MIDI_DEBUG
    float pinc = hz * TABLE_LEN / SAMPLE_RATE;
    hw.PrintLine("# NOTE_ON  note=%d vel=%d hz_milli=%d pinc_micro=%d gain_milli=%d held=%d",
                 (int)note, (int)vel, (int)(hz * 1000.f + 0.5f),
                 (int)(pinc * 1e6f + 0.5f),
                 (int)(midi_vel_gain * 1000.f + 0.5f), held_count);
#endif
}

static void handle_note_off(uint8_t note)
{
    stack_remove(note);

    if(held_count > 0)
    {
        // Queda alguna tecla pulsada: volver a la mas reciente (cima). Cambio de
        // pitch SIN reatacar: la envolvente sigue en sustain (legato natural).
        // Se recupera tambien su velocity: al volver a ella debe sonar con la
        // dinamica con que se toco, no con la de la tecla que se acaba de soltar.
        uint8_t top = held_notes[held_count - 1];
        osc.SetFreq(note_to_hz(top));
        midi_vel_gain = vel_to_gain(held_vels[held_count - 1]);
        midi_gate     = true;
    }
    else
    {
        // Ninguna tecla: soltar el gate -> el ADSR entra en release.
        midi_gate = false;
    }

#if MIDI_DEBUG
    hw.PrintLine("# NOTE_OFF note=%d held=%d gate=%d",
                 (int)note, held_count, (int)midi_gate);
#endif
}

// Vacia la cola de eventos MIDI. Omni: no se filtra por canal (responde a todos).
static void midi_process()
{
    midi.Listen();
    while(midi.HasEvents())
    {
        MidiEvent m = midi.PopEvent();
        midi_events++;
        switch(m.type)
        {
            case NoteOn:
            {
                NoteOnEvent e = m.AsNoteOn();
                handle_note_on(e.note, e.velocity);
            }
            break;
            case NoteOff:
            {
                NoteOffEvent e = m.AsNoteOff();
                handle_note_off(e.note);
            }
            break;
            default: break;  // CC, pitch bend, etc.: fuera del alcance del MVP
        }
    }
}

static void midi_init()
{
    MidiUartHandler::Config c;
    // El Config por defecto ya usa USART_1 con rx=D14/tx=D13; se fijan explicito
    // por claridad y para que quede documentado en el propio codigo.
    c.transport_config.periph = UartHandler::Config::Peripheral::USART_1;
    c.transport_config.rx     = {DSY_GPIOB, 7};  // D14 (5V-tolerante -> 6N138 directo)
    c.transport_config.tx     = {DSY_GPIOB, 6};  // D13
    midi.Init(c);
    midi.StartReceive();
}

#if MIDI_SELFTEST
// Vuelca la tabla nota->Hz->phase_inc para las 128 notas MIDI, con la MISMA
// note_to_hz() y la MISMA sample rate que usa el runtime, para validar contra
// mtof en 8_validate_midi.py. Valores como enteros (el logger del Daisy no lleva
// %f fiable): hz en milihercios, phase_inc en micro-unidades.
static void dump_note_table(float sr)
{
    hw.PrintLine("NOTE_TABLE_BEGIN sr_milli=%d len=%d",
                 (int)(sr * 1000.f + 0.5f), TABLE_LEN);
    for(int n = 0; n < 128; ++n)
    {
        float hz   = note_to_hz(n);
        float pinc = hz * TABLE_LEN / sr;
        hw.PrintLine("%d %d %d",
                     n, (int)(hz * 1000.f + 0.5f), (int)(pinc * 1e6f + 0.5f));
    }
    hw.PrintLine("NOTE_TABLE_END");
}
#endif


// --------------------------------------------------------------------------- //
// Recepcion SPI: esclavo SPI_1 + DMA
// --------------------------------------------------------------------------- //
static const int SPI_SAMPLES   = 1024;
static const int SPI_PAYLOAD   = SPI_SAMPLES * 2;   // 2048 bytes
static const int SPI_FRAME_LEN = SPI_PAYLOAD + 6;   // 2054 bytes (header+seq+crc)

SpiHandle spi;

static uint8_t DMA_BUFFER_MEM_SECTION spi_rx_buffer[SPI_FRAME_LEN];
static int16_t spi_wave[SPI_SAMPLES];

static volatile bool     spi_dma_done = false;
static volatile uint32_t spi_frames   = 0;

void OnSpiComplete(void* context, SpiHandle::Result result);

static uint16_t crc16_ccitt(const uint8_t* data, int len)
{
    uint16_t crc = 0xFFFF;
    for(int i = 0; i < len; ++i) {
        crc ^= (uint16_t)data[i] << 8;
        for(int b = 0; b < 8; ++b)
            crc = (crc & 0x8000) ? (uint16_t)((crc << 1) ^ 0x1021)
                                 : (uint16_t)(crc << 1);
    }
    return crc;
}

void OnSpiComplete(void* context, SpiHandle::Result result)
{
    (void)context;
    if(result == SpiHandle::Result::OK)
        spi_dma_done = true;
    else
        spi.DmaReceive(spi_rx_buffer, SPI_FRAME_LEN, nullptr, OnSpiComplete, nullptr);
}
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
int main(void)
{
    hw.Init();
    hw.SetAudioBlockSize(48);
    hw.StartLog(false);   // USB serie para depurar (no espera al PC)

#if HEARTBEAT
    // 3 parpadeos: prueba de vida VISIBLE, sin depender del PC ni del serie.
    for(int i = 0; i < 3; ++i)
    {
        hw.SetLed(true);  System::Delay(120);
        hw.SetLed(false); System::Delay(120);
    }
    hw.PrintLine("=== SintetizadorEspacioLatente (S8 + bloque B) ===");
#define TRACE(msg) hw.PrintLine("# init " msg)
#else
#define TRACE(msg)
#endif

    osc.Init(hw.AudioSampleRate());
    osc.SetFreq(NOTE_HZ);   // pitch por defecto; gate=false -> en silencio hasta el 1er MIDI

    // Timbre de arranque: senoidal, hasta que el S3 mande la primera wavetable.
    make_boot_wave();
    osc.SetActiveNow(boot_wave);
    TRACE("osc ok");

    env.Init(hw.AudioSampleRate());
    env.SetAttackTime(ADSR_ATTACK);
    env.SetDecayTime(ADSR_DECAY);
    env.SetSustainLevel(ADSR_SUSTAIN);
    env.SetReleaseTime(ADSR_RELEASE);
    TRACE("env ok");

    // Filtro. Arranca abierto y sin resonancia; el primer bloque de audio ya lo
    // pone donde digan los mandos.
    filt.Init(hw.AudioSampleRate());
    filt.SetFreq(CUTOFF_MAX);
    filt.SetRes(0.f);
    filt.SetDrive(0.f);
    TRACE("filtro ok");

    // Despues de env.Init(): controls_init() deja ctrl[] en el valor real de cada
    // pote, y el primer bloque de audio escribe el ADSR encima de las constantes
    // de arranque.
    controls_init();
    for(int i = 0; i < POT_COUNT; ++i)
        focus_ref[i] = ctrl[i];   // que el arranque no cuente como "mando movido"
    TRACE("potes ok");

    midi_init();
    TRACE("midi ok");

    spi_slave_init();
    TRACE("spi ok");

    // Antes de StartAudio: el driver de I2C bloquea, y es preferible que un
    // display mal cableado se note en el arranque y no como cortes en un audio
    // que ya esta sonando. Si no contesta, el instrumento sigue funcionando.
    oled_bus_recover();
    oled_present = oled_probe();
    if(oled_present)
    {
        oled_init();
        TRACE("oled ok");
    }
    else
    {
        TRACE("oled AUSENTE -- se sigue sin display");
    }

    hw.StartAudio(AudioCallback);
    TRACE("audio ok -- arranque completo");

#if MIDI_SELFTEST
    dump_note_table(hw.AudioSampleRate());
    uint32_t last_dump = System::GetNow();
#endif
    uint32_t last_blink = System::GetNow();
#if HEARTBEAT
    uint32_t last_beat = System::GetNow();
#endif
    uint32_t last_oled = System::GetNow();

    while(true)
    {
        // MIDI: pitch/gate de la voz monofonica.
        midi_process();

        // SPI: una trama lista -> validar y (si procede) crossfade de timbre.
        if(spi_dma_done)
            spi_process_frame();

#if MIDI_SELFTEST
        // Re-volcar la tabla cada 3 s para que la captura de serie siempre pille
        // un bloque completo, sin depender de cuando se abra el terminal.
        if(System::GetNow() - last_dump >= 3000)
        {
            dump_note_table(hw.AudioSampleRate());
            last_dump = System::GetNow();
        }
#endif

#if HEARTBEAT
        // Latido cada 2 s: prueba de vida del bucle principal aunque no entre
        // nada. Lleva los contadores para ver de un vistazo que subsistema recibe.
        if(System::GetNow() - last_beat >= 2000)
        {
            hw.PrintLine("# vivo midi_ev=%u spi_frames=%u gate=%d held=%d",
                         (unsigned)midi_events, (unsigned)spi_frames,
                         (int)midi_gate, held_count);
            last_beat = System::GetNow();
        }
#endif

        // Panel: seguir al mando que se este girando y refrescar el display. El
        // foco se actualiza SIEMPRE (es una comparacion de siete floats), pero
        // oled_draw() se autolimita: si no ha cambiado nada de lo que se ve, sale
        // sin tocar el bus y el bucle no se bloquea.
        focus_update();
        if(oled_present && System::GetNow() - last_oled >= OLED_PERIOD_MS)
        {
            const uint32_t t0 = System::GetNow();
            oled_draw();

            // Si el refresco se ha eternizado es que el bus esta colgado. A la
            // tercera, el display se desconecta y el instrumento sigue.
            if(System::GetNow() - t0 > OLED_STALL_MS
               && ++oled_stalls >= OLED_STALL_MAX)
                oled_present = false;

            last_oled = System::GetNow();
        }

        // Apagar el LED 100 ms despues del ultimo parpadeo de trama SPI valida.
        if(System::GetNow() - last_blink >= 100)
        {
            hw.SetLed(false);
            last_blink = System::GetNow();
        }

        System::Delay(1);
    }
}

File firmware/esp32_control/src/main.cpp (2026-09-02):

// main.cpp - Firmware del ESP32-S3: genera la wavetable por interpolacion
// bilineal del grid y, tras cada toque, la envia al Daisy por SPI y la devuelve
// diezmada a la CYD para que la dibuje.
//
// Entradas:
//   1) UART en GPIO18  <- trama de 6 bytes de la CYD (entrada real).
//   2) Texto "x y" por USB (Serial0) <- util para depurar sin la CYD.
//
// Salidas:
//   - Por USB (Serial0): verificacion (celda+pesos, resumen, volcado WAVE_*).
//   - Por SPI (maestro): la wavetable de 1024 muestras al Daisy.
//   - Por UART en GPIO17: 256 puntos int8 a la CYD, SOLO para pintar.

#include <Arduino.h>
#include <math.h>
#include "interpolation.h"
#include "uart_receiver.h"
#include "spi_sender.h"
#include "wave_sender.h"

#define CYD_RX_PIN   18        // pin del S3 por el que entra el UART de la CYD
#define CYD_TX_PIN   17        // pin del S3 hacia la CYD (canal de vuelta, IO35)
#define CYD_UART_BAUD 460800   // tiene que coincidir con el Serial1 de la CYD

// Pines SPI del S3 hacia el Daisy (FSPI nativo del S3, libres del flash/PSRAM
// octal del N16R8 y del UART de la CYD en GPIO18).
#define SPI_SCK_PIN  12
#define SPI_MOSI_PIN 11
#define SPI_MISO_PIN 13        // sin uso (Daisy en RX_ONLY), cableado por coherencia
#define SPI_CS_PIN   10

static int16_t g_wave[TABLE_LEN];   // wavetable interpolada actual (RAM, ~2 KB)
static bool    g_have_wave = false;
static String  g_input;             // acumula la linea tecleada por USB

static void print_stats()
{
    long   vmin = 32767, vmax = -32768;
    double sumsq = 0.0;
    for (int n = 0; n < TABLE_LEN; ++n) {
        int v = g_wave[n];
        if (v < vmin) vmin = v;
        if (v > vmax) vmax = v;
        sumsq += (double)v * (double)v;
    }
    double rms = sqrt(sumsq / TABLE_LEN);
    Serial0.printf("# min=%ld max=%ld rms=%.1f  s[0]=%d s[%d]=%d\n",
                   vmin, vmax, rms, g_wave[0], TABLE_LEN - 1, g_wave[TABLE_LEN - 1]);
}

static void dump_wave()
{
    Serial0.println("WAVE_BEGIN");
    for (int n = 0; n < TABLE_LEN; ++n)
        Serial0.println(g_wave[n]);
    Serial0.println("WAVE_END");
}

// 'src' identifica de donde vino la coordenada: "UART" (CYD) o "USB" (teclado).
static void handle_coords(uint16_t x, uint16_t y, const char* src)
{
    GridLocation loc = interpolate_wavetable(x, y, g_wave);
    g_have_wave = true;
    // Confirmacion corta: coordenada recibida + celda/pesos usados.
    Serial0.printf("# [%s] coord=(%u,%u)  celda X[%d->%d] fx=%.3f  Y[%d->%d] fy=%.3f\n",
                   src, x, y, loc.ix0, loc.ix1, loc.fx, loc.iy0, loc.iy1, loc.fy);
    // Enviar la wavetable recien calculada al Daisy por SPI.
    uint16_t seq = spi_send_wavetable(g_wave);
    Serial0.printf("# SPI enviado seq=%u (%d muestras)\n", seq, TABLE_LEN);
    // Y de vuelta a la CYD, la misma onda diezmada para que la pinte.
    uint16_t wseq = wave_send(g_wave, TABLE_LEN);
    Serial0.printf("# UART onda -> CYD seq=%u (%d puntos int8)\n", wseq, WAVE_TX_POINTS);
    Serial0.println("tabla encontrada");
    // (El volcado de las 1024 muestras sigue disponible bajo demanda: escribe
    //  "dump" por USB; "stat" para solo el resumen min/max/rms.)
}

// --- Procesa una linea de texto del USB ("x y", "dump", "stat") --------------
static void process_line(String line)
{
    line.trim();
    if (line.length() == 0) return;

    if (line.equalsIgnoreCase("dump")) {
        if (g_have_wave) dump_wave();
        else Serial0.println("# aun no hay wavetable; envia una coordenada primero");
        return;
    }
    if (line.equalsIgnoreCase("stat")) {
        if (g_have_wave) print_stats();
        else Serial0.println("# aun no hay wavetable");
        return;
    }

    int sep = line.indexOf(' ');
    if (sep < 0) {
        Serial0.println("# formato: \"x y\"  (0..65535 cada uno)");
        return;
    }
    long x = line.substring(0, sep).toInt();
    long y = line.substring(sep + 1).toInt();
    if (x < 0) x = 0; else if (x > 65535) x = 65535;
    if (y < 0) y = 0; else if (y > 65535) y = 65535;
    handle_coords((uint16_t)x, (uint16_t)y, "USB");
}

void setup()
{
    Serial0.begin(115200);
    delay(300);
    Serial0.println();
    Serial0.println("=== S3 bilinear + SPI (sesion 7) ===");
    Serial0.printf("Grid %dx%d, TABLE_LEN=%d\n", GRID_SIZE, GRID_SIZE, TABLE_LEN);
    Serial0.printf("UART con la CYD: RX=GPIO%d  TX=GPIO%d  @%u baud\n",
                   CYD_RX_PIN, CYD_TX_PIN, CYD_UART_BAUD);
    Serial0.println("Entradas: UART desde la CYD  |  texto \"x y\" por USB");
    Serial0.printf("SPI maestro -> Daisy: SCK=%d MOSI=%d MISO=%d CS=%d @10MHz modo0\n",
                   SPI_SCK_PIN, SPI_MOSI_PIN, SPI_MISO_PIN, SPI_CS_PIN);

    // UART fisico con la CYD en los dos sentidos: recibimos la coordenada por
    // GPIO18 y devolvemos la onda para pintar por GPIO17.
    uart_rx_begin(CYD_RX_PIN, CYD_TX_PIN, CYD_UART_BAUD);

    // SPI maestro hacia el Daisy.
    spi_tx_begin(SPI_SCK_PIN, SPI_MISO_PIN, SPI_MOSI_PIN, SPI_CS_PIN);
}

void loop()
{
    // 1) Coordenada desde la CYD por UART (entrada real).
    uint16_t ux, uy;
    if (uart_rx_poll(&ux, &uy)) {
        handle_coords(ux, uy, "UART");
    }

    // 2) Texto por USB (depuracion). Acepta '\n', '\r' o '\r\n'.
    while (Serial0.available()) {
        char c = (char)Serial0.read();
        if (c == '\n' || c == '\r') {
            if (g_input.length() > 0) {
                process_line(g_input);
                g_input = "";
            }
        } else {
            g_input += c;
        }
    }
}

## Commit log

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2026-07-12 Sesion 6: tactil CYD + interpolacion bilineal en el S3
    Cierra la cadena de entrada hasta el S3: la CYD lee el XPT2046 y envia
    coordenadas por UART (6 bytes, header+checksum); el S3 las recibe con una
    maquina de estados autosincronizante y calcula la wavetable interpolando
    bilinealmente las 4 celdas vecinas del grid 16x16. El S3 aun no envia nada
    por SPI (eso es la sesion 7); esta interpolacion queda validada frente a
    una referencia en numpy (6_validate_s3.py), error maximo de 1 LSB en Q15.
    [6_validate_s3.py, main.cpp, uart_receiver.cpp]
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2026-07-12 Sesion 8 (continua): diagnostico y resolucion del bloqueo MIDI (shield sin 5V)
    Sesion NO cerrada. Se anadio firmware de aislamiento
    firmware/daisy_dsp/midi_shield_test.cpp (solo MIDI, sin audio/SPI) para
    descartar el firmware como causa del silencio MIDI. Confirmado: el shield
    en si funciona (Keystep -> shield -> D14 con NOTE_ON/OFF correctos) una vez
    alimentado con 5V reales desde una fuente de laboratorio; ni el VIN del
    Daisy ni el del ESP32-S3 (~2V) entregaban 5V, y 3.3V no bastaba para el
    6N138.
    Pendiente para cerrar S8: reflashear el Daisy con el firmware completo
    (SintetizadorEspacioLatente.cpp, no el de test), montar CYD+SPI+MIDI+Daisy
    juntos y confirmar que suena con ambos controles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
    [midi_shield_test.cpp]
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2026-08-15 Veroboard: mapa de cortes del Daisy y regla de los dos lados
    Confirmado sobre la placa real: las pistas corren a lo largo de los 160 mm,
    o sea 39 tiras de 63 agujeros.
    Corregido un calculo mal planteado: los 42 tiras que pedian Daisy (20) y S3
    (22) frente a 39 disponibles NO son un problema. Los modulos no necesitan
    tiras propias, van en posiciones distintas a lo largo de las tiras y un
    corte entre bloques los separa. El limite real es el modulo mas ancho (22)
    sobre 37 tiras de senal. Una sola placa de 100x160 es holgada.
    Anadido el mapa de colisiones completo del Daisy: con el modulo
    perpendicular a las tiras, la tira k une el pin k con el pin 41-k. Los 20
    cortes son obligatorios y cinco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
    [sistema-midi-cyd-daisy-VEROBOARD.fzz, sistema-midi-cyd-daisy.BACKUP.fzz, sistema-midi-cyd-daisy.fzz]
2026-08-15 Veroboard completa: filtro corregido, bulk, puentes y 53 cortes
    Completado el .fzz de la veroboard sobre el que ya estaban colocados el
    Daisy (filas 19-38, cols 38/44) y el ESP32-S3 (filas 0-21, cols 0/10).
    Fichero nuevo, el de partida no se toca.
    Formato decodificado: la propiedad buses de la stripboard es la lista de
    CORTES (los 2394 'v' son todos los enlaces verticales, correctos para
    tiras horizontales); los IDs de conector son connector{fila}{col:03d}; y
    el agujero (fila,col) cae en el pixel (405+9*col, -495+9*fila).
    Tres defectos corregidos del fichero de partida:
    - El filtro estaba una fila desplazado: su entrada caia en la fila 21,
    que es el 3V3D del Daisy, y su salida nunca lleg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
    [sistema-midi-cyd-daisy-VEROBOARD-COMPLETO.fzz]
2026-08-16 Veroboard FINAL: panel completo (potes, selector, OLED, jack, CYD, MIDI, D1)
    Anadidos fuera de la placa y unidos con cables que salen de ella:
    - 6 potenciometros rotativos de 9 mm (A D S R Cutoff Q): pata1 a 3V3A,
    cursor a su pin de ADC del Daisy, pata2 a la AGND llevada a la fila 24.
    - Selector de tipo de filtro al pin 28. La libreria de Fritzing no trae
    SP3T, asi que la pieza es un SPDT como marcador; el divisor de tres
    niveles esta especificado en docs/veroboard.md.
    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
    [sistema-midi-cyd-daisy-VEROBOARD-FINAL.fzz]
2026-08-16 Veroboard: trazado limpio, railes de 5V y GND, sin telarana
    Rehecho el trazado entero con las reglas que faltaban:
    - Un agujero, una sola conexion. Antes los seis potes compartian agujero
    para 3V3A y para AGND. Ahora cada uno tiene el suyo (columnas 48 a 58).
    - Nada por debajo del cuerpo de los modulos: el script aborta si algun
    extremo cae en las columnas 1-9 (S3) o 39-43 (Daisy).
    - Rail de +5V en la fila 1 y de GND en la fila 0, recorriendo de la
    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
    [sistema-midi-cyd-daisy-VEROBOARD-FINAL.fzz]
2026-08-16 Veroboard: polaridad, D1 y limpieza de los cables heredados
    Cuatro correcciones sobre la revision anterior:
    - Electroliticos aparentemente invertidos. La causa no era la polaridad
    electrica (connector0 = negativo, connector1 = positivo, y estaba bien)
    sino el dibujo: el offset esta medido respecto al agujero del
    connector0 y yo posicionaba la pieza con la fila del connector1, asi
    que salia desplazada una fila y se leia al reves.
    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
    [sistema-midi-cyd-daisy-VEROBOARD-FINAL.fzz]
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2026-08-20 Bloque B: potes (ADSR + filtro Svf), selector y OLED en el Daisy
    Panel de control analogico montado CONTRA el pinout ya fijado en
    docs/veroboard.md seccion 2, no al reves.
    - 7 canales de ADC1: A, D, S, R (pines fisicos 22-25), cutoff y Q
    (26-27) y selector de tipo de filtro (28). Potes alimentados desde
    3V3A (pin 21), nunca desde el rail de 5 V.
    - Filtro daisysp::Svf en la cadena: osc -> Svf -> ADSR (VCO-VCF-VCA).
    El Svf calcula las cuatro salidas a la vez, asi que LPF/BPF/HPF por
    el selector cuesta cero CPU.
    - Suavizado de un polo (~30 ms) sobre los siete canales, aplicado una
    vez por bloque de audio: es lo que elimina el zipper noise del cutoff.
    - Toda mutacion de env y filt ocu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
    [SintetizadorEspacioLatente.cpp]
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2026-08-21 Trazado definitivo verificado contra el .fzz: 53 cortes, no 62
    Los tres cortes de aislamiento del 6quinquies no cuadraban. Decodificado
    el .fzz hueco a hueco (propiedad buses del stripboard + los 44 cables) y
    resulta que el 6ter usa una numeracion de tiras que nunca llego a la
    placa: el Fritzing del 16 de agosto fijo otro convenio, mejor, y el
    6quinquies se dedujo el 20 sobre los numeros viejos.
    Convenio real: tira 1 = GND, tira 2 = +5 V, Daisy en las tiras 20-39 con
    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
    [sistema-midi-cyd-daisy-VEROBOARD-FINAL-v2.fzz]
2026-08-21 Bloque D a medias: 57 cortes hechos y verificados, nada soldado
    La placa esta cortada, taladrada y comprobada uno a uno en las dos
    direcciones. Zocalos cortados a 2x20 y 2x22. Se para en el punto de
    parada pactado; la protoboard sigue intacta como respaldo.
    El hallazgo del dia no fue electrico sino documental: veroboard.md
    6ter y 6quinquies estaban obsoletos contra el propio Fritzing, que el
    16 de agosto fijo otro convenio de tiras. Los tres "cortes que
    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
    [sistema-midi-cyd-daisy-VEROBOARD-FINAL-SOLO-BAQUELITA.fzz, sistema-midi-cyd-daisy-VEROBOARD-FINAL-v2.fzz]
2026-08-22 Trazado en espejo: se adapta la placa y cambia el mapa de pines de los potes
    El layout se calco sobre la cara de cobre en vez de la de baquelita, asi
    que la placa salio en espejo. No se puede compensar girando los modulos:
    un conector de dos filas tiene quiralidad. Decision: adaptarse, no
    rehacer. Trazado nuevo en FINAL-flipped.fzz.
    Los cortes ya taladrados en las tiras 23-27 obligan a mover cuatro
    cursores, asi que Sustain, Release, Cutoff y el selector cambian de pin
    del Daisy y hay que reflashear.
    Hallazgo del datasheet: el pin 33 no tiene ADC. El cursor de Q habia
    caido ahi y no habria leido nada; vuelve al pin 27.
    [sistema-midi-cyd-daisy-VEROBOARD-COMPLETO.fzz, sistema-midi-cyd-daisy-VEROBOARD-FINAL-SOLO-BAQUELITA.fzz, sistema-midi-cyd-daisy-VEROBOARD-FINAL-flipped - solo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]
2026-08-22 Trazado espejado cerrado: 4 cortes nuevos y el mapa de potes definitivo
    Verificado el .fzz flipped pin a pin contra el netlist. Las cuentas de
    cortes cierran: el dibujo pide 58 perforaciones, la placa tiene 57, y
    54 del dibujo ya estaban taladradas. Los 4 nuevos son las tiras 1 y 2
    en el agujero 46 (aislan los railes de los GPIO del S3) y las tiras 33
    y 34 en el 30 (railes locales del filtro).
    Quedan tres cortes en la placa que el dibujo no muestra. Dos son
    inofensivos; el de la tira 28 deja R5 fuera del nodo del selector y se
    corrige llevandola a t28/p22.
    Q resuelta en la tira 26 (pin 27, A5) compartiendo agujero con C15, que
    puentea el corte entre la isla de masa y el pin. Se evita asi e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
    [sistema-midi-cyd-daisy-VEROBOARD-FINAL-flipped.fzz]
2026-08-22 Los tres cortes ocultos, incorporados al trazado, y R5 a salvo
    Localizados sobre el cobre los tres cortes que la placa tenia y el
    dibujo espejado no conocia: tira 32 en el agujero 15, tira 28 en el 20 y
    la tira 17 en la linea de separacion del 49. Los tres estan ahora en el
    .fzz, asi que el plano describe por fin la placa real.
    El de la tira 28 era el unico que hacia dano: dejaba R5 fuera del nodo
    del selector y la posicion central se habria quedado sin divisor. R5
    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
    [sistema-midi-cyd-daisy-VEROBOARD-FINAL-flipped.fzz]
2026-08-22 Placa soldada entera salvo el mazo; el bloque C pasa al camino critico
    Todo lo que va sobre la veroboard esta puesto: 61 cortes, zocalos, los
    cuatro puentes del SPI por baquelita, los siete enlaces de alimentacion
    y masa por la cara de cobre, resistencias, diodo, ocho ceramicos y tres
    electroliticos.
    Dos incidencias resueltas. Un corto entre los pines 13 y 14 del Daisy al
    soldar el zocalo, que resulto ser una rebaba de cobre del taladrado y no
    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
    [sistema-midi-cyd-daisy-VEROBOARD-FINAL-flipped - soldar.fzz, sistema-midi-cyd-daisy-VEROBOARD-FINAL-flipped - solo baquelitaa.fzz, sistema-midi-cyd-daisy-VEROB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]
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2026-08-25 Bloque C: el panel cerrado y validado en probetas
    panel.scad, caja.scad y conjunto.scad. Panel de 186x116x3,4 con los seis
    potes, el selector, la CYD y el OLED. Todas las cotas criticas validadas
    imprimiendo probetas en vez de calculando.
    - Potes M7x0,75; la espiga antigiro es una pletina de 2,8x1,2, no redonda,
    y va a 180 para que las patillas no choquen con el pote vecino.
    - CYD girada 180 (USB-C lejos del OLED): hay que girar la imagen en firmware.
    Rebaje con descarga en las esquinas, que era por lo que no asentaba.
    - OLED de 26x26 en tres niveles, con canal continuo para el flex.
    - Etiquetas en relieve: el grabado no se leia.
    El video del shield MIDI demostro que va TUMBADO, no de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
    [caja.scad, conjunto.scad, oled_frame.stl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]
2026-08-26 Bloque C: la caja partida en tres piezas, y el resumen de sesion
    PROJECT.md documenta el diseno de caja.scad: el shield MIDI va tumbado y
    eso fijo el fondo de la caja, la linea de particion se desacoplo del borde
    del panel, y las tres piezas se orientan para imprimirse sin soportes.
    Todas las uniones van contra tuerca embutida y las tolerancias quedan
    como parametros con nombre.
    Se anaden los resumenes de sesion de memoria/resumen_sesiones, con el
    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
    [caja.scad, panel.scad]
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2026-08-27 Memoria: colocacion de figuras y eliminacion de paginas en blanco
    Cuatro ajustes de maquetacion sobre la plantilla:
    - openany en la clase. book arrancaba cada capitulo en pagina impar e
    insertaba una pagina en blanco cuando el anterior acababa en impar.
    Eran seis paginas vacias.
    - Contador de pagina de -2 a -1, para que el capitulo 1 siga cayendo en
    la pagina 1 tras quitar esas paginas en blanco.
    - Parametros de flotantes relajados. Los de fabrica exigen que un 20 por
    ciento de la pagina sea texto, lo que empujaba las figuras varias
    paginas mas alla de donde se citan.
    - placeins con la opcion section. Es el arreglo de fondo: sin el, una
    figura podia flotar hasta dentro de la sec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
2026-08-27 Memoria: revertir openany, las paginas impares eran intencionadas
    Los capitulos empezando en pagina impar y las paginas en blanco que eso
    genera son el comportamiento correcto de book con openright, la
    convencion de un documento a doble cara. Se revierte openany y el
    contador de pagina vuelve a -2.
    Se mantienen los dos arreglos que si resolvian un problema real: los
    parametros de flotantes relajados y placeins, que impide que una figura
    se cuele en una seccion posterior a la que la cita.
    memory.md deja anotado que ese comportamiento es intencionado, para no
    volver a "arreglarlo".
2026-08-27 CYD: calibrar el tactil en banco y separar ventana visible de ventana de captura
    Calibracion medida con la placa ya montada en la carcasa: el area util real es
    450..3730 en los dos ejes. La prediccion geometrica hecha sobre el papel (3,75 mm
    de recorte por la izquierda, nada en vertical) no resistio el banco. Se descarto
    ajustar esquina por esquina: las dos lecturas de arriba no coincidian en Y (480
    a la izquierda, 250 a la derecha), senal de que el tactil esta un poco girado
    respecto al hueco, y un mapeo rectangular no puede corregir un giro.
    El problema de fondo eran las pulsaciones fantasma del labio impreso, que apoya
    sobre el cristal en todo el perimetro. Filtrar por ventana no bastaba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
    [main.cpp]
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2026-08-28 Memoria: capitulo 5, firmware de control
    Capitulo 5 redactado y compilado, paginas 29 a 35, las 7 presupuestadas.
    Seis secciones: lectura y calibracion del tactil, de la coordenada a la
    celda, interpolacion bilineal, envio por SPI, canal de vuelta y dibujo, y
    estado del subsistema. Las dos validaciones cuantitativas (error Q15 y
    error SPI) se dejan para el capitulo 8; aqui solo va el metodo.
    Tres figuras nuevas por script, con datos reales:
    - fig_ventanas: las dos ventanas del tactil sobre el plano crudo, con la
    pulsacion fantasma medida en (3714, 643).
    - fig_bilineal: la celda, los cuatro pesos y la onda que sale.
    - fig_diezmado: promediar frente a no promediar al reducir a 256 puntos.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
2026-08-28 Congelar el codigo y anotar la version de la libreria del tactil
    Queda congelado el codigo: no se edita ni una linea de firmware/ ni de ml/,
    incluidos los platformio.ini, los Makefiles y los comentarios. Si al
    documentar aparece una discrepancia entre el codigo y lo que se creia, se
    anota en la memoria, no se corrige el codigo. Lo flasheado es la verdad de
    referencia y el hardware deja de estar disponible el 2 de septiembre. Sigue
    siendo editable memoria/, incluidos los guiones de figuras.
    La libreria del tactil se cita como 1.4 y ahi se queda, que es la version
    que declara la que esta instalada y flasheada (comprobado en su
    library.properties dentro de .pio/libdeps). Di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
2026-08-28 Memoria: capitulo 6, firmware de audio
    Ocho secciones sobre el codigo congelado del Daisy Seed: el acumulador de
    fase sobre tablas Q15, la recepcion de la trama por DMA con la validacion
    fuera de la interrupcion, el crossfade de 20 ms, la voz monofonica MIDI con
    pila de ultima nota, el panel de siete canales de ADC con el filtro Svf, el
    display y la instrumentacion de arranque. 9 paginas, de la 37 a la 45, una
    mas de las 8 presupuestadas y aceptada como tal.
    No se toca nada de firmware/ ni de ml/. Al documentar aparecieron tres
    discrepancias entre el codigo y sus propios comentarios, anotadas en
    PROJECT.md y en memory.md 4sexies pero NO corregidas, y la memoria escribe
    la version correcta: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
2026-08-29 Memoria: revision del capitulo 3
    Retoques del autor sobre todo el capitulo, mas tres arreglos: la sigla GPU
    pasa a \gls (con su entrada nueva en siglas.tex), se recupera el motivo por
    el que dos celdas vecinas se parecen (son dos puntos proximos de una misma
    funcion continua y suave) y se acorta el ultimo parrafo de 3.6.
    En la figura del pipeline, "Corpus AKWF" pasa a "Dataset AKWF".
    Sigue ocupando sus 6 paginas, de la 13 a la 18.
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2026-08-31 Memoria: revision del capitulo 4
    Correcciones del autor sobre el texto, y dos arreglos en las figuras.
    El umbral del fallback de alineacion decia lo contrario de lo que hace:
    caer por debajo de 1e-3 significa que la fundamental NO esta claramente
    diferenciada, que es justo por lo que esas ondas se dejan sin rotar.
    Recuperadas tambien las carpetas de ruido en la lista de familias
    afectadas, que son el caso principal.
    Figura de reconstrucciones: la leyenda tapaba la onda del primer panel,
    pasa a ir centrada bajo los cuatro.
    Figura del espacio latente: fuera las cruces de los nodos de la rejilla.
    En ese punto de la narrativa la rejilla todavia no se ha presentado, asi
    que no pintaban nada ah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
2026-08-31 Memoria: capitulo 7, hardware y alimentacion
    Borrador del capitulo 7 en cinco secciones: componentes y equipos, la
    alimentacion (quien fija el minimo del rail, el arranque, el filtro de la
    rama de audio y el reparto de masas con dos fuentes), la placa
    concentradora, el panel de control y la carcasa. Ocupa de la pagina 47 a
    la 54, dentro de sus 8 paginas presupuestadas.
    Anadida al indice de memoria/manuales la hoja del 6N138 de Vishay, con una
    precision que corrige lo que se venia arrastrando: esa hoja no tiene tabla
    de condiciones recomendadas, asi que no existe un minimo de 4,5 V como tal.
    Lo que hay es que sus parametros garantizados estan especificados con
    VCC = 4,5 V, y esa es la forma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
    [sistema-midi-cyd-daisy-VEROBOARD-FINAL-flipped.fzz]
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2026-09-02 Firmware y hardware: estado final flasheado e impreso
    El .cpp del Daisy es la version compilada y grabada el 1 de septiembre, que
    es la que describe la memoria: umbral de foco al 3 %, vigilante del refresco
    del OLED, los tres tiempos del ADSR en escala lineal y el display con
    graficas de envolvente y de filtro en lugar del numero grande.
    conjunto.scad se sincroniza con caja.scad en h_front y bay_d para que el
    render del despiece salga correcto; no genera ninguna pieza, asi que no
    altera nada de lo impreso. Se anade tambien el .fzz del trazado espejado.
    [conjunto.scad, sistema-midi-cyd-daisy-VEROBOARD-FINAL-flipped.fzz]
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2026-10-05 Repo: sacar memoria/ y subir la memoria final en PDF
    Las fuentes LaTeX, figuras y logos de la memoria pasan a quedarse solo en
    local; en el repositorio va el PDF final con la portada oficial
    (memoria_tfg.pdf). El README gana fotos del instrumento y las figuras
    principales (docs/img/), una seccion de hardware y corrige el nombre del
    grado y el tamano del corpus.
